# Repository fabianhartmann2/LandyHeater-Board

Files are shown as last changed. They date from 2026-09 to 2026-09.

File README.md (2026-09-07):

# LandyHeater Board

Hardwareentwicklung für das Landy-Heater-Steuergerät auf Basis des `ESP32-S3-WROOM-1U-N16R8`.

## Aktueller Stand

Revision A hat Phase 0 und Phase 1 abgeschlossen. Der Phase-2-Schaltplan wurde nach dem zurückgewiesenen rasterartigen Erstentwurf grundlegend als zusammenhängender Engineering-Schaltplan neu aufgebaut. Alle sieben A4-Seiten wurden aus dem KiCad-Export einzeln visuell geprüft; lokale Funktionsnetze werden mit sichtbaren Leitungen dargestellt. ERC, Struktur-Audit und der elektrische Vorher-/Nachher-Netzlistenvergleich sind fehlerfrei. Die normative Grundlage ist Dokumentversion 1.6. Phase 2 bleibt wegen der im Review dokumentierten Mess-, Transienten-, FPC- und Footprint-Gates sowie der noch ausstehenden ausdrücklichen Abnahme **nicht freigegeben**; Phase 3 wurde nicht begonnen.

- [Hardware-Anforderungsspezifikation Revision A](docs/Hardware-Anforderungsspezifikation_Revision_A.md)
- [Ergebnisbericht Phase 0](docs/Phase_0_KiCad-Arbeitsumgebung.md)
- [Phase 1 – Architektur und Bauteilfestlegung](docs/Phase_1_Architektur-und-Bauteilfestlegung.md)
- [Phase 2 – KiCad-Schaltplan und Review](docs/Phase_2_Schaltplanreview.md)
- [Phase 2 – Anforderungs- und Schnittstellenliste](docs/Phase_2_Anforderungs-und-Schnittstellenliste.md)
- [Phase 2 – Quellen und Rückverfolgbarkeit](docs/Phase_2_Quellen-und-Rueckverfolgbarkeit.md)
- [GPIO-Matrix Revision A](docs/GPIO-Matrix_Revision_A.md)
- [Leistungs- und Ruhestrombudget Revision A](calculations/Leistungs-und-Ruhestrombudget_Revision_A.md)
- [Phase 2 – Worst-Case-Berechnungen](calculations/Phase_2_Worst-Case-Berechnungen.md)
- [Schaltplan-PDF Phase 2](output/pdf/LandyHeater-Board-schematic-Phase2.pdf)
- [Vorläufige BOM Phase 2](output/bom/LandyHeater-Board-BOM-Phase2.csv)
- [ERC-Bericht Phase 2](output/reports/LandyHeater-Board-ERC-Phase2.rpt)
- [Netzlisten-/BOM-Audit Phase 2](output/reports/LandyHeater-Board-Audit-Phase2.txt)
- [Netzlistenvergleich vor/nach grafischer Überarbeitung](output/reports/LandyHeater-Board-Netlist-Comparison-Phase2.txt)

Die Spezifikation definiert Funktionsumfang, Schnittstellen, Versorgung, Mechanik, sichere Hardwarezustände, Layoutregeln, Fertigungsunterlagen und Abnahmetests. Die darin aufgeführten Verifikationspunkte müssen vor der Fertigungsfreigabe abgeschlossen werden.

## Phasenplan Revision A

Jede Phase wird einzeln beauftragt, geprüft und freigegeben. Mit der nächsten Phase wird erst nach ausdrücklicher Freigabe der Ergebnisse begonnen. Erkenntnisse, die Anforderungen verändern, werden zuerst in der Hardware-Anforderungsspezifikation dokumentiert.

### Phase 0 – KiCad-Arbeitsumgebung und Projektgerüst

- KiCad-10-Version und Kommandozeilenwerkzeuge prüfen und dokumentieren.
- Verzeichnisstruktur für KiCad-Quellen, lokale Symbole, Footprints, 3D-Modelle, Berechnungen und Fertigungsdaten anlegen.
- Leeres KiCad-Projekt mit vier Lagen, Revision, Titelblock und grundlegenden Netzklassen erstellen.
- Reproduzierbare Prüf- und Exportbefehle vorbereiten.

**Freigabepunkt:** Das Projekt lässt sich ohne fehlende Bibliotheken öffnen und die automatischen KiCad-Prüfwerkzeuge sind verfügbar.

**Status:** Technisch abgeschlossen und durch den Auftraggeber am 06.09.2026 mit dem Auftrag zum Beginn von Phase 1 freigegeben.

### Phase 1 – Schaltungsarchitektur und Bauteilfestlegung

- Blockschaltbild, Versorgungskonzept und Spannungsdomänen finalisieren.
- Vollständige ESP32-GPIO-Matrix einschließlich Reset-, Boot- und Deep-Sleep-Zuständen erstellen.
- Strom-, Ruhestrom-, Verlustleistungs- und USB-Lastbudget erstellen.
- Konkrete Herstellerteilenummern für aktive Bauteile, Schutzbeschaltung, Steckverbinder und FPC-Stecker auswählen.
- Footprints, Pinouts, Temperaturbereiche und PCBWay-Beschaffbarkeit vorprüfen.

**Freigabepunkt:** Architektur, GPIO-Matrix, Bauteilauswahl und Berechnungen sind nachvollziehbar dokumentiert; offene Punkte für den Schaltplan sind geschlossen oder ausdrücklich als Verifikationspunkte gekennzeichnet.

**Status:** Technisch abgeschlossen und durch den Auftraggeber am 06.09.2026 mit dem Auftrag zum Beginn von Phase 2 freigegeben.

### Phase 2 – KiCad-Schaltplan

- Hierarchischen Schaltplan für Versorgung, ESP32/USB, Display/Touch/Frontlicht, RTC, AUTOTERM, 1-Wire, Taster/LED und Diagnoseanzeige erstellen.
- Lokale Symbole und Footprint-Zuordnungen vollständig einbinden.
- Sichere Hardwarezustände, Testpunkte und Bestückungsoptionen abbilden.
- ERC durchführen und alle Warnungen entweder beheben oder schriftlich begründen.
- Schaltplan-PDF und vorläufige BOM für den Review erzeugen.

**Freigabepunkt:** Schaltplanreview abgeschlossen, ERC ohne ungeklärte Fehler und alle Hersteller-Pinouts unabhängig geprüft.

**Status:** Grafischer Neuaufbau, interner A4-Sichtreview und elektrischer Review abgeschlossen. ERC, exportierter Netzlisten-/BOM-Audit und Vorher-/Nachher-Topologievergleich sind fehlerfrei. Phase 2 ist dennoch nicht freigegeben, bis die in `docs/Phase_2_Schaltplanreview.md` aufgeführten Freigabesperren geschlossen und der Schaltplan ausdrücklich abgenommen ist.

### Phase 3 – Mechanik und Platzierung

- PCB-Kontur, Befestigungspunkte und zulässigen Bauraum festlegen.
- Display, drei FPC-Stecker, Nano-Fit-Anschlüsse, USB-C, Antennenkoax, Knopfzelle sowie BOOT-, RESET- und DIAG-Taster platzieren.
- Energiefluss-Diagnoseanzeige und gegebenenfalls zwei optionale Status-LEDs integrieren.
- Kritische Keep-outs, FPC-Biegeradien, Steck-/Entriegelungswege und Servicezugang prüfen.
- Vollständig bestücktes 3D-STEP-Modell für Gehäuse- und Kollisionsprüfung erzeugen.

**Freigabepunkt:** Platzierungs- und 3D-Review abgeschlossen; Gehäuseschnittstellen, Bedienung und Wartungszugang sind freigegeben.

### Phase 4 – Vierlagen-PCB-Layout

- Finalen PCBWay-Stackup und Netzklassen übernehmen.
- Versorgungsschutz, Buck-Regler, USB, ESP32, E-Paper-Booster und weitere Signale nach Priorität routen.
- Durchgehende GND-Referenz, Rückstrompfade, Abblockung, EMI-Abstände und thermische Reserven sicherstellen.
- DRC, ERC-Rückprüfung, Layoutchecklisten und visuellen Lagenreview durchführen.

**Freigabepunkt:** DRC ohne ungeklärte Fehler; Schaltplan, PCB, Pin-Matrix und BOM sind synchron und der Layoutreview ist dokumentiert.

### Phase 5 – PCBWay-Fertigungsfreigabe

- RS-274-X-Gerber, Excellon-Bohrdaten und gegebenenfalls ODB++/IPC-D-356 erzeugen.
- PCBWay-BOM und CPL/Centroid-Dateien mit Seite, Position und Rotation erstellen.
- Schaltplan, Bestückungszeichnungen, Fertigungszeichnung, DNP-Liste, STEP-Modell und spezielle Prozesshinweise beilegen.
- Gerber, Bohrungen, Lötstoppmaske, Pastenlagen, Silkscreen, Bauteilrotationen und Pin 1 unabhängig kontrollieren.
- Getrennte, eindeutig versionierte ZIP-Pakete für PCB-Fertigung und PCBA zusammenstellen.

**Freigabepunkt:** Manufacturing-Release-Checkliste vollständig; erst danach dürfen die fünf Prototypen bei PCBWay bestellt werden.

### Phase 6 – Inbetriebnahme der fünf Prototypen

- Sicht-, Kurzschluss- und Widerstandsprüfung vor dem ersten Einschalten.
- Versorgungsschienen mit strombegrenzten Laborquellen stufenweise prüfen.
- ESP32-Reset, Boot und USB-Programmierung verifizieren.
- Diagnoseanzeige, Deep-Sleep, RTC, Touch, Display, Frontlicht, 1-Wire und AUTOTERM in definierter Reihenfolge testen.
- Ruhestrom, Lastsprünge, Rückspeisung, Temperaturverhalten und alle Abnahmekriterien protokollieren.
- Abweichungen sammeln und Entscheidung über Nacharbeit oder Revision B treffen.

**Freigabepunkt:** Vollständiger Prüfbericht für alle fünf Prototypen und dokumentierte Entscheidung über den weiteren Einsatz.

### Geplante Endergebnisse

- editierbares KiCad-Projekt mit projektlokalen Bibliotheken,
- Schaltplan und Bestückungszeichnungen als PDF,
- vollständige BOM und GPIO-Matrix,
- PCB-Layout und 3D-STEP-Modell,
- Gerber-, Drill-, CPL-/Centroid- und PCBWay-BOM-Dateien,
- Fertigungs- und PCBA-ZIP-Pakete,
- Prüfplan und Prototypen-Prüfbericht.

## Abgrenzung Revision A

Revision A umfasst die AUTOTERM-UART-Schnittstelle, drei gemeinsam angeschlossene DS18B20-Sensoren, RTC, USB-C, externen Taster mit dimmbarer LED, eine lokale Energiefluss-Diagnoseanzeige sowie das Good-Display-E-Paper mit Touch und Frontlicht. VOTRONIC VBCS und Smart-Shunt sind für eine spätere Revision vorgemerkt.

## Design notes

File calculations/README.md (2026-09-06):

# Berechnungen

Dieses Verzeichnis nimmt die nachvollziehbaren Auslegungsnachweise auf, insbesondere Strombudget, Ruhestrombudget, Verlustleistung, Versorgungsschutz, Reglerbeschaltung, Leiterbahnbreiten, thermische Abschätzung und RTC-Backup-Laufzeit.

Berechnungen beginnen in Phase 1. Annahmen, Formelquellen, Bauteiltoleranzen und Worst-Case-Ergebnisse müssen dokumentiert werden.

Vorhanden:

- [Leistungs-, USB- und Ruhestrombudget Revision A](Leistungs-und-Ruhestrombudget_Revision_A.md)
- [Phase 2 – Worst-Case-Berechnungen Revision A](Phase_2_Worst-Case-Berechnungen.md)

Die Phase-2-Rechnung trennt nachgewiesene Grenzwerte ausdrücklich von noch nicht verifizierten Transienten-, Stabilitäts-, Thermik- und Messpunkten.

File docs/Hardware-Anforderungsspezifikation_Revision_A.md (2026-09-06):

# Landy Heater Controller – Hardware-Anforderungsspezifikation Revision A

Dokumentversion: 1.6

Stand: 2026-09-06

Status: freigegeben als normative Grundlage für den Phase-2-Schaltplan; Layout- und Fertigungsfreigabe gesperrt, solange die dokumentierten Phase-2-Gates offen sind

Änderungsstand 1.6: Ergebnisse des unabhängigen Phase-2-Schaltplanreviews eingearbeitet. Dazu gehören die korrekte LM74720-Q1-Anlauf-/Gatebeschaltung mit 18-V-VGS-Klemme, die 2,2-µH-Buckinduktivität gemäß aktueller TI-Auslegung, korrigierte Common-Anode-ESD-Array-Pinouts, galvanische Pegelentkopplung des TUSB321-Stromsignals, `BCR421UW6Q-7` als direkt PWM-fähiger Ring-LED-Treiber sowie konkrete Eingangs- und Frontlichtkondensatoren. `USB_HIGH_CURRENT` ist nach der Entkopplung active HIGH. Verbleibende Footprint-, Transienten-, FPC- und Messgates sind ausdrücklich keine stillschweigenden Annahmen.

Änderungsstand 1.5: Phase-1-Architektur, vollständige GPIO-Matrix, Leistungs-/Ruhestrombudget sowie exakte Herstellerteilenummern für die wesentlichen aktiven Bauteile, Schutzbauteile, Nano-Fit-Anschlüsse und vorläufigen FPC-Stecker festgelegt. Der 12-V-Schutz wurde auf `LM74720-Q1` mit Back-to-back-MOSFETs korrigiert, die USB-Stromerkennung und -Rückstromsperre konkretisiert und GPIO47 begründet für `AUTOTERM_OE` zugeordnet. Die mechanische FPC-Kontaktseite und das Touch-Wake-Latch bleiben messpflichtige Verifikationspunkte.

Änderungsstand 1.4: Verpflichtende, nur bei gedrücktem lokalem DIAG-Taster beziehungsweise überbrückten DIAG-Testpads aktive Energiefluss-Diagnoseanzeige für 12 V, USB, 3V3, ESP32-RUN und AUTOTERM-Anwesenheit ergänzt. Die zusätzlichen allgemeinen Status-LEDs wurden von vier auf zwei reduziert und bleiben bei GPIO- oder Platzmangel gemeinsam verzichtbar.

Änderungsstand 1.3: Systemprüfung nach Integration der Espressif-, Good-Display- und FocalTech-Herstellerangaben. GPIO45- und WROOM-1U-Keep-out-Aussagen korrigiert, USB-C-Stromfreigabe konkretisiert, Touch-/I2C-Spannungsdomäne und Deep-Sleep-Resetzustand eindeutig festgelegt, sichere E-Paper-Signalzustände ergänzt und Status-LEDs bei GPIO-Mangel als verzichtbare Komfortfunktion eingestuft.

Änderungsstand 1.2: Anforderungen der Herstellerunterlagen `GDEY029T94-FT01` Revision 1.0 und `FT6336U` Datasheet Version 1.0 für FPC-Pinout, E-Paper-Referenzschaltung, SPI-Timing, Touch-Betriebsarten, Reset-/Power-Sequenz und Frontlicht konkretisiert. Insbesondere ist Touch-Wakeup nur im FT6336U-Monitor-Modus, nicht im 55-µA-Hibernation-Modus, gefordert.

Änderungsstand 1.1: Anforderungen aus dem Espressif-Datenblatt v1.8 und den aktuellen ESP32-S3 Hardware Design Guidelines für Versorgung, Reset/Boot, USB, GPIO, Layout, Antenne und Fertigung konkretisiert.

## 1. Zweck und Verbindlichkeit

Dieses Dokument beschreibt die vollständigen Hardwareanforderungen für Revision A des Landy-Heater-Steuergeräts. Ein PCB-Designer muss daraus Schaltplan, Leiterplattenlayout, Fertigungsdaten und Bestückungsdaten erstellen können. Anwendungssoftware und proprietäre Geräteprotokolle sind nicht Teil des Auftrags.

Normative Phase-1-Anlagen sind die [Schaltungsarchitektur und Bauteilfestlegung](Phase_1_Architektur-und-Bauteilfestlegung.md), die [GPIO-Matrix Revision A](GPIO-Matrix_Revision_A.md) und das [Leistungs- und Ruhestrombudget](../calculations/Leistungs-und-Ruhestrombudget_Revision_A.md). Bei einem Widerspruch hat dieses Hauptdokument Vorrang.

Die Begriffe haben folgende Bedeutung:

- **MUSS / DARF NICHT:** verbindliche Anforderung.
- **SOLL:** verbindliches Designziel; eine Abweichung ist schriftlich zu begründen.
- **KANN:** optionale Ausführung ohne Einfluss auf die Abnahme.
- **Verifikationspunkt:** vom PCB-Designer vor der Fertigungsfreigabe zu prüfen und zu dokumentieren; keine offene Funktionsentscheidung des Auftraggebers.

Bei Widersprüchen gilt diese Rangfolge:

1. Freigegebene Änderungsmitteilung zu diesem Dokument
2. Dieses Dokument
3. Aktuelles Datenblatt, Referenzschaltung, Landpattern und Layoutvorgaben des jeweiligen Bauteilherstellers
4. Espressif Hardware Design Guidelines für den ESP32-S3 und das offizielle WROOM-1U-Landpattern
5. Bestätigter Stackup und Fertigungsregeln von PCBWay
6. Predictable Designs „PCB Layout Rules Checklist“ als zusätzliche Review-Checkliste

Wenn eine Herstellerangabe einer Anforderung dieses Dokuments technisch widerspricht, darf nicht eigenmächtig davon abgewichen werden. Der Konflikt ist vor dem Schaltplan- oder Layout-Freeze zu melden.

## 2. Produktzweck und Systemgrenze

Revision A ist ein kompaktes Bedien- und Kommunikationssteuergerät für eine AUTOTERM/Planar-Dieselstandheizung. Das Gerät:

- kommuniziert über eine 5-V-UART-Schnittstelle mit der originalen Heizungssteuerung,
- liest drei extern zusammengeschaltete DS18B20-Temperatursensoren über einen gemeinsamen 1-Wire-Bus,
- besitzt ein E-Paper-Display mit kapazitivem Touch und Frontlicht,
- besitzt einen externen Taster mit dimmbarer weißer Ringbeleuchtung,
- besitzt eine lokale, nur auf Anforderung aktive Energiefluss-Diagnoseanzeige auf dem PCB,
- besitzt eine batteriegepufferte Echtzeituhr,
- stellt WLAN über ein ESP32-S3-Modul bereit,
- wird aus einem abgesicherten 12-V-Zweitbatteriekreis oder zu Servicezwecken über USB-C versorgt.

Das Board steuert keine Glühkerze, Kraftstoffpumpe, Gebläselast oder andere Heizungsleistung direkt. Alle verbrennungs- und sicherheitsrelevanten Funktionen verbleiben in der originalen AUTOTERM-Steuerung.

## 3. Verbindliche Abgrenzung von Revision A

Revision A enthält ausdrücklich **nicht**:

- kein FireBeetle- oder anderes Entwicklungsboard,
- keine VOTRONIC-VBCS-Schnittstelle,
- keine VOTRONIC-Smart-Shunt-Schnittstelle,
- keine RS-485-Transceiver oder externen RS-485-Stecker,
- keinen CAN-Bus,
- keinen ACC-/KL15-Eingang,
- keine zusätzliche Sicherung auf dem PCB,
- keine 12-V-Last-, Relais-, High-Side- oder Open-Drain-Ausgänge,
- keine eigene PCB-Antenne und keine vom PCB-Designer zu routende HF-Leitung,
- kein separates Display-Bedienteil und keine Verlängerung der Display-FPCs,
- keine USB-PD-Funktion und keinen USB-UART-Wandler.

VBCS und Smart-Shunt sind nur als mögliche Funktionen einer späteren Leiterplattenrevision dokumentiert. Revision A muss dafür weder Schaltungsteile noch Steckverbinder oder reservierte GPIOs enthalten.

## 4. Einsatzbedingungen und Mechanik

### 4.1 Einbauort und Umwelt

- Einbauort ist die Cubby Box in der Mittelkonsole eines Land Rover.
- Der Einbauort ist vor direktem Spritzwasser und regulärer Kondensation geschützt.
- Eine IP-Zertifizierung und Schutzlackierung sind für Revision A nicht gefordert.
- Das 3D-gedruckte Gehäuse muss gegen versehentlich verschüttete Flüssigkeit schützen und den Kabelzug aufnehmen.
- Aktive Halbleiter und sonstige kritische Bauteile sollen, soweit verfügbar, mindestens für −40 °C bis +85 °C spezifiziert sein.
- Die Temperaturgrenzen des Displays nach Abschnitt 10 begrenzen die Gesamtbaugruppe unabhängig von den übrigen Bauteilen.
- Steckverbinder, Knopfzellenhalter und schwere Bauteile müssen für Fahrzeugvibration mechanisch gesichert sein.

### 4.2 Bauraum und Anordnung

- Maximaler Bauraum der kompletten Display-/PCB-Einheit: **100 mm × 50 mm × 35 mm**.
- Gegenstecker, herausgeführte Kabel und deren Biegeradien sind vom 100-mm-×-50-mm-Flächenlimit ausgenommen.
- Zielgröße des PCB: höchstens **98 mm × 48 mm**. Eine Überschreitung ist vor dem Layout schriftlich freizugeben.
- Das Display liegt auf der Bedien-/Vorderseite.
- Der überwiegende Teil der Elektronik darf auf der Rückseite bestückt werden. Beidseitige Bestückung ist zulässig und wird erwartet.
- USB-C muss an einer seitlichen Gehäusekante von außen erreichbar sein.
- Die Nano-Fit-Anschlüsse müssen auf der dem Display gegenüberliegenden Anschluss-/Rückseite angeordnet und im geöffneten Gehäuse entriegelbar sein.
- Antennenstecker, Knopfzelle sowie BOOT-, RESET- und DIAG-Taster müssen für Montage und Service zugänglich bleiben.
- Das Gehäuse wird nach dem finalen PCB als 3D-Druckteil konstruiert. PCB und Gehäuse müssen mindestens drei mechanisch belastbare Befestigungspunkte besitzen; Lage und Art werden beim Platzierungsreview gemeinsam festgelegt.
- Die drei Display-FPCs dürfen weder als mechanische Halterung noch als Zugentlastung dienen.

## 5. Versorgungskonzept

### 5.1 12-V-Eingang

- Quelle ist ausschließlich ein 12-V-Zweitbatterie-Verbraucherkreis.
- Normaler Betriebsbereich am Boardeingang: **10 V bis 14 V DC**.
- Ein vorgeschalteter Batteriewächter trennt die Lasten bei zu niedrigem Ladezustand. Eine eigene Unterspannungsabschaltung zum Batterieschutz ist keine Aufgabe dieses Boards.
- Die dedizierte Zuleitung ist außerhalb des Boards mit **1 A** abgesichert und verwendet **0,5 mm²** Leiterquerschnitt.
- Auf dem Board darf keine weitere Sicherung vorgesehen werden.
- Dauerbetrieb an 24 V und 24-V-Fremdstart sind keine Anforderungen.
- Das Board muss trotzdem gegen Verpolung, ESD sowie typische lokale Schalt- und Leitungstransienten eines 12-V-Fahrzeugnetzes geschützt sein.
- Verpolung mit −14 V am Eingang für mindestens 60 s darf keinen Schaden verursachen.
- Der Schutz wird mit `LM74720QDRRRQ1` und dem dualen 60-V-Back-to-back-N-MOSFET `IPG20N06S4L-26` realisiert. Diese Topologie muss Verpolschutz, Rückstromsperre und einstellbare Überspannungsabschaltung gemeinsam bereitstellen. `RTN` des LM74720-Q1 bleibt gemäß Herstellerforderung elektrisch offen; eine Verbindung mit GND ist unzulässig.
- Die Eingangs-TVS ist `TPSMB18CA-VR`, bidirektional, 18 V, 600 W, AEC-Q101. Eine andere TVS darf nur nach vollständiger Neuberechnung freigegeben werden.
- Eine TVS-Diode und ein gedämpfter Eingangs-/EMI-Filter sind vorzusehen. TVS-Klemmspannung, Toleranzen und parasitäre Überschwinger müssen unterhalb der zulässigen Transientenspannung aller nachfolgenden Bauteile bleiben und rechnerisch dokumentiert werden.
- Es ist keine formale ISO-7637- oder ISO-16750-Zertifizierung für Revision A gefordert. Das gewählte Schutzprofil und seine Grenzen müssen dennoch im Designbericht ausdrücklich genannt werden.

### 5.2 USB-C-Versorgung

- USB-C muss das komplette Logikboard ohne anliegende 12 V versorgen können, einschließlich ESP32, Display, Touch, RTC, 1-Wire-Sensorversorgung und Frontlicht.
- Für uneingeschränkten USB-Betrieb ist eine 5-V-USB-C-Quelle erforderlich, die über CC mindestens **1,5 A** ankündigt. Die Auslegung des Boards darf davon höchstens 1 A verwenden.
- Das Board arbeitet als USB-2.0-Gerät/Sink ohne USB-PD. USB-C-Stecker ist `USB4105-GF-A-120`.
- CC1 und CC2 erhalten jeweils eine normgerechte Rd-Terminierung. Diese darf durch separate Widerstände oder durch die nachgewiesen normgerechte interne Terminierung des gewählten Type-C-Sink-Controllers realisiert werden; eine Doppelterminierung ist unzulässig.
- `TUSB321AIRWBR` arbeitet als UFP/Sink, stellt die normgerechten Rd-Terminierungen bereit und wertet die angebotene Stromstufe aus. Separate Rd-Widerstände dürfen nicht parallel ergänzt werden. `OUT1` und `OUT2` erhalten ihre mindestens 200-kΩ-Pull-ups ausschließlich aus `USB_VBUS`. `OUT1` wird über einen `2N7002KQ-13` in die 3,3-V-Domäne entkoppelt und liegt am ESP32 als `USB_HIGH_CURRENT`: HIGH bedeutet mindestens 1,5 A angekündigt **oder USB nicht vorhanden**, LOW bedeutet USB vorhanden mit Default Current. `OUT2` erhält nur einen 5-V-Domänen-Testpunkt. Damit darf bei lediglich angekündigtem USB-Default-Current natives USB-Flashing zuverlässig möglich sein; Frontlicht, Sensorversorgung und andere nicht notwendige Lasten sind softwaregestützt zu sperren. Im gleichzeitigen 12-V-/USB-Betrieb ist ein LOW konservativ und darf die Zusatzlasten ebenfalls sperren.
- Das Ergebnis der CC-Stromerkennung muss dem ESP32 zur Verfügung stehen oder die Lastbegrenzung muss unabhängig vom ESP32 hardwareseitig erfolgen. Ruhestrom, Startverhalten ohne laufende Firmware und GPIO-Bedarf der gewählten Lösung sind zu dokumentieren.
- `TPS259470LRPWR` übernimmt strombegrenztes Einschalten, Fehlerstrombegrenzung und echte Rückstromsperre des USB-Pfads; `RILM` wird nominal auf 1 A ausgelegt. Da TI die ±10-%-Genauigkeit erst oberhalb 1 A spezifiziert, wird die höchstens 1 A betragende normale Boardaufnahme durch das Lastbudget und den Abnahmetest, nicht durch eine vermeintlich präzise eFuse-Abschaltschwelle, nachgewiesen. USB-VBUS erhält `ESD5Z5.0T1G`, D+/D− erhalten den kapazitätsarmen `TPD2EUSB30DRTR`; die VBUS-Eingangskapazität muss USB-konform sein.
- In D− und D+ ist jeweils unmittelbar am ESP32-Modul ein bestückbarer Serienwiderstand vorzusehen. Anfangswert: 22 Ω oder 33 Ω gemäß Espressif; der endgültige Wert wird nach Signalintegritätsprüfung festgelegt.
- Hinter den Serienwiderständen ist je Leitung ein optionaler, standardmäßig nicht bestückter Kondensator-Footprint nach GND vorzusehen. ESD-Schutz und optionale Kondensatoren müssen so kapazitätsarm gewählt werden, dass das USB-Full-Speed-Signal nicht unzulässig belastet wird.
- USB-Testpads sind nur zulässig, wenn sie ohne relevante Stichleitung in den Hauptpfad integriert werden.
- 12 V dürfen unter keinen Betriebs- oder Fehlerbedingungen auf USB-VBUS gelangen.
- USB-VBUS darf nicht in den 12-V-Fahrzeugkreis oder in `AUTOTERM_5V` zurückspeisen.

### 5.3 Power-OR und 3,3-V-Hauptversorgung

Die verbindliche Funktionskette lautet:

`J1 B+ -> Verpol-/Transientenschutz -> Filter -> ideal entkoppelter 12-V-Pfad -> VIN_SYS`

`USB-C 5 V -> Strom-/Rückstromschutz -> ideal entkoppelter USB-Pfad -> VIN_SYS`

`VIN_SYS -> Low-IQ-Buck 3,3 V / 2 A -> 3V3_CORE`

`3V3_CORE -> Low-IQ-LDO nominal 3,0 V -> 3V0_TOUCH_AON`

- Bei gleichzeitigem Anschluss von 12 V und USB muss der 12-V-Pfad Vorrang haben.
- Beide Quellen müssen gegeneinander rückstromgesperrt sein.
- Der 3,3-V-Regler wird mit dem automotive-qualifizierten `LMR43620MSC3RPERQ1`, feste 3,3 V, 2 A und 2,2 MHz, realisiert.
- Auto-/PFM-Leichtlastbetrieb muss möglich sein. Ein dauerhaft erzwungener FPWM-Modus ist wegen des Ruhestromziels nicht zulässig.
- Referenzschaltung, Bauteilberechnung, Hot-Loop und Layout des Herstellers sind einzuhalten.
- `3V3_CORE` muss bei zulässigen Quellen und Lastsprüngen zwischen 3,0 V und 3,6 V bleiben. Wi-Fi-Sendespitzen dürfen keinen Brownout oder unbeabsichtigten Reset verursachen.
- Die 3,3-V-Versorgung muss am ESP32-Modul mindestens 0,5 A liefern können. Der festgelegte 2-A-Regler erfüllt diese Mindestanforderung mit Reserve für Wi-Fi-Sendespitzen und Peripherie.
- Direkt am 3,3-V-Pin des WROOM-1U sind mindestens **22 µF plus 100 nF** gemäß Espressif-Peripherieschaltung vorzusehen. Leiterwege zu Modul und GND müssen kurz und niederinduktiv sein.
- Bei der 22-µF-Kapazität sind DC-Bias, Temperatur, Alterung und Bauteiltoleranz zu berücksichtigen. Die effektive Kapazität bei 3,3 V muss im Designbericht dokumentiert werden.
- Am Eintritt von `3V3_CORE` in den ESP32-Bereich ist zusätzlich mindestens 10 µF wirksame Bulk-Kapazität vorzusehen, sofern diese Funktion nicht bereits nachweislich durch die vorgenannten 22 µF erfüllt wird.
- Die Spannung am Modul darf den absoluten Bereich −0,3 V bis 3,6 V niemals überschreiten; der normale Betrieb bleibt auf 3,0 V bis 3,6 V begrenzt.

### 5.4 Versorgungsdomänen

Folgende Netze sind getrennt und eindeutig zu benennen:

- `3V3_CORE`: ESP32, RV-3028-Hauptversorgung und dauerhaft benötigte 3,3-V-Logik. Die I2C-Pull-ups liegen nicht an diesem Netz.
- `3V0_TOUCH_AON`: separate, rauscharme und ruhestromarme nominelle 3,0-V-Versorgung über `TPS7A0230PDBVR` für FT6336U und den gemeinsamen I2C-Bus. Am Touch-FPC muss sie unter allen Regler-, Last- und Temperaturtoleranzen zwischen 2,8 V und 3,3 V bleiben. Die I2C-Pull-ups werden ausschließlich an dieses Netz angeschlossen. ESP32- und RV-3028-Eingangspegel müssen bei den Worst-Case-Spannungen nachweislich kompatibel sein. Normalbetrieb, Komfort-Standby und Minimal-Standby nutzen diese Versorgung; im Minimal-Standby wird der FT6336U in Hibernation versetzt. Vollständiges Abschalten ist nur mit Power-off-Isolation aller Touch-Signale und Einhaltung der Reset-/Power-Sequenz aus Abschnitt 10.3 zulässig.
- `3V3_DISPLAY_SW`: E-Paper-Logik und Booster-Beschaltung über `TPS22919QDCKRQ1`; im Deep-Sleep aus.
- `3V3_SENSOR_SW`: externe DS18B20-Versorgung über den strombegrenzenden `TPS22945DCKR`; im Deep-Sleep aus.
- `VIN_SYS`: strombegrenzte Versorgung der externen weißen Taster-LED, damit sie sowohl bei 12-V- als auch bei USB-Versorgung betrieben werden kann.
- `AUTOTERM_5V`: ausschließlich von der Heizung bereitgestellte Versorgung/Referenz der 5-V-Seite des UART-Pegelwandlers; keine Verbindung zu USB-VBUS oder `VIN_SYS`.
- `RTC_VBACKUP`: Backupversorgung ausschließlich aus der Knopfzelle.

Schaltbare Domänen dürfen bei ausgeschaltetem Zustand weder über GPIO-Schutzdioden noch über Bus-Pull-ups rückgespeist werden.

### 5.5 Betriebszustände und Ruhestrom

| Zustand | ESP32/WLAN | Display/Frontlicht | Touch | Sensor/UART/LEDs |
|---|---|---|---|---|
| Normalbetrieb | aktiv, WLAN typischerweise dauerhaft aktiv | nach Softwarebedarf | aktiv | nach Softwarebedarf |
| Komfort-Standby | ESP32 Deep-Sleep, WLAN aus | aus | FT6336U Monitor-Modus für Touch-Wakeup | aus |
| Minimal-Standby | ESP32 Deep-Sleep, WLAN aus | aus | FT6336U Hibernation oder vollständig isoliert abgeschaltet; kein Touch-Wakeup | aus |

- Wake-Quellen im Komfort-Standby sind der externe Taster und Touch-INT.
- Im Minimal-Standby ist mindestens der externe Taster als Wake-Quelle verfügbar.
- Der typische Strom des FT6336U beträgt laut Datenblatt bei 2,8 V und 25 °C etwa 220 µA im Monitor-Modus und 55 µA im Sleep-/Hibernation-Modus. Diese Werte sind typische Werte ohne garantierte Obergrenze und dürfen nicht ohne Reserve als Worst-Case-Budget verwendet werden.
- Ziel für den gesamten Strom aus dem 12-V-Eingang im Komfort-Standby: **< 0,5 mA bei 12 V**.
- Der Minimal-Standby muss einen messbar niedrigeren Strom erreichen; es wird kein fester Grenzwert vorgegeben.
- Keine LED darf im Reset, beim Booten oder im Deep-Sleep durch einen undefinierten GPIO-Zustand leuchten.
- Für jedes aktive Bauteil ist ein Worst-Case-Ruhestrombudget einschließlich Pull-ups, Schutzbauteilleckströmen und Reglerstrom zu erstellen.

## 6. Mikrocontroller, Programmierung und Funk

- Verbindliches Modul für Revision A: **`ESP32-S3-WROOM-1U-N16R8`**.
- Speicher: 16 MiB Quad-SPI-Flash und 8 MiB Octal-SPI-PSRAM.
- PSRAM-ECC muss in der Firmware aktiviert und am Prototyp geprüft werden. Damit reduziert sich der nutzbare PSRAM um 1/16; der laut Espressif mögliche maximale Umgebungstemperaturbereich des R8-Moduls steigt von +65 °C auf +85 °C.
- `ESP32-S3-WROOM-1U-N16R16VA` ist für Revision A **kein freigegebener Drop-in-Ersatz**. Bei dieser Variante arbeiten GPIO47/48 mit 1,8 V.
- GPIO35, GPIO36 und GPIO37 sind durch das Octal-PSRAM belegt und dürfen nicht verwendet werden.
- GPIO19 und GPIO20 sind für natives USB D−/D+ reserviert.
- GPIO0 dient ausschließlich der BOOT-Funktion. GPIO3, GPIO45 und GPIO46 dürfen nicht für externe Schnittstellen, Wake-Signale oder Signale mit problematischem Einschaltpegel verwendet werden.
- GPIO0 erhält einen externen 10-kΩ-Pull-up nach 3,3 V und den BOOT-Taster nach GND. An GPIO0 darf kein großer Kondensator vorgesehen werden.
- Beim N16R8 ist VDD_SPI für das integrierte PSRAM werkseitig per eFuse auf 3,3 V festgelegt; der GPIO45-Pegel beeinflusst VDD_SPI bei dieser Modulvariante nicht. GPIO45 bleibt dennoch wegen seiner Strapping-Funktion unbenutzt und erhält keinen externen Pull-up. Auch GPIO46 darf keinen externen Pull-up erhalten und muss für den gemeinsamen USB-/UART-Download-Boot LOW bleiben können.
- Die Strapping-Pegel müssen mindestens 3 ms nach dem Anstieg von `CHIP_PU/EN` unverändert gültig bleiben.
- eFuses für VDD_SPI, Bootmodus, ROM-Ausgabe, USB-JTAG oder JTAG dürfen während Fertigung und Prototypentest nicht programmiert werden, sofern dies nicht ausdrücklich dokumentiert und freigegeben wurde.
- GPIO47 ist nach Abschluss der Pinbilanz für `AUTOTERM_OE` festgelegt, weil dort die sichere Abschaltung der externen TX-Leitung Vorrang besitzt. GPIO48 bleibt freie Reserve.
- Alle Pinzuordnungen sind in der normativen [GPIO-Matrix Revision A](GPIO-Matrix_Revision_A.md) mit Modulpad, Resetpegel, Pull-up/-down, Wake-Fähigkeit, Versorgungsdomäne und bekanntem Einschaltimpuls dokumentiert.
- Es wird natives ESP32-S3-USB für Flashen, REPL und Diagnose verwendet.
- Ein lokaler, beschrifteter `RESET`-Taster muss `CHIP_PU/EN` gegen GND ziehen.
- Ein lokaler, beschrifteter `BOOT`-Taster muss GPIO0 gegen GND ziehen.
- `CHIP_PU/EN` darf nicht floaten. Als Ausgangspunkt sind 10 kΩ Pull-up nach 3,3 V und 1 µF nach GND gemäß Espressif vorzusehen.
- Vor dem Anstieg von `CHIP_PU/EN` müssen die 3,3-V-Modulversorgung und die internen Versorgungsschienen mindestens 50 µs stabil sein. Ein Hardware-Reset muss EN mindestens 50 µs unter dem zulässigen LOW-Pegel halten.
- Wegen Fahrzeugversorgung, vorgeschaltetem Relais und Umschaltung zwischen USB und 12 V wird `TPS3808G33QDBVRQ1` als Low-IQ-Spannungswächter mit Open-Drain-Reset eingesetzt. Sein Ausgang und der RESET-Taster ziehen `CHIP_PU/EN` nach GND. Die Verzögerung wird in Phase 2 mit mindestens 50 µs sicherer Versorgungsvorlaufzeit und nominal etwa 20 ms Zielwert berechnet.
- U0TXD/U0RXD sowie GND und 3,3 V sollen als beschriftete Testpads erreichbar sein, dürfen aber keinen zusätzlichen Außenstecker erfordern. U0TXD erhält nahe am Modul den von Espressif empfohlenen 499-Ω-Serienwiderstand.
- Das Modul wird über seinen integrierten U.FL-/MHF-I-kompatiblen Antennenanschluss mit einer externen 2,4-GHz-/50-Ω-WLAN-Antenne und etwa 10 cm Koaxialkabel verbunden.
- Der Antennengewinn darf 2,33 dBi nicht überschreiten, sofern nicht eine gesonderte regulatorische/EMV-Bewertung eine andere Antenne freigibt.
- Auf dem Mainboard wird keine HF-Leitung zwischen Modul und Antenne geroutet.
- Die Antenne muss bei aktivem Funk angeschlossen sein. Koaxstecker und Kabel dürfen bei Gehäusemontage nicht auf Zug belastet werden.
- Antennenreichweite und Datendurchsatz müssen mit der tatsächlichen Antenne, dem 10-cm-Koaxkabel, dem finalen Gehäuse und am vorgesehenen Einbauort geprüft werden.

## 7. Steckverbinder und Kabelbaum

### 7.1 Allgemeine Anforderungen

- Für alle drahtgebundenen Außenanschlüsse ist Molex Nano-Fit oder eine schriftlich freigegebene gleichwertige verriegelnde Steckverbindung zu verwenden.
- Auf dem PCB dürfen keine AUTOTERM- oder sonstigen Fremdgeräte-Originalstecker verwendet werden. Die Anpassung an Originalstecker erfolgt ausschließlich im Kabelbaum beziehungsweise über Adapterkabel.
- PCB-Header müssen eine positive Verriegelung und eine mechanisch robuste PCB-Befestigung besitzen. THT-Anschlüsse oder SMT-Ausführungen mit ausreichenden Metallhalteklammern sind zulässig.
- Für Kleinsignale sind vergoldete Kontakte zu bevorzugen.
- Sekundärverriegelung/TPA ist zu verwenden, sofern für die gewählte Ausführung verfügbar.
- Elektrisch unterschiedliche Schnittstellen dürfen nicht mit frei vertauschbaren Gegensteckern ausgeführt werden. Unterschiedliche Polzahlen, Gehäuseformen oder echte mechanische Codierungen sind zu verwenden; Farbe oder Beschriftung allein genügen nicht.
- Die 4-poligen Anschlüsse für AUTOTERM und Taster/LED müssen mechanisch nicht miteinander steckbar sein. Falls Nano-Fit dafür keine sichere Codierung bietet, muss einer der beiden Anschlüsse eine andere Polzahl oder Bauform erhalten; unbenutzte Pins bleiben dann `NC`.
- Pin 1, Signalname und Gegensteckerorientierung sind in Schaltplan, Silkscreen und Kabelbaumzeichnung eindeutig zu kennzeichnen.
- Kabelzug wird im Gehäuse abgefangen, nicht über den PCB-Header.
- Jede Leitung, die das Gehäuse verlässt, erhält am Steckverbinder einen zur Schnittstelle passenden ESD-/Transientenschutz.

### 7.2 Verbindliche elektrische Pinbelegung

Die Nummerierung ist elektrisch verbindlich. Die mechanische Draufsicht muss in der Kabelbaumzeichnung zusätzlich dargestellt werden.

| Anschluss | Pin | Signal | Beschreibung |
|---|---:|---|---|
| J1 Versorgung, 2-polig | 1 | `BATT_12V_IN` | extern mit 1 A abgesicherter Plusleiter |
|  | 2 | `GND` | Zweitbatterie-Minus/Masse |
| J2 AUTOTERM, 4-polig | 1 | `AUTOTERM_5V` | 5-V-Versorgung/Referenz von der Heizung |
|  | 2 | `GND` | gemeinsame Signalmasse |
|  | 3 | `CTRL_TX_TO_HEATER` | Ausgang des Controllers zur Heizung |
|  | 4 | `CTRL_RX_FROM_HEATER` | Eingang des Controllers von der Heizung |
| J3 1-Wire, 3-polig | 1 | `3V3_SENSOR_SW` | geschaltete, strombegrenzte Sensorversorgung |
|  | 2 | `1WIRE_DQ` | gemeinsame Datenleitung der drei Sensoren |
|  | 3 | `GND` | Sensormasse |
| J4 Taster/LED, elektrisch 4-polig | 1 | `BUTTON_N` | Active-Low-Tastereingang |
|  | 2 | `GND` | Tastermasse; verdrillt mit Pin 1 |
|  | 3 | `LED_CC_PLUS` | strombegrenzter Plusleiter für weiße LED |
|  | 4 | `LED_PWM_MINUS` | PWM-fähiger Low-Side-Rückleiter; verdrillt mit Pin 3 |

Für J4 darf zur sicheren mechanischen Unterscheidung ein 5-poliges Gehäuse verwendet werden; der zusätzliche Pin bleibt unbestückt beziehungsweise `NC` und wird nicht für eine spätere Funktion reserviert.

### 7.3 Verbindliche Nano-Fit-Teilenummern

| Anschluss | rechtwinkliger THT-Board-Header, schwarz, Gold | Gegenstecker, schwarz | TPA | Kontakt |
|---|---|---|---|---|
| J1, 2-polig | `1053131302` | `1053071202` | `1053251002` | `1053002300`, 22–20 AWG, 0,76 µm Gold |
| J2, 4-polig | `1053131304` | `1053071204` | `1053251004` | `1053001300`, 26–24 AWG, 0,76 µm Gold |
| J3, 3-polig | `1053131303` | `1053071203` | `1053251003` | `1053001300`, 26–24 AWG, 0,76 µm Gold |
| J4, 5-polig, Pin 5 NC | `1053131305` | `1053071205` | `1053251005` | `1053001300`, 26–24 AWG, 0,76 µm Gold |

Falls der reale J3-Sensorkabelquerschnitt größer als 24 AWG ist, ist dort ebenfalls `1053002300` zu verwenden. Goldkontakte dürfen nur mit Goldkontakten gepaart werden. Die PCBWay-Handbestückung der THT-Header und die Crimpwerkzeuge werden vor Fertigungsfreigabe bestätigt.

## 8. AUTOTERM-UART

- Schnittstelle: Full-Duplex-UART mit 5-V-Logik und gemeinsamer Masse.
- Kabellänge zwischen Board und Heizung: etwa 0,3 m bis 0,5 m.
- Die Pegelwandlung wird mit `TXU0202QDCURQ1` realisiert. Die beiden Kanäle arbeiten fest in Gegenrichtung.
- VCCA wird aus 3,3 V versorgt; VCCB ausschließlich aus `AUTOTERM_5V`.
- Die Heizung versorgt weder das Mainboard noch externe Lasten. USB-VBUS darf `AUTOTERM_5V` nicht ersetzen.
- OE erhält einen Hardware-Pull-down. `CTRL_TX_TO_HEATER` muss bei Reset, Boot, Deep-Sleep, ausgeschaltetem VCCB und vor expliziter Softwarefreigabe hochohmig bleiben.
- Die VCC-Isolation-/Ioff-Funktion muss Rückspeisung bei fehlender Heizungsversorgung verhindern.
- Es ist keine Softwareerkennung von `AUTOTERM_5V` erforderlich. Fehlt diese Spannung, bleibt nur die 5-V-Seite des Pegelwandlers funktionslos; das restliche Board muss über 12 V oder USB normal arbeiten.
- `AUTOTERM_5V` erhält lokale Strombegrenzung, Filterung, ESD-Schutz und Abblockung. Als strombegrenzender Lastschalter wird ein weiterer `TPS22945DCKR` verwendet, sofern seine Spannungsabfallprüfung in Phase 2 bestanden wird; die 5-V-Signalleitungen erhalten `PESD5V2S2UT-Q`.
- TX und RX erhalten angemessene Serienwiderstände und niederkapazitiven Schutz. Die Werte dürfen das UART-Timing nicht beeinträchtigen.
- Testpunkte sind auf beiden Logikseiten für TX und RX sowie für `AUTOTERM_5V`, 3,3 V und GND vorzusehen.

## 9. 1-Wire / DS18B20

- Es gibt genau einen 3-poligen 1-Wire-Anschluss am Board.
- Drei DS18B20 sind außerhalb des Boards bereits parallel auf Versorgung, Daten und GND zusammengeführt.
- Die drei Sensorleitungen sind jeweils etwa 2 m bis 5 m lang.
- Betrieb ist ausschließlich dreidrahtig mit 3,3-V-Versorgung; parasitäre Versorgung ist nicht vorgesehen.
- `1WIRE_DQ` wird direkt mit **GPIO4** des ESP32-S3 verbunden, entsprechend dem bestehenden und elektrisch geprüften Software-/Testaufbau.
- Standard-Pull-up: 4,7 kΩ von `1WIRE_DQ` nach `3V3_SENSOR_SW`.
- Zwischen Steckverbinder und GPIO ist ein bestückter 0-Ω-Serienwiderstand vorzusehen. Footprint und Testpunkt müssen eine spätere Anpassung zur Dämpfung ohne PCB-Änderung erlauben.
- Am Steckverbinder ist `PESD3V3S2UT-Q` oder ein nachweislich gleichwertiger niederkapazitiver AEC-Q101-Schutz vorzusehen. Zusätzliche Kapazität auf DQ muss klein bleiben.
- `3V3_SENSOR_SW` muss im Deep-Sleep abschaltbar und gegen Kurzschluss beziehungsweise übermäßigen Kabelstrom begrenzt sein. Ein externer Kurzschluss darf `3V3_CORE` nicht zusammenbrechen lassen.
- Die bewährte gemeinsame Bus-Topologie darf in Revision A nicht durch Multiplexer oder einzeln geschaltete Sensorzweige ersetzt werden.
- Im Kabelbaum sollen `1WIRE_DQ` und GND gemeinsam geführt werden.

## 10. Display, Touch und Frontlicht

### 10.1 Verbindliches Display

- Modell: **Good Display `GDEY029T94-FT01`**, komplette werkseitig verbundene Display-/Touch-/Frontlicht-Baugruppe.
- Normative Herstellerunterlagen für diesen Abschnitt sind die [Good-Display-Spezifikation `GDEY029T94-FT01`, Revision 1.0](https://v4.cecdn.yun300.cn/100001_1909185148/GDEY029T94-FT01.pdf) und das darin referenzierte [FocalTech-Datenblatt `FT6336U`, Version 1.0](https://v4.cecdn.yun300.cn/100001_1909185148/FT6336U-DataSheet-V1.0.pdf). Verwendet wurde der von Good Display am 18.11.2025 bereitgestellte Stand der Display-Spezifikation. Bei einer neueren Dokumentrevision ist vor Übernahme eine Änderungsprüfung erforderlich.
- Anzeige: 2,9 Zoll, monochrom, 296 × 128 Pixel, Treiber `SSD1680Z8`, 4-Draht-SPI.
- Außenmaß des Moduls: 79,00 mm × 36,70 mm × 2,15 mm.
- Aktive Fläche: 66,896 mm × 29,056 mm.
- Das Display wird über seine originalen FPCs direkt mit der Hauptplatine verbunden. Verlängerungskabel sind nicht zulässig.
- Es sind drei separate FPC-Steckverbinder vorzusehen: 24-polig/0,5 mm für E-Paper, 6-polig/0,5 mm für Touch und 6-polig/0,5 mm für Frontlicht. Die Herstellerzeichnung nennt für alle drei FPC-Enden 0,30 mm ± 0,03 mm Dicke.
- Als Phase-1-Baseline sind ein Hirose `FH12-24S-0.5SH(55)` und zwei `FH12-6S-0.5SH(55)` vorgesehen: 0,5-mm-Raster, Bottom-Contact und 0,30-mm-FPC. Die exakte Kontaktseite bleibt bis zur Prüfung eines Originaldisplays vorläufig; falls das Muster Top-Contact erfordert, werden Stecker-MPN und Footprint vor Layout-Freeze geändert. Pinfolge, Raster und Kontaktseite werden verbindlich aus der aktuellen Herstellerzeichnung und dem Muster übernommen. Steckverbinderhöhe, FPC-Austrittsrichtung und mechanische Passung werden im 3D-Modell festgelegt.
- Good Display weist darauf hin, dass Touch- und Frontlicht-FPC in umgekehrter Orientierung angeschlossen werden. Diese Angabe darf nicht aus einer Produktabbildung interpretiert werden; maßgeblich sind aktuelle Zeichnung, Datenblatt und physisches Muster.
- Die Steckverbinder sind unmittelbar an den FPC-Austritten zu platzieren. Mindestbiegeradius, Entriegelungsweg und beschädigungsfreie Demontage sind im 3D-Modell nachzuweisen.
- Die Pin-1-Ansicht der Herstellerzeichnung darf im Footprint nicht gespiegelt werden. Schaltplan, PCB-Footprint, 3D-Modell und Bestückungszeichnung müssen dieselbe Kontaktseitenansicht verwenden.

### 10.2 E-Paper-Ansteuerung

- Benötigte MCU-Signale: `EPD_SCLK`, `EPD_SDIO/MOSI`, `EPD_CS_N`, `EPD_DC`, `EPD_RESET_N`, `EPD_BUSY`. Es gibt keine separate MISO-Leitung; FPC-Pin 14 ist im Lesebetrieb bidirektional.
- Der 24-polige E-Paper-FPC wird elektrisch wie folgt belegt:

| Pin | Herstellername | Verbindliche Beschaltung |
|---:|---|---|
| 1 | `NC` | offen lassen; nicht mit Pin 4 verbinden |
| 2 | `GDR` | Gate des externen Booster-MOSFET gemäß Referenzschaltung |
| 3 | `RESE` | Strommess-/Regelpfad mit 2,2 Ω und 1 MΩ gemäß Referenzschaltung |
| 4 | `NC` | offen lassen; nicht mit Pin 1 verbinden |
| 5 | `VSH2` | 1 µF/25 V nach GND gemäß Referenzschaltung |
| 6 | `TSCL` | unbenutzte I2C-Masterschnittstelle für einen externen digitalen Temperatursensor; offen lassen |
| 7 | `TSDA` | unbenutzte I2C-Masterschnittstelle für einen externen digitalen Temperatursensor; offen lassen |
| 8 | `BS1` | fest LOW/GND für 4-Draht-SPI |
| 9 | `BUSY` | `EPD_BUSY` zum ESP32; HIGH bedeutet beschäftigt |
| 10 | `RES#` | `EPD_RESET_N` zum ESP32; active LOW |
| 11 | `D/C#` | `EPD_DC`; LOW = Befehl, HIGH = Daten |
| 12 | `CS#` | `EPD_CS_N`; active LOW |
| 13 | `SCL` | `EPD_SCLK` |
| 14 | `SDA` | `EPD_SDIO/MOSI` |
| 15 | `VDDIO` | mit FPC-Pin 16/`VCI` an `3V3_DISPLAY_SW` |
| 16 | `VCI` | `3V3_DISPLAY_SW` |
| 17 | `VSS` | GND |
| 18 | `VDD` | 1 µF/25 V nach GND gemäß Referenzschaltung; nicht extern speisen |
| 19 | `VPP` | Testpin; offen lassen |
| 20 | `VSH1` | Booster-Kondensatornetz gemäß Referenzschaltung |
| 21 | `VGH` | Booster-Kondensatornetz `PREVGH` gemäß Referenzschaltung |
| 22 | `VSL` | Booster-Kondensatornetz gemäß Referenzschaltung |
| 23 | `VGL` | Booster-Kondensatornetz `PREVGL` gemäß Referenzschaltung |
| 24 | `VCOM` | Booster-Kondensatornetz gemäß Referenzschaltung |

- `VCI` und `VDDIO` haben laut Display-Spezifikation einen Betriebsbereich von 2,2 V bis 3,7 V; beide werden gemeinsam aus `3V3_DISPLAY_SW` gespeist. Die absoluten 4,0-V- beziehungsweise E/A-Grenzen dürfen auch bei Einschalt- und Abschaltvorgängen nicht verletzt werden.
- Die SSD1680-Booster-/Ladungspumpenbeschaltung muss exakt aus Kapitel 12 der oben verlinkten Spezifikation des konkret beschafften `GDEY029T94-FT01` übernommen werden. Pinfolge, Bauteilwerte, Polaritäten und Spannungsfestigkeiten dürfen nicht von einem ähnlich benannten Panel übernommen werden.
- Die Referenzschaltung fordert insbesondere eine 47-µH-Induktivität mit 500-mA-Eignung, drei `MBR0530`-Dioden oder vollständig gleichwertige Typen, einen `Si1308EDL`-MOSFET oder vollständig gleichwertigen Typ, 1 MΩ und 2,2 Ω mit 1 % sowie X5R-/X7R-Kondensatoren in 0603/0805 mit mindestens 25 V. Gleichwertigkeit ist gegen alle in der Hersteller-Tabelle genannten Grenzwerte nachzuweisen.
- Für Revision A sind `SI1308EDL-T1-GE3` und drei `MBR0530T1G` festgelegt. Ein Ersatz erfordert weiterhin den vollständigen Gleichwertigkeitsnachweis gegen die Good-Display-Tabelle.
- Der Booster-Hot-Loop, `GDR`, `RESE`, Induktivität, MOSFET, Dioden und zugehörige Kondensatoren sind kompakt und abseits von Touch, RTC, USB und Antennenkoax zu platzieren. Die Hochspannungsnetze dürfen nicht unter Touch-FPC oder Touch-Sensorfläche geführt werden.
- Im Schreibbetrieb darf `EPD_SCLK` 20 MHz nicht überschreiten. Falls die bidirektionale Lesefunktion verwendet wird, darf der Lesetakt 2,5 MHz nicht überschreiten. Die Daten werden beim Schreiben an der steigenden SCLK-Flanke übernommen.
- Solange `EPD_BUSY` HIGH ist, dürfen keine neuen Befehle gesendet und keine laufenden Displayoperationen unterbrochen werden.
- Die Displaydomäne muss im Deep-Sleep vollständig abschaltbar sein, ohne Rückspeisung über SPI/Steuersignale.
- Die fünf ESP32-Ausgänge werden mit `SN74AXC8T245PWR` zwischen `3V3_CORE` und `3V3_DISPLAY_SW` power-off-isoliert. `EPD_BUSY` wird mit `SN74AXC1T45DCKR` in Gegenrichtung isoliert. `/OE` des Achtkanalbausteins liegt ohne `DISPLAY_EN` hardwareseitig HIGH.
- Revision A nutzt E-Paper-Pin 14 ausschließlich schreibend als `EPD_SDIO/MOSI`; die optionale bidirektionale Lesefunktion ist nicht implementiert und benötigt keinen MISO-GPIO.
- Bei abgeschalteter `3V3_DISPLAY_SW` müssen alle MCU-Signale zum E-Paper hochohmig beziehungsweise nicht rückspeisend sein oder durch Bauteile mit nachgewiesener Power-off-Isolation getrennt werden.
- Sobald `3V3_DISPLAY_SW` eingeschaltet ist, aber bevor die Firmware den Displaycontroller initialisiert, gelten folgende sichere Pegel: `EPD_CS_N` HIGH/inaktiv, `EPD_RESET_N` LOW/Reset aktiv sowie `EPD_SCLK`, `EPD_SDIO/MOSI` und `EPD_DC` LOW. Pull-Widerstände und gegebenenfalls Isolation sind auf der jeweils versorgten Seite anzuordnen, sodass diese Zustände auch bei ESP32-Reset entstehen.
- SPI-Leitungen sind kurz über einer durchgehenden Referenzfläche zu führen. Serien-Dämpfungsfootprints sind nahe am ESP32 vorzusehen.
- Testpunkte: Displayversorgung, SCLK, SDIO/MOSI, CS, D/C, RESET und BUSY.

### 10.3 Kapazitiver Touch

- Touch-Controller: `FT6336U`. Der spezifizierte Betriebsbereich für VDDA/VDD3 beträgt 2,8 V bis 3,3 V; 3,6 V ist nur die absolute Maximalgrenze und kein freigegebener Dauerbetriebswert. `3V0_TOUCH_AON` muss am FPC unter allen Toleranzen innerhalb 2,8 V bis 3,3 V bleiben.
- Der 6-polige Touch-FPC wird gemäß Herstellerzeichnung belegt: Pin 1 `GND`, Pin 2 `TOUCH_INT_N`, Pin 3 `TOUCH_RESET_N`, Pin 4 `3V0_TOUCH_AON`, Pin 5 `I2C_SCL`, Pin 6 `I2C_SDA`.
- I2C darf gemäß FT6336U-Datenblatt zwischen 10 kHz und 400 kHz betrieben werden.
- Touch teilt SDA und SCL mit der RTC. Es darf nur ein abgestimmter Satz Bus-Pull-ups auf der dauerhaft versorgten Seite existieren.
- Pull-up-Spannung, ESP32-Eingangspegel, RV-3028-Eingangspegel und die am integrierten Touch-FPC nicht separat herausgeführte IOVCC-Versorgung müssen zueinander kompatibel sein. Keine Touch-Leitung darf die aktuelle `3V0_TOUCH_AON`-Versorgung übersteigen oder den unversorgten Controller über Schutzdioden speisen.
- `TOUCH_INT_N` wird direkt auf einen Deep-Sleep-wake-fähigen RTC-GPIO des ESP32-S3 aus dem Bereich GPIO0 bis GPIO21 geführt; Strapping- und USB-Pins sind ausgeschlossen.
- Das FocalTech-Datenblatt bezeichnet das Signal als `/INT`; `TOUCH_INT_N` wird deshalb als active LOW ausgelegt. Das Datenblatt garantiert in der vorliegenden Fassung jedoch weder Ausgangstopologie noch minimale LOW-Pulsdauer. Der Schaltplan muss einen Serienwiderstand und bestückbare schwache Pull-up-/Pull-down-Optionen vorsehen; ein Open-Drain-Ausgang darf nicht ungeprüft angenommen werden.
- `TOUCH_RESET_N` wird über `SN74LVC1G07QDBVRQ1` als pegelkompatiblen Open-Drain-Ausgang mit definiertem Einschaltzustand geführt. GPIO7 besitzt einen externen Pulldown. Vor und während des Einschaltens bleibt Reset hardwareseitig LOW; GPIO7 HIGH gibt den Reset ausschließlich über den Pull-up nach `3V0_TOUCH_AON` frei.
- Im Komfort-Standby muss `TOUCH_RESET_N` während des gesamten ESP32-Deep-Sleep zuverlässig HIGH bleiben, damit der FT6336U im Monitor-Modus weiterarbeitet. Wird dafür ESP32-Pad-Hold verwendet, sind die notwendigen Funktionen `gpio_hold_en()` und `gpio_deep_sleep_hold_en()` beziehungsweise deren aktuelle ESP-IDF-Entsprechungen, der Zustand beim Eintritt und Aufwachen sowie das Verhalten bei Reset am Prototyp nachzuweisen. Alternativ ist eine stromarme Hardware-Halteschaltung zulässig.
- Die Touch-seitigen INT-, SDA- und SCL-Pins dürfen vor anliegender `3V0_TOUCH_AON` nicht HIGH getrieben werden; bei unabhängigem Einschalten oder vollständigem Abschalten der Touch-Domäne ist dies durch Power-off-Isolation sicherzustellen.
- Im Komfort-Standby muss der FT6336U im **Monitor-Modus** bleiben. In diesem Modus scannt er laut Datenblatt standardmäßig mit 25 Bildern/s, erkennt eine Berührung, wechselt in den Active-Modus und kann über `/INT` den ESP32 wecken. Der typische Strom beträgt 220 µA bei 2,8 V und 25 °C.
- Der im Datenblatt mit typisch 55 µA angegebene Sleep-/Hibernation-Modus reagiert nur auf ein hostseitiges RESET-/Wakeup-Signal. Eine Berührung weckt ihn nicht. Dieser Modus ist deshalb nur für den Minimal-Standby ohne Touch-Wakeup zulässig; nach Taster-Wakeup des ESP32 wird der Touch-Controller hostseitig aufgeweckt beziehungsweise zurückgesetzt.
- `TOUCH_INT_N` wird über Serienwiderstand und bestückbare Pull-Optionen direkt an GPIO2 geführt. Zusätzlich sind ein 0-Ω-Direktpfad und ein unbestückter kleiner Logic-/Latch-Footprint vorzusehen. Falls Touch-INT im vorgesehenen Standby-Modus nicht lang genug pegelaktiv bleibt, wird der 0-Ω-Pfad DNP gesetzt und vor Fertigungsfreigabe ein stromarmer Wake-Latch oder eine gleichwertige zuverlässige Lösung bestückt.
- Bei jedem Power-on des FT6336U muss die Versorgung von 0,1 VDD auf 0,9 VDD in höchstens 3 ms ansteigen. `TOUCH_RESET_N` bleibt nach Power-on mindestens 1 ms LOW. Nach Freigabe von Reset sind mindestens 300 ms bis zum ersten I2C-Zugriff beziehungsweise zuverlässigen Touch-Report einzuplanen.
- Ein Resetimpuls muss mindestens 5 ms LOW dauern; danach sind wiederum mindestens 300 ms bis zur Kommunikation einzuplanen.
- Für einen vollständigen Power-Cycle muss `3V0_TOUCH_AON` unter 0,3 V fallen und dort mindestens 5 ms verbleiben. Während abgeschalteter Touch-Versorgung müssen SDA, SCL, INT und RESET durch Power-off-Isolation oder gleichwertige Schaltung gegen Rückspeisung gesperrt sein.
- Da der Touch-Controller während seiner Start-/Resetsequenz den gemeinsamen I2C-Bus vorübergehend LOW halten kann, darf die Hardware keine RTC-Transaktion in dieser Phase voraussetzen. Die Firmware darf frühestens 300 ms nach Resetfreigabe auf den Touch zugreifen; die tatsächliche Zeit bis zur Busfreigabe ist am Muster zu messen, weil das Datenblatt dafür keinen Maximalwert nennt.
- Normal- und Monitorstrom, Hibernationstrom, INT-Polarität/-Pulsdauer, Wake-Zuverlässigkeit und das Verhalten am gemeinsamen I2C-Bus müssen am beschafften Display gemessen werden.
- Touch-Wakeup ist außerhalb des spezifizierten Betriebstemperaturbereichs der Displaybaugruppe nicht garantiert. Der externe Taster bleibt die zuverlässige Kaltstart-Wake-Quelle.

### 10.4 Frontlicht

- Das integrierte Frontlicht besitzt laut Hersteller vier intern parallel geschaltete weiße LED-Dies. Die Herstellerzeichnung nennt eine Durchlassspannung von 2,75 V minimal, 2,9 V typisch und 3,0 V maximal sowie einen Gesamtstrom von 60 mA. Diese Spannungswerte sind LED-Durchlassspannungen und kein zulässiger Versorgungsspannungsbereich.
- Der 6-polige Frontlicht-FPC wird belegt: Pins 1 und 2 gemeinsam `FRONTLIGHT_LED_PLUS`, Pins 3 und 4 offen/`NC`, Pins 5 und 6 gemeinsam `FRONTLIGHT_LED_MINUS`. Beide Plus- und beide Minuskontakte sind mit kurzen, symmetrischen Leiterwegen anzuschließen; die NC-Pins dürfen nicht verbunden werden.
- Das Frontlicht wird mit `AL8861QMP-13` aus `VIN_SYS` stromgeregelt und per GPIO21 PWM-gesteuert. Zielnennstrom ist 50 mA; bei der nominellen 0,1-V-Strommessschwelle ist 2,0 Ω/1 % der Startwert. Der Gesamtstrom aller vier LED-Dies darf unter keiner Kombination aus Versorgung, Temperatur, Bauteiltoleranz und PWM-Zustand 60 mA überschreiten. Der Sollstrom muss über einen BOM-Wert anpassbar sein.
- Versorgung und Treibertopologie müssen bei 3,0 V maximaler LED-Durchlassspannung und minimaler speisender Spannung noch ausreichend Regelreserve besitzen. Eine verlustreiche lineare Speisung direkt aus dem bis 14 V reichenden `VIN_SYS` ist nicht zulässig.
- Hardware-Default bei Reset, Boot und Deep-Sleep ist AUS.
- Testpunkt beziehungsweise Messmöglichkeit für den Gesamtstrom ist vorzusehen.

### 10.5 Temperaturgrenzen

- Vom Hersteller spezifizierter Displaybetrieb: **0 °C bis +50 °C**.
- Vom Hersteller spezifizierte Displaylagerung: **−25 °C bis +70 °C**.
- Displayaktualisierungen außerhalb 0 °C bis +50 °C sind softwareseitig zu sperren. Bei −15 °C wird keine Aktualisierung erwartet; Bedienung bleibt über Taster und WLAN möglich.
- Das E-Paper darf seinen letzten Bildinhalt ohne Versorgung behalten.
- Nach höchstens fünf aufeinanderfolgenden Fast- oder Partial-Refresh-Vorgängen ist laut Hersteller ein Full Refresh vorzusehen, um Artefaktansammlung zu reduzieren. Dies ist eine dokumentierte Firmwareabhängigkeit.

### 10.6 Handhabung und mechanischer Schutz

- Die drei FPC-Verbindungen dürfen nicht bei versorgtem E-Paper, Touch oder Frontlicht gesteckt oder getrennt werden.
- Das Gehäuse darf keinen punktuellen Druck auf das E-Paper ausüben. Displayauflage, Toleranzen und Befestigung müssen thermische Ausdehnung ohne Verspannung zulassen.
- Die ungeschützten FPC-/Bondingbereiche dürfen weder als Griff- noch als Klemmfläche verwendet werden und sind gegen Kontakt mit Gehäusekanten zu schützen.

## 11. Externer Taster und weiße Ring-LED

- Vorgesehenes Tastermodell: APEM AV, Bestellcode **`AV970220000700`** gemäß den bislang gewählten Optionen: 19-mm-Buchse, weiße LED ohne eingebauten Vorwiderstand, Silberkontakte, Lötanschlüsse, opalweißer Ring, vernickeltes Messing, ohne IP67-Zusatz `K`.
- Der Bestellcode ist vor Bestellung durch APEM oder den autorisierten Distributor gegen den dann aktuellen Bestellschlüssel zu bestätigen.
- Verwendet wird der Schließerkontakt (NO). Ein vorhandener NC-Kontakt bleibt im Kabelbaum isoliert und unbeschaltet.
- Kabellänge zwischen Taster und Board: etwa **3 m**, vieradrig.
- Paar 1: `BUTTON_N` mit GND. Paar 2: `LED_CC_PLUS` mit `LED_PWM_MINUS`. Verdrillte Paare sind zu verwenden.
- `BUTTON_N` ist Active-Low und wird direkt auf einen Deep-Sleep-wake-fähigen RTC-GPIO geführt.
- Der Eingang erhält am PCB-Stecker ESD-Schutz, Serienwiderstand, externen Pull-up und ein angemessenes RC-Filter. Die Filterung darf zuverlässiges Aufwachen nicht verhindern.
- Die Taster-LED besitzt keinen eingebauten Vorwiderstand und darf nicht direkt von einem GPIO oder unstrombegrenzt aus 3,3 V/12 V gespeist werden.
- Zielnennstrom der weißen LED: etwa **10 mA**, auf jeden Fall unterhalb der vom Tasterhersteller zulässigen 20 mA. `BCR421UW6Q-7` ist der automotive-qualifizierte Konstantstromregler mit eigenem Enable-/PWM-Eingang; seine Verlustleistung wird für 14 V thermisch geprüft.
- Die Helligkeit wird direkt über den `EN`-Eingang des `BCR421UW6Q-7` durch GPIO38-PWM geregelt. Ein 100-Ω-Serienwiderstand und 100-kΩ-Pulldown am Enable sorgen für AUS ohne Firmware. Die PWM-Frequenz muss unter 25 kHz bleiben.
- `LED_CC_PLUS` wird aus `VIN_SYS` über eine für 5-V- und 12-V-Eingang geeignete Strombegrenzung gespeist.
- Ein Hardware-Pull-down am `BCR421`-Enable stellt AUS bei Reset, Boot und Deep-Sleep sicher.
- Die PWM-Führung und Filterung muss Einkopplung in den parallelen Tastereingang vermeiden.

## 12. RTC und Backup-Batterie

- RTC: **Micro Crystal `RV-3028-C7-32.768kHz-1ppm-TA-QC`** mit Hauptversorgung aus `3V3_CORE` am gemeinsamen I2C-Bus. Die Bus-Pull-ups liegen gemäß Abschnitt 5.4 an `3V0_TOUCH_AON`.
- Backupquelle: austauschbare Panasonic **`BR1225`**-Lithium-Primärzelle im THT-Halter **Keystone `500`**.
- Der Halter muss verpolungssicher beziehungsweise eindeutig markiert und im geöffneten Gehäuse austauschbar sein.
- Die RTC muss bei fehlender 12-V- und USB-Versorgung mindestens vier Wochen weiterlaufen. Dies ist durch Worst-Case-Stromrechnung und Messung des Backupstroms nachzuweisen.
- Die interne Trickle-Charge-Funktion bleibt deaktiviert.
- `BAS116,215` bildet die niederleckende hardwareseitige Sperre und verhindert das Laden der Primärzelle auch bei fehlerhafter Softwarekonfiguration.
- Der RTC-Interrupt wird zu einem Testpunkt, aber nicht zu einem ESP32-GPIO geführt. RTC-Alarm ist keine Wake-Funktion von Revision A und kein Abnahmekriterium.
- Die bestehende Software verwendet teilweise einen DS3231-Adapter. Die Umstellung auf RV-3028 ist eine Softwareaufgabe; eine elektrische DS3231-Kompatibilität ist nicht gefordert.

## 13. PCB-Diagnoseanzeige und optionale Status-LEDs

### 13.1 Verpflichtende Energiefluss-Diagnoseanzeige

- Auf einer im geöffneten Gehäuse gut sichtbaren freien PCB-Fläche sind fünf optisch aufeinander abgestimmte rote Diagnose-LEDs mit dauerhaft lesbarer Silkscreen-Beschriftung und Verbindungslinien in folgender Energieflussanordnung zu platzieren:

```text
12V  ● ─┐
        ├─ ● 3V3 ─ ● RUN ─ ● HEAT
USB  ● ─┘
```

- Diagnose- und optionale Status-LEDs sind `LTST-C190KRKT` in 0603. Die lokalen BOOT-, RESET- und DIAG-Taster sind `KMR221GLFS`.

- Die Anzeige befindet sich auf dem Board und muss nicht am Displayrand oder durch das geschlossene Gehäuse sichtbar sein. Bauteile und Beschriftung dürfen FPC-Biegeradien, Steckverbinderzugang, Antennenkoax, Hochspannungsbereich des E-Paper-Boosters oder Befestigungspunkte nicht beeinträchtigen.
- `12V` zeigt das Vorhandensein des gegen Verpolung und Transienten geschützten 12-V-Pfads vor dessen Zusammenführung mit USB an.
- `USB` zeigt das Vorhandensein des geschützten USB-VBUS-Pfads vor dessen Zusammenführung mit 12 V an.
- `3V3` zeigt die tatsächlich vorhandene Spannung auf `3V3_CORE` an.
- `RUN` wird über genau einen ESP32-GPIO erst nach erfolgreichem Abschluss der Firmwareinitialisierung aktiviert. Bei Reset, Bootloaderfehler und Deep-Sleep ist `RUN` LOW beziehungsweise die LED aus.
- `HEAT` zeigt ausschließlich das Vorhandensein von `AUTOTERM_5V` und damit die elektrische Anwesenheit der Heizungsseite an. Es ist kein Nachweis erfolgreicher UART-Kommunikation.
- Die fünf LEDs dürfen nur leuchten, solange der lokale momentane DIAG-Taster gedrückt oder die parallel dazu vorgesehenen Testpads `DIAG` und `GND` überbrückt sind. Der DIAG-Taster ist ein Schließer, muss im geöffneten Gehäuse zugänglich sein und darf weder den ESP32 wecken noch einen GPIO, eine Versorgungsschiene oder einen Betriebszustand verändern.
- Die Spannungszweige für 12 V, USB, 3V3 und HEAT arbeiten rein hardwareseitig und benötigen keinen GPIO. Unterschiedliche Spannungsquellen müssen durch Dioden, Transistorstufen oder eine gleichwertige Schaltung so getrennt sein, dass über die Diagnoseanzeige weder im gedrückten noch im ungedrückten Zustand eine Rückspeisung zwischen 12 V, USB-VBUS, `3V3_CORE` und `AUTOTERM_5V` möglich ist.
- Ein einfaches unisoliertes Zusammenschalten der LED-Kathoden verschiedener Spannungsdomänen ist nicht zulässig. Schaltung und Worst-Case-Spannungen sind zu dokumentieren.
- Zielstrom je leuchtender Diagnose-LED: 0,5 mA bis 1 mA. Vorwiderstände beziehungsweise Strombegrenzungen sind für 10 V bis 14 V, USB-Toleranzen, 3V3-Toleranzen, `AUTOTERM_5V`, LED-Durchlassspannung und Temperatur zu berechnen. Helligkeit und optische Gleichmäßigkeit werden am Prototyp geprüft; BOM-Werte müssen ohne Layoutänderung anpassbar sein.
- Bei nicht gedrücktem DIAG-Taster darf die komplette Diagnoseanzeige einschließlich `RUN`-Pfad den Ruhestrom aus jedem beteiligten Versorgungszweig um höchstens 5 µA erhöhen. Es gibt keine dauerhaft leuchtende Power-LED.
- Der verpflichtende `RUN`-GPIO und die Diagnoseanzeige haben in GPIO- und Platzbilanz Vorrang vor den optionalen Status-LEDs aus Abschnitt 13.2.

### 13.2 Zwei optionale Status-LEDs

- Zwei einzeln steuerbare **rote** Status-LEDs sind als gemeinsamer Funktionsblock gewünscht, aber optional und kein Abnahmekriterium. Revision A wird entweder mit beiden LEDs oder ohne zusätzliche Status-LEDs ausgeführt; eine Teilbestückung ist nicht vorgesehen.
- Funktionale Schnittstellen, beide Wake-Eingänge, sichere Rail-/Reset-Steuerungen, natives USB, der verpflichtende `RUN`-GPIO und die Diagnosemöglichkeiten aus Abschnitt 13.1 haben bei GPIO- und Platzbedarf Vorrang. Zeigt die vollständige Pin-Matrix oder Platzierung nicht genügend geeignete Ressourcen, werden beide optionalen Status-LEDs vollständig weggelassen; hierfür darf kein I2C-Portexpander ergänzt und keine funktionale oder diagnosebezogene Anforderung eingeschränkt werden.
- Werden die zwei Status-LEDs umgesetzt, erhält jede eine eigene Strombegrenzung und einen eigenen steuerbaren Zustand. Direktansteuerung oder ein stromarmer Treiber sind zulässig; die Funktionen dürfen nicht von einem I2C-Portexpander abhängig gemacht werden.
- Hardware-Default bei Reset, Boot und Deep-Sleep ist AUS.
- Umgesetzte Status-LEDs müssen im montierten Zustand sichtbar sein oder über definierte Lichtleiterpositionen verfügen; dies wird beim Platzierungsreview festgelegt.

## 14. GPIO- und Bussystemregeln

- I2C wird gemeinsam von RV-3028 und FT6336U genutzt.
- E-Paper verwendet eine eigene SPI-Schnittstelle beziehungsweise einen eindeutig zugeordneten SPI-Bus ohne lange externe Leitungen.
- AUTOTERM verwendet eine Hardware-UART ungleich UART0; Signale dürfen über die ESP32-GPIO-Matrix auf geeignete Pins gelegt werden.
- 1-Wire ist fest GPIO4 zugeordnet.
- Taster und Touch-INT müssen direkte ESP32-Wake-Eingänge sein und dürfen nicht über Portexpander geführt werden.
- Die vollständige und verbindliche Belegung steht in der [GPIO-Matrix Revision A](GPIO-Matrix_Revision_A.md). Die zwei optionalen Status-LEDs sind GPIO41 und GPIO42 zugeordnet; `RUN` liegt an GPIO39, U0TXD/U0RXD an GPIO43/GPIO44, `AUTOTERM_OE` an GPIO47 und GPIO48 bleibt Reserve.
- Rail-Enables, Pegelwandler-OE, LED-Treiber und sonstige Ausgänge erhalten externe Pull-ups/-downs für einen sicheren Zustand vor Firmwareinitialisierung.
- Die Pinplanung muss die von Espressif dokumentierten Einschaltimpulse berücksichtigen. GPIO1 bis GPIO17 können beim Einschalten etwa 60 µs LOW sein; GPIO18 kann LOW- und HIGH-Impulse zeigen. GPIO18 darf deshalb nicht für ein ungefiltertes Active-High-Enable einer externen Last verwendet werden.
- Unbenutzte GPIOs dürfen nicht dauerhaft floaten. Sie erhalten einen geeigneten externen Pull-Widerstand oder werden nach dem Booten per Firmware mit einem internen Pull definiert. Strapping-Pins dürfen dadurch nicht verändert werden.
- Jeder externe GPIO-Pfad muss durch Pegelwandlung, Serienimpedanz und Schutzbeschaltung sicherstellen, dass am Modul kein Pin unter −0,3 V oder über `VDD33 + 0,3 V` beaufschlagt wird. Eingangs- und Ausgangsstromgrenzen des Moduls sind einzuhalten.
- Ein I2C-Portexpander ist für Revision A nicht vorgesehen. Falls der PCB-Designer wider Erwarten einen benötigt, ist dies vor Schaltplan-Freeze mit vollständiger Pinbilanz, Ruhestromauswirkung und Resetverhalten zur Freigabe vorzulegen.
- Die Pin-Matrix muss mindestens Signalname, GPIO, Ein-/Ausgang, Resetpegel, externen Pull-Widerstand, Power-up-Glitch, Deep-Sleep-Zustand, Wake-Fähigkeit und Versorgungsdomäne enthalten.

## 15. Leiterplattenaufbau und Layoutregeln

### 15.1 Stackup und Basisspezifikation

- Verbindlich ist ein **vierlagiges PCB**.
- Erste Fertigungsmenge: **fünf vollständig bestückte Prototypen über PCBWay**.
- Nominale Dicke: 1,6 mm, sofern FPC- oder Gehäusemechanik keine dokumentierte Abweichung verlangt.
- FR-4 mit Tg mindestens 150 °C.
- Kupfer: mindestens 1 oz auf Außenlagen; Innenlagen nach bestätigtem PCBWay-Stackup.
- Oberflächenfinish: ENIG oder eine gleichwertige, für feine FPC-Pads und Lagerung geeignete Oberfläche.
- Standard-Durchkontaktierungen; keine Blind-/Buried-Vias.
- Via-in-Pad nur, wenn vom Hersteller zwingend gefordert und von PCBWay gefüllt/verschlossen ausgeführt.
- Der konkrete impedanzkontrollierte Stackup ist vor dem Routing von PCBWay zu bestätigen.

Empfohlene Lagenbelegung:

- L1 ist für dieses Projekt die Elektronik-/Anschlussseite auf der Rückseite der Einheit; L4 ist die Display-/Bedienseite.
- L1: ESP32-S3-WROOM-1U, USB, weitere Bauteile und kritische Signale.
- L2: durchgehende, ungeteilte GND-Referenzfläche; keine Signale.
- L3: Versorgungsflächen und wenige langsame Signale; keine Zerschneidung kritischer Rückstrompfade.
- L4: Bauteile, langsame Signale und möglichst zusammenhängende GND-Flächen.

Espressif empfiehlt für den generischen vierlagigen Aufbau keine Bauteile auf L4. Die wegen Display und Bauraum erforderliche beidseitige Bestückung ist hier eine dokumentierte mechanische Abweichung. Auf L4 sind deshalb nur störungsarme Bauteile zulässig; unter WROOM-1U, USB, Buck-Hot-Loop und kritischen Rückstrompfaden bleibt L4 frei.

### 15.2 Verbindliche Layoutregeln

- USB D+/D− als 90-Ω-Differenzpaar über durchgehender Referenzfläche, kurz, ohne Stubs und nach aktuellem Espressif-/USB-Layoutleitfaden.
- Keine Signalleitung darf einen Spalt ihrer Referenzfläche kreuzen.
- Abblockkondensatoren unmittelbar an den zugehörigen Versorgungspins mit sehr kurzem GND-Rückweg.
- Hot-Loop des Buck-Reglers minimieren und Hersteller-Referenzlayout übernehmen.
- Schaltknoten klein halten und von Touch, RTC, Antennenkoax, 1-Wire und USB fernhalten.
- GND-Stitching-Vias an Kanten, bei Lagenwechseln und um störende Leistungsbereiche vorsehen.
- Strompfade, Kupferbreiten und Via-Anzahl sind für Worst-Case-Strom und zulässigen Temperaturanstieg zu berechnen.
- ESD-/TVS-Bauteile direkt am jeweiligen Stecker platzieren; der Ableitpfad nach GND muss kurz und niederinduktiv sein.
- FPC-, WROOM-, QFN- und sonstige kritische Footprints müssen gegen die aktuelle Herstellerzeichnung unabhängig geprüft werden.
- Das offizielle Espressif-WROOM-1U-Landpattern einschließlich Copper-Pads, GND-Pads, EPAD und Via-Geometrie ist unverändert zu verwenden. Das Landpattern des längeren WROOM-1-Moduls darf nicht verwendet werden.
- Die beiden seitlichen GND-Pads des Moduls sind mit kurzen, breiten Verbindungen und mehreren Vias an die L2-GND-Fläche anzubinden. Das EPAD-Copper und seine Thermal-/Ground-Vias sind ebenfalls mit GND zu verbinden.
- Ob das zentrale EPAD verlötet wird, ist im Fertigungsdatensatz ausdrücklich festzulegen. Bei verlötetem EPAD muss die Pastenöffnung so begrenzt werden, dass das Modul nicht angehoben wird und sämtliche seitlichen Pads zuverlässig verlötet werden.
- Das ESP32-S3-WROOM-1U und USB müssen auf L1 unmittelbar über der durchgehenden L2-GND-Fläche liegen. Eine Platzierung des Moduls auf L4 ist nur zulässig, wenn der Stackup gespiegelt wird und die unmittelbar benachbarte Innenlage eine ungeteilte GND-Fläche bildet.
- Im WROOM-Bereich dürfen auf der gegenüberliegenden PCB-Seite keine Schaltregler, Induktivitäten oder schnellen Signale angeordnet werden. Die Rückstromfläche unter den digitalen Modulanschlüssen muss zusammenhängend bleiben.
- Das WROOM-1U besitzt laut Espressif keine Antennen-Keep-out-Zone auf dem Basis-PCB. Es darf daher kein vom WROOM-1-Modul mit PCB-Antenne übernommener Kupfer-Keep-out verwendet werden. Das offizielle WROOM-1U-Landpattern bleibt unverändert; über und um den U.FL-/MHF-I-Stecker ist mechanischer Freiraum für Gegenstecker, Koaxkabel und zulässigen Biegeradius vorzusehen. Modul, Koaxkabel und umgebendes Metall/Gehäuse sind mechanisch und HF-gerecht anzuordnen.
- Am E-Paper-SPI-Takt ist nahe am ESP32 ein bestückbarer Serienwiderstand oder Ferrit sowie ein optionaler, zunächst unbestückter Kondensator nach GND vorzusehen. Entsprechende Dämpfungsfootprints sollen, sofern der Platz reicht, auch für die übrigen SPI-Signale vorgesehen werden.
- Booster-MOSFET, 47-µH-Induktivität, drei Dioden und Hochspannungs-Kondensatoren des E-Papers sind unmittelbar am 24-poligen FPC-Stecker gemäß Good-Display-Referenzschaltung zu gruppieren. Booster-Schleifen und -Kupferflächen sind zu minimieren und von Touch-FPC, I2C, RTC, USB und Antennenkoax fernzuhalten.
- Die FPC-Steckerbereiche müssen mechanische Keep-outs für Verriegelungsbetätigung, FPC-Einschub und Biegeradius enthalten. Unter den drei FPC-Zungen dürfen keine scharfkantigen Vias, Bauteile oder freiliegenden Kupferkanten liegen.
- Testpads dürfen keine ungewollten Stubs an USB oder anderen schnellen Signalen erzeugen.
- Bauteile sollen, sofern funktional und platzmäßig möglich, mindestens 0603 besitzen. Kleinere Bauformen und Spezialgehäuse sind zulässig, wenn sie für die Funktion oder den Bauraum nötig sind.
- Silkscreen muss Steckerbezeichnungen, Pin 1, Polaritäten, Batteriepolung, BOOT/RESET, PCB-Revision und alle Testpunkte eindeutig kennzeichnen.
- Die vollständige Predictable-Designs-Checkliste ist beim Layoutreview Punkt für Punkt abzuarbeiten und als ausgefülltes Reviewprotokoll abzugeben.

### 15.3 Fertigung und Handhabung des ESP32-Moduls

- Das `ESP32-S3-WROOM-1U-N16R8` ist ein MSL-3-Bauteil.
- Nach Öffnung des Moisture-Barrier-Bags muss das Modul innerhalb von 168 Stunden bei 25 ± 5 °C und höchstens 60 % relativer Feuchte verlötet werden. Bei Überschreitung ist es nach Espressif-Vorgabe zu trocknen beziehungsweise zu backen.
- Das ESP32-Modul darf nur **einen Reflow-Zyklus** durchlaufen.
- Bei doppelseitiger Reflow-Bestückung darf das Modul deshalb erst für den zweiten/finalen Reflow bestückt werden. Eine andere Prozessfolge ist nur mit einem dokumentierten Verfahren zulässig, das ebenfalls genau einen Reflow des Moduls sicherstellt.
- Das aktuelle Espressif-Reflowprofil und bleifreies SAC305 sind einzuhalten; PCBWay muss die Prozessfolge vor Produktionsfreigabe bestätigen.
- Das bestückte Modul darf keiner Ultraschallreinigung und keiner Ultraschallschweißung ausgesetzt werden.

## 16. Sichere Hardware-Defaultzustände

Ohne laufende Firmware sowie während Reset, Boot und Deep-Sleep gelten zwingend:

| Funktion | Hardwarezustand |
|---|---|
| AUTOTERM-TX | hochohmig |
| UART-Pegelwandler OE | LOW / deaktiviert |
| E-Paper-Versorgung | aus |
| Frontlicht | aus |
| externe weiße Taster-LED | aus |
| Diagnose-LEDs 12V/USB/3V3/HEAT | aus, solange DIAG nicht gedrückt beziehungsweise überbrückt ist |
| Diagnose-LED RUN und zugehöriger GPIO | aus beziehungsweise LOW bei Power-up, Reset, Bootloader und Deep-Sleep |
| zwei optionale rote Status-LEDs, sofern umgesetzt | aus |
| DS18B20-Sensorversorgung | aus |
| Tastereingang | definiert HIGH, Active-Low-wake-fähig |
| Touch-INT | im Komfort-Standby durch versorgten FT6336U-Monitor-Modus definiert und active-LOW-wake-fähig; im Minimal-Standby keine Touch-Wake-Anforderung |
| Touch-RESET | bei Power-up/ESP32-Reset LOW; nach Freigabe im Normalbetrieb und während Komfort-Standby HIGH an `3V0_TOUCH_AON` |
| E-Paper-Signale | bei ausgeschalteter Displaydomäne hochohmig/nicht rückspeisend; bei eingeschalteter Domäne vor Initialisierung CS HIGH, RESET LOW, SCLK/SDIO/D/C LOW |
| USB-/12-V-Pfade | gegenseitig rückstromgesperrt |

Die sicheren Power-up-, Reset- und Power-off-Zustände müssen durch Hardware-Pull-ups/-downs und Power-Off-Isolation entstehen, nicht allein durch Software. Ein nach expliziter Softwarefreigabe absichtlich gehaltener Betriebszustand während Deep-Sleep, insbesondere `TOUCH_RESET_N` HIGH im Komfort-Standby, darf die dokumentierte ESP32-Pad-Hold-Funktion verwenden und muss nach Abschnitt 18 verifiziert werden.

## 17. Testpunkte und Design-for-Test

Mindestens folgende Netze benötigen zugängliche, beschriftete Testpunkte:

- `BATT_12V_IN`, geschützter 12-V-Pfad, `VIN_SYS`, `3V3_CORE`, `3V0_TOUCH_AON`, alle geschalteten 3,3-V-Domänen und GND,
- USB D+/D− nur als messgerechte Pads ohne problematischen Stub,
- `CHIP_PU`, GPIO0/BOOT, U0TXD, U0RXD,
- AUTOTERM TX/RX auf 3,3-V- und 5-V-Seite, OE und `AUTOTERM_5V`,
- `1WIRE_DQ`,
- I2C SDA/SCL, Touch-INT, Touch-RESET und RTC-INT,
- E-Paper SCLK, SDIO/MOSI, CS, D/C, RESET und BUSY,
- Frontlichtstrom sowie PWM-Signale der beiden Beleuchtungen,
- `DIAG`, Diagnosezweige 12V/USB/3V3/HEAT und Diagnoseausgang `RUN`.

Testpunkte müssen im bestückten, geöffneten Gerät zugänglich sein. Ein zusammenhängendes GND-Testpad für Oszilloskop-Masse ist in der Nähe der Leistungs- und Kommunikationsbereiche vorzusehen.

## 18. Prüf- und Abnahmekriterien für fünf Prototypen

Vor Bestellung müssen ERC und DRC ohne ungeklärte Fehler abgeschlossen sein. Für die Prototypen sind mindestens folgende Prüfungen zu dokumentieren:

1. Sichtprüfung, Polarität, Bestückung und Kurzschlusstest aller Versorgungsschienen.
2. Start und stabiler Betrieb bei 10 V, 12 V und 14 V Eingang.
3. USB-only-Betrieb ohne 12 V: Flashen und native USB-Kommunikation funktionieren bei USB-Default-Current. Uneingeschränkter Betrieb wird nur bei erkannter CC-Ankündigung von mindestens 1,5 A freigegeben; die gemessene Boardaufnahme bleibt in beiden Fällen innerhalb der jeweils erlaubten Grenze.
4. Gleichzeitiger Anschluss von 12 V und USB ohne Rückspeisung in USB, Fahrzeugkreis oder AUTOTERM-Port.
5. Verpoltest am 12-V-Eingang gemäß Abschnitt 5.1 ohne Schaden.
6. Lastsprungtest mit aktivem WLAN ohne Brownout; 3,3 V bleibt innerhalb 3,0 V bis 3,6 V.
7. Gemessener Komfort-Standby-Strom kleiner 0,5 mA bei 12 V.
8. Wiederholtes Aufwachen aus Deep-Sleep durch externen Taster sowie durch Touch im FT6336U-Monitor-Modus. `TOUCH_RESET_N` bleibt während des gesamten Komfort-Standby HIGH. Im Hibernation-Modus darf Touch nicht als Wake-Quelle gewertet werden.
9. Hardware-Defaultzustände aus Abschnitt 16 bei Power-up, Reset und Deep-Sleep.
10. UART-Kommunikation mit angeschlossener AUTOTERM-Heizung; bei fehlendem `AUTOTERM_5V` keine Rückspeisung und hochohmiger Heizungs-TX.
11. Zuverlässiger gleichzeitiger Betrieb aller drei DS18B20 mit dem realen 2-bis-5-m-Kabelbaum.
12. Display-Voll-, Fast- und Teilaktualisierung, `BUSY`-HIGH-Verhalten, Reset, SPI-Schreibbetrieb bis zur freigegebenen Taktgrenze sowie Full Refresh nach fünf Fast-/Partial-Zyklen bei Raumtemperatur.
13. Dimmbereich und Maximalstrom der weißen externen Taster-LED.
14. RTC-Betrieb über I2C, Umschaltung auf BR1225, Backupstrommessung und rechnerischer Nachweis von mindestens vier Wochen Pufferzeit.
15. Oszilloskopprüfung von `3V3_CORE` und `CHIP_PU/EN` bei 12-V-Einschalten/-Ausschalten, USB-Einschalten/-Ausschalten, Quellenwechsel, Brownout und schnell wiederkehrender Versorgung.
16. Manueller Recovery-Test: BOOT gedrückt halten, RESET auslösen und erfolgreichen USB-Download-Boot nachweisen; GPIO46 bleibt dabei LOW.
17. Prüfung aller extern wirksamen Enable-, TX- und LED-Ausgänge während Power-up, Reset und den dokumentierten GPIO-Einschaltimpulsen.
18. WLAN-Reichweiten- und Durchsatztest im finalen Gehäuse am vorgesehenen Einbauort.
19. Durchgangs- und Pin-1-Prüfung aller drei nach Herstellerzeichnung erstellten Display-FPC-Verbindungen gegen das Originalmuster; insbesondere darf keine gespiegelte Kontaktseitenzuordnung vorliegen.
20. Touch-Prüfung bei Power-on, Reset und Deep-Sleep: Spannung und Anstiegszeit von `3V0_TOUCH_AON`, Worst-Case-I2C-HIGH-Pegel an ESP32/RV-3028/FT6336U, Reset-LOW-Zeiten, `TOUCH_RESET_N`-Haltezustand, 300-ms-Initialisierungszeit, I2C-Busfreigabe, INT-Polarität/-Pulsdauer sowie Stromaufnahme in Active-, Monitor- und Hibernation-Modus.
21. Falls Touch vollständig abschaltbar ausgeführt wird: Nachweis von unter 0,3 V für mindestens 5 ms, fehlender Rückspeisung über SDA/SCL/INT/RESET und erfolgreicher Wiederinbetriebnahme.
22. Frontlichtmessung über den gesamten PWM-Bereich; der Worst-Case-Gesamtstrom bleibt unter 60 mA und der Treiber besitzt bei maximaler LED-Durchlassspannung ausreichende Regelreserve.
23. Diagnoseanzeige bei 12 V allein, USB allein, beiden Quellen gleichzeitig, vorhandener/fehlender 3V3-Schiene, aktivem ESP32, ESP32-Deep-Sleep sowie vorhandener/fehlender `AUTOTERM_5V` prüfen. Nur die jeweils gültigen LEDs leuchten während gedrücktem DIAG-Taster; der Taster weckt den ESP32 nicht und beeinflusst keinen Betriebszustand.
24. Rückspeisungsprüfung zwischen allen vier Diagnose-Spannungszweigen bei gedrücktem und ungedrücktem DIAG-Taster. Der zusätzliche Ruhestrom der vollständigen Diagnoseanzeige bleibt bei nicht gedrücktem Taster je Versorgungszweig unter 5 µA. Falls die zwei optionalen Status-LEDs bestückt sind, werden ihre unabhängige Ansteuerung und sicheren AUS-Zustände ebenfalls geprüft.

EMV-Vorzertifizierung ist für Revision A nicht zwingend, aber Nahfeldprüfung und Kontrolle des Buck-Schaltknotens, der USB-Verbindung, der 1-Wire-Leitung und der 3-m-PWM-/Tasterleitung werden dringend empfohlen.

## 19. Vom PCB-Designer zu liefernde Unterlagen

- editierbare native Schaltplan- und PCB-Quelldaten einschließlich vollständiger Bibliothek beziehungsweise eingebetteter Symbole/Footprints,
- Schaltplan als PDF,
- vollständige Pin-Matrix des ESP32-S3,
- Stückliste mit Hersteller, vollständiger MPN, Wert, Gehäuse, Toleranz, Spannungs-/Temperaturrating und PCBWay/LCSC-Artikelnummer soweit verfügbar,
- Gerber-/ODB++-Daten, NC-Drill, Pick-and-Place/CPL und Bestückungszeichnungen für beide Seiten,
- Fertigungszeichnung mit Stackup, Impedanzvorgaben, Leiterplattenkontur, Bohrungen und Toleranzen,
- 3D-STEP-Modell des vollständig bestückten Boards einschließlich Display, Steckverbinder, Batterie und ESP32-Antennenstecker,
- Kabelbaumzeichnungen für J1 bis J4 mit Ansicht der Steckseite, Pinfarben, Leiterquerschnitten und Gegenstecker-MPNs,
- Strom-, Verlustleistungs- und Ruhestrombudget,
- Berechnung des 12-V-Eingangsschutzes und der TVS-Klemmung,
- ausgefüllte ERC-, DRC-, Espressif- und Predictable-Designs-Reviewchecklisten,
- Testplan, Testpunktplan und dokumentierte Messergebnisse der fünf Prototypen,
- Änderungs-/Abweichungsliste gegenüber diesem Dokument.

Bauteilalternativen dürfen nicht nur anhand gleicher Nennwerte ersetzt werden. Footprint, Pinout, Einschaltzustand, Leckstrom, Temperaturbereich und Verfügbarkeit sind mitzuprüfen.

## 20. Verifikationspunkte vor Fertigungsfreigabe

Diese Punkte blockieren nicht den Beginn von Schaltplan und Platzierung, müssen aber vor der Fertigungsfreigabe abgeschlossen sein:

1. Originalmuster des `GDEY029T94-FT01` beschaffen; alle drei FPCs, Kontaktseiten und Biegeradien gegen Zeichnung und Footprints prüfen.
2. `3V0_TOUCH_AON`, FT6336U-Monitor-, Hibernation- und optionalen Power-off-Zustand, `TOUCH_RESET_N`-Hold, INT-Polarität/-Pegelhaltezeit, gemeinsamen I2C-Bus und Deep-Sleep-Wakeup messen; gegebenenfalls Wake-Latch beziehungsweise Power-off-Isolation bestücken.
3. 24-/6-/6-polige FPC-Footprints und komplette E-Paper-Booster-Beschaltung gegen Kapitel 4, 5 und 12 der verlinkten `GDEY029T94-FT01`-Spezifikation unabhängig prüfen.
4. Die festgelegten Nano-Fit-Header, Gegenstecker und Kontakte gegen Herstellerzeichnung prüfen; THT-Handbestückung, Gold-zu-Gold-Paarung und sichere Nichtvertauschbarkeit durch die unterschiedlichen Polzahlen von J2/J4 bestätigen.
5. APEM-Bestellcode `AV970220000700` durch Hersteller/Distributor bestätigen.
6. `TPSMB18CA-VR`, `LM74720QDRRRQ1`, `IPG20N06S4L-26`, Filter und `LMR43620MSC3RPERQ1` einschließlich aller Worst-Case-Spannungen und thermischen Reserven berechnen.
7. Mechanische Platzierung im 98-mm-×-48-mm-Zielumriss als 3D-Modell prüfen; USB, Antennenkoax, Knopfzelle, BOOT/RESET/DIAG und alle Verriegelungen müssen erreichbar sein. Energieflusslinien und Beschriftungen der Diagnoseanzeige müssen lesbar bleiben.
8. Die festgelegte ESP32-Pin-Matrix und alle sicheren Reset-/Deep-Sleep-Zustände einschließlich des verpflichtenden `RUN`-Diagnoseausgangs im Schaltplan reviewen. Reicht die PCB-Fläche nicht aus, sind die zwei optionalen Status-LEDs gemäß Abschnitt 13.2 vollständig zu entfernen; die fünf Diagnose-LEDs aus Abschnitt 13.1 bleiben verpflichtend.
9. EN-/Resetlösung gegen langsame, unterbrochene und wechselnde Versorgung analysieren; Supervisor beziehungsweise PGOOD-Lösung festlegen.
10. PCBWay-Stackup, Impedanzregeln, Bauteilverfügbarkeit und beidseitige Bestückbarkeit für fünf Stück bestätigen.
11. PCBWay-Prozessfolge so bestätigen, dass das WROOM-1U trotz beidseitiger Bestückung genau einen Reflow-Zyklus durchläuft und die MSL-3-Handhabung eingehalten wird.

Es bestehen keine weiteren offenen Funktionsentscheidungen des Auftraggebers. Architektur, GPIO-Belegung und wesentliche Herstellerteilenummern sind in Phase 1 festgelegt. Die in diesem Abschnitt genannten Berechnungen, Messungen, Beschaffungs- und mechanischen Prüfungen bleiben bis zu ihrer dokumentierten Verifikation offen. Änderungen am vorgegebenen Funktionsumfang, an Versorgung, Display, Schnittstellen oder Mechanik bedürfen einer neuen Dokumentrevision.

## 21. Spätere Revisionen – nicht Teil des Auftrags

Für eine spätere Revision sind vorgemerkt:

- VOTRONIC `VBCS 45/30/350 Triple CI`,
- VOTRONIC `Smart-Shunt 100 A`.

Vor deren Integration müssen Original-Pinbelegung, elektrische Pegel, Busversorgung, Halb-/Vollduplex, Terminierung, galvanische Trennung und Protokoll belastbar verifiziert werden. Die bisherige Annahme „Standard-RS-485“ genügt nicht als Schaltungsgrundlage. Beide Geräte dürfen nicht ohne Nachweis auf denselben Bus gelegt werden.

## 22. Referenzen

- [LandyHeater Repository](https://github.com/fabianhartmann2/LandyHeater/tree/main)
- [Espressif ESP32-S3-WROOM-1/1U Datasheet](https://documentation.espressif.com/esp32-s3-wroom-1_wroom-1u_datasheet_en.pdf)
- [Espressif ESP32-S3 Schematic Checklist](https://docs.espressif.com/projects/esp-hardware-design-guidelines/en/latest/esp32s3/schematic-checklist.html)
- [Espressif ESP32-S3 PCB Layout Design](https://docs.espressif.com/projects/esp-hardware-design-guidelines/en/latest/esp32s3/pcb-layout-design.html)
- [Espressif ESP32-S3 Sleep Modes und EXT1-Wakeup](https://docs.espressif.com/projects/esp-idf/en/stable/esp32s3/api-reference/system/sleep_modes.html)
- [USB-IF USB Type-C Specification Release 2.0](https://www.usb.org/sites/default/files/USB%20Type-C%20Spec%20R2.0%20-%20August%202019.pdf)
- [Predictable Designs PCB Layout Rules Checklist](https://predictabledesigns.com/pcb-layout-rules-checklist.pdf)
- [TI LMR43620-Q1](https://www.ti.com/product/LMR43620-Q1)
- [TI LM74720-Q1](https://www.ti.com/product/LM74720-Q1)
- [TI TPS25947](https://www.ti.com/product/TPS25947)
- [TI TUSB321](https://www.ti.com/product/TUSB321)
- [TI TPS3808-Q1](https://www.ti.com/product/TPS3808-Q1)
- [TI TPS7A02](https://www.ti.com/product/TPS7A02)
- [TI TPS22919-Q1](https://www.ti.com/product/TPS22919-Q1)
- [TI TXU0202-Q1](https://www.ti.com/product/TXU0202-Q1)
- [Diodes Incorporated BCR420/BCR421UW6Q](https://www.diodes.com/datasheet/download/BCR420UW6Q.pdf)
- [Micro Crystal RV-3028-C7](https://www.microcrystal.com/en/products/real-time-clock-rtc-modules/rv-3028-c7)
- [Panasonic BR1225](https://industrial.panasonic.com/ww/products/pt/lithium-batteries/models/BR1225)
- [Molex Nano-Fit](https://www.molex.com/en-us/products/connectors/wire-to-board-connectors/nano-fit-connectors)
- [Hirose FH12](https://www.hirose.com/product/series/FH12)
- [APEM AV Illuminated Pushbuttons](https://www.apem.com/api/asset/en/fbCPLUNNnaEJPS7JlAtdy/pusbutton-switches-serie-AV.pdf)
- [Good Display GDEY029T94-FT01](https://www.good-display.com/product/616.html)
- [Good Display GDEY029T94-FT01 Specification, Revision 1.0](https://v4.cecdn.yun300.cn/100001_1909185148/GDEY029T94-FT01.pdf)
- [FocalTech FT6336U Self-Capacitive Touch Panel Controller Datasheet, Version 1.0](https://v4.cecdn.yun300.cn/100001_1909185148/FT6336U-DataSheet-V1.0.pdf)
- [Analog Devices – Guidelines for Reliable Long-Line 1-Wire Networks](https://www.analog.com/en/resources/technical-articles/guidelines-for-reliable-long-line-1wire-networks.html)

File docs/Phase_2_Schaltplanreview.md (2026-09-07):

# Phase 2 – KiCad-Schaltplan und unabhängiger Review

Stand: 2026-09-06

Normative Grundlage: [Hardware-Anforderungsspezifikation Revision A](Hardware-Anforderungsspezifikation_Revision_A.md), Dokumentversion 1.6

Status: **elektrisch, strukturell und intern visuell geprüft, aber wegen offener Freigabegates und ausstehender Abnahme nicht für Phase 3 oder Fertigung freigegeben**

## 1. Ergebnis

Der erste automatisch erzeugte, rasterartige und überwiegend labelbasierte Entwurf wurde verworfen. Der aktuelle Stand ist ein neuer, editierbarer KiCad-10-Schaltplan mit funktionsorientierter Seitenaufteilung. Lokale Verbindungen innerhalb eines Funktionsblocks sind als sichtbare Leitungen gezeichnet; Labels dienen nur Seitenübergängen, globalen Spannungsdomänen, Einzelanschlüssen und bewusst entfernten Verbindungen. Quellen, Schutzglieder, Regler/Schalter, Filter und Verbraucher sind vorzugsweise von links nach rechts angeordnet. Versorgungssymbole liegen oben, sichtbare GND-Symbole unten. Steckverbinder schließen die jeweiligen Signalpfade am Blockrand ab.

Der Schaltplan umfasst:

- 7 Seiten,
- 232 eindeutige Referenzen, davon 56 ausdrücklich DNP,
- 141 gruppierte BOM-Zeilen,
- 0 ERC-Fehler und 0 ERC-Warnungen,
- 0 im Export-Audit erkannte unterbrochene oder ungewollt verschmolzene Sollnetze,
- 651 angeschlossene Pins in 175 Netzen vor und nach der grafischen Überarbeitung; identischer Topologie-Hash,
- Footprint-Zuordnung für jede Referenz.

Die automatischen Ergebnisse sind in `build/reports/erc.rpt` und `build/reports/phase2-audit.txt` reproduzierbar. Sie ersetzen weder Worst-Case-Auslegung noch die Prüfung der herstellerspezifischen Landpatterns.

Der Review erfolgte in drei getrennten Durchgängen: zuerst blockweise gegen Pinout, Referenzschaltung und Grenzwerte; anschließend systemweit über Spannungsdomänen, ausgeschaltete Zustände, Backfeeding, DNP-Kombinationen und die vollständig exportierte Pin-Netz-Matrix; zuletzt als visueller Review jeder einzelnen aus KiCad gerenderten A4-Seite. Der elektrische Durchgang entdeckte unter anderem unzulässige Verschmelzungen, die der ERC allein nicht gemeldet hatte; die Generatorlogik wurde daraufhin korrigiert und der Netzlisten-Audit als dauerhafte Regressionprüfung ergänzt.

## 2. Visueller A4-Review vom 2026-09-07

Alle sieben Seiten des final exportierten PDFs wurden mit 150 dpi gerendert und einzeln geprüft:

| Seite | Visuell verfolgter Hauptpfad | Ergebnis |
|---|---|---|
| 1 | 12 V/USB → VIN_SYS/3V3 → ESP32, Display, Touch, AUTOTERM/1-Wire und Controls | bestanden |
| 2 | J1 → TVS → LM74720-Q1 → Back-to-back-FET → Filter → VIN_SYS; USB-C → CC/eFuse/Rückstromsperre → VIN_SYS; VIN_SYS → Buck → 3V3_CORE | bestanden |
| 3 | Supervisor/RESET/BOOT, natives USB, ESP32 und E-Paper-Signalkonditionierung | bestanden |
| 4 | Display-Lastschalter, Power-off-Isolation, Referenz-Booster und J6 | bestanden |
| 5 | Always-on-Touchversorgung, Reset/FPC, direkter/optionaler Wake-Pfad und RTC-Backup | bestanden |
| 6 | ESP32 ↔ Pegelwandler ↔ Serienglieder ↔ ESD ↔ J2 sowie Sensorlastschalter ↔ Pull-up/Schutz ↔ J3 | bestanden |
| 7 | Externer Taster/Ring-LED, Frontlicht und DIAG-geschaltete Energieflussanzeige | bestanden |

Die PDF hat sieben Seiten im Format A4. Funktionsrahmen und Überschriften sind auf jeder Funktionsseite vorhanden. Der Generator bricht künftig mit einem Fehler ab, falls ein lokales Mehrpunktnetz nicht mit sichtbaren Leitungen geroutet werden kann; ein stiller Rückfall auf ein Label an jedem Bauteilende ist nicht mehr möglich.

## 3. Seitenstruktur

| Seite | Datei | Funktion |
|---|---|---|
| 1 | `LandyHeater-Board.kicad_sch` | Hierarchie und Funktionsübersicht |
| 2 | `01_Power_Input_USB.kicad_sch` | 12-V-Schutz, USB-C-Sink/eFuse, Power-OR, 3,3-V-Buck |
| 3 | `02_ESP32_USB_Reset.kicad_sch` | ESP32-S3, natives USB, Supervisor, BOOT/RESET, Signalserienglieder |
| 4 | `03_Display_EPaper.kicad_sch` | Display-Lastschalter, Pegelisolation, E-Paper-Booster, J6 |
| 5 | `04_Touch_RTC.kicad_sch` | 3,0-V-AON, Touch, optionale Wake-Latch-Variante, RTC/BR1225 |
| 6 | `05_AUTOTERM_1Wire.kicad_sch` | AUTOTERM-5-V-UART und geschützter 1-Wire-Bus |
| 7 | `06_Controls_Diagnostics.kicad_sch` | 3-m-Taster, dimmbare Ring-LED, Frontlicht, Energieflussanzeige |

## 4. Wesentliche Reviewkorrekturen

| Bereich | Korrektur |
|---|---|
| 12-V-Schutz | LM74720-Q1 nach TI-Grundschaltung ergänzt: 0-Ω-PD/Gate-Verbindung, 100 Ω plus 10 nF nach GND für Gate-Slew und 18-V-VGS-Klemme. RTN/EP bleibt elektrisch offen und verwendet deshalb den WSON-Footprint ohne Thermal Vias. |
| USB-Stromerkennung | TUSB321-Open-Drain-Pull-ups liegen nur an USB_VBUS. Q8 entkoppelt die unversorgte USB-Domäne von 3V3; GPIO40 ist jetzt `USB_HIGH_CURRENT`, active HIGH. |
| USB-eFuse | TPS259470L mit 1-A-Nennlimit, ca. 5,82-V-OVLO und 10-nF-dV/dt-Kondensator; USB-VBUS und VIN_SYS bleiben durch die echte Rückstromsperre getrennt. |
| 3,3-V-Buck | L2 auf `XAL4020-222MEC`, 2,2 µH/5,6 A Isat, geändert; 2 × 22 µF am Ausgang und ein konkreter 4,7-µF-/50-V-X7R-Eingangskondensator vorgesehen. |
| ESP32 | N16R8-Padbelegung, Octal-PSRAM-Reservierung, USB GPIO19/20, EN/BOOT und 2 × 22 µF lokale Pufferung geprüft. |
| E-Paper | C37 liegt korrekt zwischen PREVGL und GND; unbenutzte A6…A8 des 8-Bit-Pegelwandlers sind an GND; lokale VCCA/VCCB-Abblockung ergänzt. |
| ESD-Arrays | PESD5V2S2UT-Q und PESD3V3S2UT-Q korrigiert: Pins 1/2 an den geschützten Leitungen, gemeinsamer Anodenpin 3 an GND. |
| AUTOTERM | J2 = 5 V, GND, TX zur Heizung, RX von der Heizung. Die B-Seite des TXU0202 wird ausschließlich aus dem geschützten heizungsseitigen 5-V-Zweig gespeist. |
| 1-Wire | J3 = geschaltete 3,3 V, DQ, GND; 4,7-kΩ-Pull-up und bestückter 0-Ω-Abgleichlink vor GPIO4. |
| Ring-LED | `BCR421UW6Q-7` ersetzt den ungeeigneten BCR420/MOSFET-Aufbau. PWM erfolgt direkt am EN-Pin, hardwareseitig default AUS. |
| Frontlicht | AL8861 erhält 10 µF/100 V X7R lokal, 47-µH-Induktivität und automotive `B140Q-13-F`; Sollstrom 50 mA nominal. |
| Diagnose | USB-LED misst rohes USB_VBUS, nicht das zusammengeführte VIN_SYS. Der DIAG-Gateteiler begrenzt Q5-VGS auch an der maximalen OV-Abschaltschwelle. |

## 5. Hardwarezustände ohne Firmware

| Funktion | Zustand |
|---|---|
| ESP32 EN | TPS3808 überwacht 3V3; CT offen ergibt nominal 20 ms Verzögerung; RESET zieht MR low |
| BOOT | 10 kΩ high; nur lokaler BOOT-Taster zieht GPIO0 low |
| Display | `DISPLAY_EN` 100 kΩ low; Displayversorgung aus; Pegelwandler-Ausgänge hochohmig |
| Touch | 3,0-V-AON bleibt versorgt; Reset wird über Open Drain gesteuert; direkter INT-Pfad ist Standard |
| Sensoren | `SENSOR_EN` low; 1-Wire-Sensorversorgung aus |
| AUTOTERM | `AUTOTERM_OE` low; TX zur Heizung hochohmig |
| Frontlicht | PWM/VSET 100 kΩ low; aus |
| Taster-Ring | BCR421-EN 100 kΩ low; aus |
| Energiefluss-LEDs | gemeinsamer Diagnosepfad aus, solange DIAG nicht gedrückt/überbrückt ist |
| optionale Status-LEDs | Bauteile DNP |

## 6. DNP-Varianten

- Standard-Touch-Wake: R28 und R29 bestückt; R30, R71 und die gesamte Latch-Gruppe U13/C39/R31/R69/R70 DNP.
- Latch-Variante erst nach Messung: U13/C39/R31/R69/R70 bestücken und R28/R29/R30/R71 nicht bestücken.
- C40/C41 und C42…C46 sind ausschließlich unbestückte USB-/SPI-Tuningplätze.
- LED6/R52 und LED7/R53 sind optionale Statusanzeigen.
- TP1…TP38 sind DNP-Testpunkte ohne aufgelötete Buchsen.

## 7. Freigabesperren

Phase 2 ist aktuell **nicht freigabefähig**. Vor Phase 3 müssen mindestens folgende Punkte geschlossen werden:

1. Offizielle Landpatterns/ECAD-Modelle für Q1 (Infineon PG-TDSON-8-4 Dual), U3 (TI RPW), U4 (TI RPE), RV-3028 sowie L3/L4 geometrisch übernehmen und unabhängig prüfen.
2. FPC-Kontaktseite, Pin 1, FPC-Dicke und Einsteckrichtung von J6/J7/J8 am Originaldisplay bestätigen.
3. Fahrzeug-/Kabelbaum-Transientenprofil definieren und TVS-Klemmung, LM74720-FET-SOA, Filterdämpfung und Einschaltstrom rechnerisch/simulatorisch freigeben.
4. Effektive MLCC-Kapazitäten bei DC-Bias und Temperatur prüfen; Buck-Stabilität, Lastsprung und Ripple anschließend simulieren oder messen.
5. Touch-INT-Pulsdauer und Wake-Zuverlässigkeit am Originaldisplay messen; Standardpfad oder Latch-Bestückung festlegen.
6. AL8861-Stromwelligkeit, Temperatur und Frontlight-FPC-Polarität am Muster prüfen.
7. APEM-Code `AV970220000700`, Kontaktbelegung, LED-Polarität und LED-Flussspannung am bestellten Muster bestätigen.
8. Verfügbarkeit der exakten MPNs bei PCBWay klären; keine automatische Substitution kritischer Teile zulassen.

Details und quantitative Grenzen stehen in [Worst-Case-Berechnungen Phase 2](../calculations/Phase_2_Worst-Case-Berechnungen.md), die Quellenzuordnung in [Quellen und Rückverfolgbarkeit](Phase_2_Quellen-und-Rueckverfolgbarkeit.md).

## 8. Reproduzierbarkeit

```text
python3 scripts/generate_phase2_schematic.py
make sch-check
make export-phase2
```

`make export-phase2` erzeugt PDF, BOM und Netzliste und prüft anschließend jede exportierte Pin-Netz-Zuordnung gegen die kanonische Schaltungsdefinition. Zusätzlich vergleicht der Audit die elektrische Topologie mit dem unmittelbar vor der grafischen Überarbeitung gesicherten Stand. Das Ergebnis ist in [`LandyHeater-Board-Netlist-Comparison-Phase2.txt`](../output/reports/LandyHeater-Board-Netlist-Comparison-Phase2.txt) dokumentiert. Der Generator überschreibt die sieben Schaltplandateien; spätere manuelle KiCad-Änderungen müssen deshalb entweder zurück in den Generator übertragen oder der Generator bewusst stillgelegt werden.

Im ERC sind nur generische, für diesen Projektstand begründete Prüfklassen deaktiviert: einzeln vorkommende globale Labels (Test-/Seitenanschlüsse), Vierfach-Knoten (parallel geführte Versorgungs-/Gehäusepins), SPICE-Modelle (keine SPICE-Netzliste als Freigabenachweis) und Footprint-Filter (projektlokale kontrollierte Footprints). Konkrete ERC-Meldungen sind nicht einzeln unterdrückt; der Bericht enthält 0 Fehler und 0 Warnungen.

## 9. Phase-2-Freigabekriterien

- [x] lesbarer hierarchischer Funktionsschaltplan
- [x] interner visueller Review aller sieben aus KiCad gerenderten A4-Seiten
- [x] eindeutige Referenzen, Pinbelegungen und Footprints
- [x] sichere Defaultzustände und DNP-Varianten dokumentiert
- [x] ERC ohne Fehler/Warnungen
- [x] exportierte Netzliste ohne Sollnetz-Unterbrechung oder Netzverschmelzung
- [x] elektrische Pin-zu-Pin-Topologie vor/nach grafischer Überarbeitung identisch
- [x] BOM mit Footprint sowie MPN für aktive/elektromechanische/induktive Bauteile
- [x] Schaltplan-PDF und BOM reproduzierbar exportiert
- [ ] alle Punkte aus Abschnitt 7 geschlossen
- [ ] unabhängige Phase-2-Freigabe durch Auftraggeber/PCB-Designer

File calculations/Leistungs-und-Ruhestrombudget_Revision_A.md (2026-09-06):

# Leistungs-, USB- und Ruhestrombudget – Revision A

Stand: 2026-09-06

Status: Phase-2-Reviewstand; garantierter Ruhestrom und dynamische Lastfälle in Phase 6 durch Messung zu bestätigen

## 1. Ziele

- `3V3_CORE` muss ESP32-WLAN-Spitzen und alle vorgesehenen Nebenlasten ohne Brownout versorgen.
- Die USB-eFuse und das Board begrenzen den USB-Betrieb auf höchstens 1 A.
- Bei USB-Default-Current muss natives USB-Flashing innerhalb 500 mA möglich sein.
- Der Komfort-Standby soll am 12-V-Eingang weniger als 0,5 mA aufnehmen.
- Die BR1225 muss die RTC ohne externe Versorgung mindestens vier Wochen betreiben.

Alle Werte in diesem Dokument sind Engineering-Budgets, keine gemessenen Produkteigenschaften. Typische Datenblattwerte werden ausdrücklich nicht als garantierte Maximalwerte ausgegeben.

## 2. Lastbudget im Normalbetrieb

| Verbrauchergruppe | Versorgung | Auslegungsstrom | Grundlage |
|---|---:|---:|---|
| ESP32-S3-WROOM-1U, WLAN-Spitzen | 3,3 V | 500 mA | Espressif-Mindestdimensionierung der Modulversorgung; konservatives Boardbudget |
| E-Paper-Logik und Booster aus geschalteter Rail | 3,3 V | 50 mA | Designreserve; am Muster messen |
| FT6336U aktiv | 3,0 V | 10 mA | oberhalb 4,32 mA typ. laut Datenblatt |
| drei DS18B20 + Kabelbus | 3,3 V | 10 mA | drei Wandlungen plus Reserve |
| RTC, Supervisor, Pegelwandler, Isolation, Pulls | 3,0/3,3 V | 10 mA äquivalent | Sammelreserve |
| Diagnose-/Status-LEDs bei DIAG beziehungsweise aktiv | 3,3 V äquivalent | 10 mA | fünf Diagnose-LEDs mit 0,5…1 mA plus zwei optionale Status-LEDs |
| **Summe 3,3-V-äquivalent** | | **590 mA** | gerundet |
| **Auslegungswert mit 30 % Reserve** | | **767 mA** | `590 mA × 1,30` |

Der festgelegte `LMR43620MSC3RPERQ1` mit 2 A Nennstrom bietet damit einen Faktor von rund 2,6 gegenüber dem reservierten 767-mA-Dauer-/Spitzenbudget. Diese Reserve ist für WLAN-Lastsprünge, Kondensatortoleranzen und noch zu messende E-Paper-Impulse bestimmt; sie ist keine Freigabe für externe Lasten.

Frontlicht und externe Ring-LED werden nicht aus `3V3_CORE`, sondern direkt aus `VIN_SYS` gespeist:

- Frontlicht: 50 mA bei etwa 3,0 V LED-Leistung, also 0,15 W.
- Externe Ring-LED: 10 mA Konstantstrom; etwa 3 V an der LED.

## 3. USB-Lastfälle

### 3.1 Vollbetrieb bei mindestens 1,5-A-Ankündigung

Konservative Annahmen: 767 mA an 3,3 V, 85 % Buckwirkungsgrad bei 5 V, 80 % Frontlichttreiberwirkungsgrad.

```text
I_USB,3V3 = 0,767 A × 3,3 V / (5,0 V × 0,85) = 0,596 A
I_USB,Frontlicht = 0,050 A × 3,0 V / (5,0 V × 0,80) = 0,038 A
I_USB,Ring-LED = 0,010 A
USB-Controller/eFuse/Reserve = 0,006 A
--------------------------------------------------------------
I_USB,Vollbetrieb ≈ 0,650 A
```

Damit verbleiben rund 350 mA Abstand zur normalen Boardgrenze von 1 A. Die eFuse wird nominal auf 1 A eingestellt und dient der Einschalt- und Fehlerstrombegrenzung. TI spezifiziert ihre ±10-%-Genauigkeit erst oberhalb 1 A; deshalb wird die normale 1-A-Grenze durch die festgelegte Lastfreigabe, das 0,65-A-Budget und die Messung nachgewiesen. Die eFuse darf nicht als präziser 1-A-Abschalter beschrieben werden.

### 3.2 USB-Default-Current / Flashbetrieb

Bis `TUSB321A` mindestens 1,5 A erkannt hat, sind Display-Aktualisierung, Frontlicht, Sensorversorgung und externe Ring-LED aus. Für den ESP32 werden trotzdem 500 mA an 3,3 V als konservative Spitze angesetzt:

```text
I_USB,ESP32 = 0,500 A × 3,3 V / (5,0 V × 0,85) = 0,388 A
RTC, Supervisor, USB-Controller, eFuse und Reserve       < 0,032 A
---------------------------------------------------------------
I_USB,Flashbetrieb, Budget                             < 0,420 A
```

Das Budget liegt unter 500 mA. Einschaltstrom und tatsächliche WLAN-/USB-Spitzen werden am Prototyp gemessen. Die Firmware muss die USB-Stromstufe vor Zuschalten der erweiterten Lasten auswerten; Hardware-Pulldowns halten diese Lasten bis dahin aus.

### 3.3 Quellenumschaltung

Bei gleichzeitigem Anschluss von 12 V und USB liegt `VIN_SYS` auf dem höheren geschützten 12-V-Pfad. Der USB-eFuse-Ausgang sperrt Rückstrom. Für die Prüfung werden Ströme in beide Quellstecker bei allen Anschluss- und Abschaltfolgen gemessen; zulässige Leckströme werden nach den finalen Datenblattgrenzen bewertet.

## 4. 12-V-Last und Verlustleistung

Mit 90 % angenommenem Buckwirkungsgrad bei 12 V ergibt sich für das reservierte 3,3-V-Lastbudget:

```text
I_12V,3V3 = 0,767 A × 3,3 V / (12 V × 0,90) = 0,234 A
I_12V,Frontlicht = 0,050 A × 3,0 V / (12 V × 0,80) = 0,016 A
I_12V,Ring-LED = 0,010 A
Controller und Reserve ≈ 0,010 A
-----------------------------------------------------------
I_12V,Vollbetrieb ≈ 0,270 A
```

Die externe 1-A-Sicherung besitzt somit reichlich Betriebsreserve. Sie schützt die Leitung; sie ersetzt nicht die lokale Strombegrenzung an USB, Sensor- und AUTOTERM-Zweig.

### 4.1 Erste Verlustleistungsabschätzung

| Bauteil/Pfad | Rechenfall | Verlust |
|---|---|---:|
| LMR43620-Q1 aus 12 V | 2,53 W Ausgang, 90 % | ca. 0,28 W |
| LMR43620-Q1 aus USB | 2,53 W Ausgang, 85 % | ca. 0,45 W |
| zwei Schutz-MOSFETs | 0,30 A, je 26 mΩ max. | ca. 4,7 mW |
| TPS259470 eFuse | 0,65 A, 28,3 mΩ typ. | ca. 12 mW |
| Frontlichttreiber | 0,15 W LED-Leistung, 80 % | ca. 38 mW |
| Ring-LED-Konstantstromquelle | 14 V, VF = 2,6 V, 11 mA oberer Rechenwert | ca. 125 mW im BCR421 |
| 3,0-V-LDO | 10 mA aktiv, 0,3 V Drop | ca. 3 mW |

Die Buckverluste sind der thermisch dominante normale Rechenfall. Das Layout muss das Exposed Pad nach Herstellerempfehlung anbinden. In Phase 2 werden Datenblatt-/Herstellertoolwerte über 10 V, 12 V, 14 V und USB sowie Temperatur und Bauteiltoleranz gerechnet; in Phase 6 folgen Wärmebild beziehungsweise Temperaturmessung im Gehäuse.

## 5. Komfort-Standby bei 12 V

Displayrail, Sensorrail, Frontlicht, Ring-LED, Diagnoseanzeige und AUTOTERM-OE sind aus. Der FT6336U bleibt an `3V0_TOUCH_AON` im Monitor-Modus. Weil das Touch-Datenblatt für 220 µA nur einen typischen Wert nennt, wird für das Budget das Doppelte verwendet; dies ist eine Engineering-Reserve, kein garantierter Worst Case.

### 5.1 Direkt am Eingang verbleibende Lasten

| Anteil | Budget bei 12 V |
|---|---:|
| LM74720-Q1, Datenblatt-Maximum | 38 µA |
| AL8861Q abgeschaltet, Datenblatt-Maximum | 100 µA |
| BCR421 und Diagnosezweig aus, Leckstromreserve | 10 µA |
| TVS, eFuse-Rückseite und Eingangsfilter-Leckage | 5 µA |
| **Zwischensumme vor Buck** | **153 µA** |

### 5.2 Lasten hinter dem Buck, auf 3,3 V äquivalent

| Anteil | 3,3-V-äquivalentes Budget |
|---|---:|
| ESP32-S3 Deep-Sleep einschließlich Boardreserve | 50 µA |
| FT6336U Monitor: 2 × 220 µA bei 3,0 V | 400 µA |
| 3,0-V-LDO Eigenstrom | 1 µA |
| TPS3808 Supervisor | 4 µA |
| RTC-Hauptversorgung und I2C | 2 µA |
| TXU0202, Display-Isolation, Touch-Reset-Puffer | 70 µA |
| ausgeschaltete Lastschalter | 3 µA |
| Pulls, Schutzleckströme und Restreserve | 64 µA |
| **Summe** | **594 µA** |

Für die Umrechnung wird wegen des sehr kleinen Lastpunkts bewusst nur 65 % PFM-Wirkungsgrad angenommen und zusätzlich 3 µA Eigenstrom des Bucks angesetzt:

```text
I_12V,hinter Buck = 0,594 mA × 3,3 V / (12 V × 0,65) + 0,003 mA
                  = 0,254 mA
I_12V,Komfort = 0,254 mA + 0,153 mA = 0,407 mA
```

Das Rechenbudget liegt nur rund 0,09 mA unter dem Ziel von 0,5 mA. Es ist nicht als garantierter Worst Case zu verstehen, weil der FT6336U keine maximale Monitorstromangabe enthält, der BCR421-Aus-Leckstrom noch nicht als vollständiger Temperatur-Worst-Case eingesetzt ist und der tatsächliche Buck-Wirkungsgrad im Sub-mA-Bereich vom Aufbau abhängt. Der Abnahmewert wird daher ausschließlich durch Messung aller fünf Prototypen bei 12 V bestimmt. Falls das Ziel verfehlt wird, ist ein Lastschalter für den AL8861-Zweig eine mögliche Revision-B-Maßnahme.

## 6. Minimal-Standby

Für FT6336U-Hibernation werden vorsichtshalber 2 × 55 µA bei 3,0 V angesetzt, entsprechend 100 µA auf 3,3 V umgerechnet. Gegenüber dem Komfort-Standby sinkt die äquivalente Bucklast damit um etwa 300 µA:

```text
I_12V,Minimal ≈ 153 µA + ((294 µA × 3,3 V) / (12 V × 0,65) + 3 µA)
               ≈ 280 µA
```

Das Ergebnis ist ein Zielwert, kein Abnahmemaximum. Touch kann in diesem Zustand nicht wecken; der externe Taster bleibt aktiv.

## 7. RTC-Backupzeit

Die Panasonic BR1225 besitzt nominal etwa 48 mAh. Für einen absichtlich sehr konservativen Nachweis werden nur 10 % der Nennkapazität und 0,5 µA Gesamtlast aus RTC, Sperrdiode, Halter-/PCB-Leckage und Alterung angesetzt:

```text
t = 4,8 mAh / 0,0005 mA = 9 600 h = 400 Tage
```

Selbst diese starke Derating-Annahme übertrifft die geforderten vier Wochen um mehr als den Faktor 14. Der reale Backupstrom wird bei entfernter externer Versorgung gemessen. Die Zelle wird erst nach Löt- und Reinigungsprozess eingesetzt und darf hardwareseitig nicht geladen werden.

## 8. Mess- und Freigabekriterien

1. USB-Default-Current: Start, natives Flashen und WLAN-Spitze kleiner 500 mA, erweiterte Lasten aus.
2. USB mit mindestens 1,5-A-CC: Vollbetrieb kleiner 1 A; nominale eFuse-Stromgrenze und Kurzschlussabschaltung funktionieren innerhalb der Datenblatttoleranz.
3. 12-V-Vollbetrieb bei 10/12/14 V einschließlich WLAN, Frontlicht, Display und Ring-LED; kein Brownout.
4. `3V3_CORE`-Transient am Modul bei WLAN-TX und Displaystart bleibt zwischen 3,0 V und 3,6 V.
5. Komfort-Standby kleiner 0,5 mA am 12-V-Stecker nach stabiler Einschwingzeit.
6. Minimal-Standby ist messbar niedriger als Komfort-Standby.
7. Rückstrom in USB-, Batterie- und AUTOTERM-Port in jeder Quellenfolge messen.
8. Temperatur von Buck, Schutz-MOSFETs, eFuse, Frontlichttreiber und Ring-LED-CCR im finalen Gehäuse prüfen.
9. RTC-Backupstrom messen und Backupzeit mit Zellen-Derating neu berechnen.

Die detaillierten Grenzwertrechnungen und offenen Nachweise stehen in [Phase 2 – Worst-Case-Berechnungen](Phase_2_Worst-Case-Berechnungen.md).

## 9. Datenblätter

- [Espressif ESP32-S3-WROOM-1/1U Datasheet](https://documentation.espressif.com/esp32-s3-wroom-1_wroom-1u_datasheet_en.pdf)
- [TI LMR43620-Q1](https://www.ti.com/product/LMR43620-Q1)
- [TI LM74720-Q1](https://www.ti.com/product/LM74720-Q1)
- [TI TPS25947](https://www.ti.com/product/TPS25947)
- [FocalTech FT6336U Datasheet](https://v4.cecdn.yun300.cn/100001_1909185148/FT6336U-DataSheet-V1.0.pdf)
- [Micro Crystal RV-3028-C7](https://www.microcrystal.com/en/products/real-time-clock-rtc-modules/rv-3028-c7)
- [Panasonic BR1225](https://industrial.panasonic.com/ww/products/pt/lithium-batteries/models/BR1225)

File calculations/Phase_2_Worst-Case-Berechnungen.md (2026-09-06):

# Phase 2 – Worst-Case-Berechnungen Revision A

Stand: 2026-09-06

Statuskennzeichnung: **ERFÜLLT** bedeutet mit Datenblattgrenzen rechnerisch abgedeckt. **NICHT VERIFIZIERT** bedeutet, dass eine notwendige Herstellerkurve, Systemannahme, Simulation oder Messung fehlt. Ein typischer Wert wird nie als garantierter Grenzwert ausgegeben.

## 1. LM74720-Q1 Überspannungsabschaltung

Bestückung: R1 = 100 kΩ ±1 %, R2 = 7,15 kΩ ±1 %. Aus TI: OV-Schwelle 1,13…1,33 V, konservativ zusätzlich ±1 µA OV-Pinleckstrom.

`VIN(OV) = VOV × (1 + R1/R2) ± ILEAK × R1`

| Fall | Ergebnis |
|---|---:|
| nominal, VOV = 1,231 V | 18,45 V |
| niedrigste Abschaltung, R1 −1 %, R2 +1 %, VOV min., Leckstrom ungünstig | 16,52 V |
| höchste Abschaltung, R1 +1 %, R2 −1 %, VOV max., Leckstrom ungünstig | 20,41 V |

Der garantierte 10…14-V-Betriebsbereich liegt unter der minimalen Abschaltschwelle: **ERFÜLLT**. Die höchste mögliche Weitergabespannung, TVS-Klemmung und dynamische Überschwinger bestimmen jedoch MOSFET-, Buck- und Kondensatorstress: **NICHT VERIFIZIERT**, bis das Eingangspulsprofil und die Quellenimpedanz festgelegt sind.

Die 18-V-Zenerdiode D17 liegt von Q2-Gate zu dessen Source/geschütztem Ausgang. R74 = 100 Ω und C4 = 10 nF nach GND entsprechen der Funktion von TI Figure 9-1. Die resultierende Inrush-/SOA-Koordination hängt von der gesamten effektiven Ausgangskapazität und dem MOSFET ab: **NICHT VERIFIZIERT**.

## 2. TVS und Eingangsfilter

D1 `TPSMB18CA-VR`: VRWM 18 V, Breakdown- und Klemmwerte gemäß ST-Datenblatt. Die TVS-Wahl schützt den nominalen 14-V-Betrieb vor normalem Leiten. Ohne definierte Pulsform, Quellimpedanz, Kabelinduktivität und Wiederholrate können Pulsstrom, Energie und reale Klemmspannung nicht seriös bestimmt werden.

Ergebnis: Bauteilklasse plausibel, aber TVS-Energie, Temperatur, LM74720-Abschaltdynamik, Q1-SOA und das Ferrit-/Kondensator-Netz sind **NICHT VERIFIZIERT**. Dies ist eine Phase-3-Sperre, kein stillschweigend bestandener Nachweis.

## 3. USB-eFuse TPS259470L

### 3.1 Stromgrenze

R9 = 3,32 kΩ ±1 %. Das aktuelle TI-Datenblatt spezifiziert für diesen Arbeitspunkt einen Stromgrenzbereich von ungefähr 0,85…1,15 A, typisch 1,007 A. Die Schaltung schützt daher gegen groben Überstrom, beweist aber nicht präzise eine USB-1-A-Dauergrenze.

Ergebnis: Schutzfunktion **ERFÜLLT**; maximale normale Boardaufnahme muss durch Laststeuerung und Messung ≤1 A bleiben.

### 3.2 OVLO

R7 = 100 kΩ ±1 %, R8 = 26,1 kΩ ±1 %, VOVLO = 1,183…1,223 V. Mit konservativ ±0,1 µA Pinleckstrom:

| Fall | Abschaltschwelle |
|---|---:|
| nominal | 5,82 V |
| Minimum | 5,62 V |
| Maximum | 6,01 V |

Der USB-5-V-Nennbereich wird nicht beschnitten und unzulässig hohe VBUS-Pegel werden vor VIN_SYS getrennt: **ERFÜLLT**.

### 3.3 Einschaltflanke

C8 = 10 nF. Nach TI-Näherung ergibt sich etwa 0,2 V/ms; 5 V werden in ca. 25 ms aufgebaut. Der reale Inrush ist `I = CLOAD × dV/dt` und muss mit der effektiven Gesamtkapazität hinter U3 geprüft werden. **NICHT VERIFIZIERT** bis zur DC-Bias-Auswertung und Messung.

## 4. 3,3-V-Buck LMR43620-Q1

Aus TI-Tabelle für feste 3,3 V/2,2 MHz: L2 = 2,2 µH, CIN = 4,7 µF + 100 nF, COUT = 2 × 22 µF. L2 `XAL4020-222MEC`: ±20 %, Isat 5,6 A. TI gibt als maximale High-Side-Spitzenstromgrenze 3,9 A an; 5,6 A > 3,9 A: Sättigungsreserve **ERFÜLLT**.

Konservative Induktivität 1,76 µH. Mit `ΔIL = VOUT × (1 − VOUT/VIN) / (L × f)` und 2,2 MHz:

| VIN | berechnete ΔIL p-p |
|---:|---:|
| 10 V | 0,57 A |
| 14 V | 0,65 A |
| 20,4 V bis zur maximalen OV-Abschaltung | 0,71 A |

Bei 2 A Last läge der rechnerische Spitzenstrom bei höchstens ca. 2,36 A und unter 3,9 A. Im vorgesehenen, deutlich kleineren normalen Lastbudget ist die Reserve größer.

Mit 2 × 22 µF, nur Kapazitätstoleranz −10 % und ohne ESR ergibt sich bei 14 V ideal etwa 0,94 mV Welligkeit. Diese Zahl ist **kein** fertiger Nachweis: DC-Bias, Temperatur, Leiterbahnparasiten, ESR, Lastsprung und Regelkreis müssen mit Herstellerkurven und realem Layout simuliert/gemessen werden. Stabilität/Ripple: **NICHT VERIFIZIERT**.
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

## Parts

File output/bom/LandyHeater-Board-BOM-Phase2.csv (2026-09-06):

Reference | Value | Footprint | Datasheet | Manufacturer | MPN | Assembly | Notes
BT1 | BR1225 HOLDER | Battery:BatteryHolder_Keystone_500 |  | Keystone | 500 | THT; cell fitted after assembly | Panasonic BR1225 primary cell
C1,C2 | 1uF 50V X7R | Capacitor_SMD:C_0805_2012Metric_Pad1.18x1.45mm_HandSolder |  |  |  | SMT
C3 | 100nF 50V X7R | Capacitor_SMD:C_0603_1608Metric_Pad1.08x0.95mm_HandSolder |  |  |  | SMT
C4 | 10nF 50V | Capacitor_SMD:C_0603_1608Metric_Pad1.08x0.95mm_HandSolder |  |  |  | SMT | PD slew to GND per LM74720-Q1 Figure 9-1; validate inrush/SOA
C5 | 4.7uF 50V X7R | Capacitor_SMD:C_0805_2012Metric_Pad1.18x1.45mm_HandSolder |  |  |  | SMT
C6 | 22uF 25V X7R | Capacitor_SMD:C_1210_3225Metric_Pad1.33x2.70mm_HandSolder |  |  |  | SMT
C7,C17,C19,C30,C32,C34,C47-C51,C53 | 100nF | Capacitor_SMD:C_0603_1608Metric_Pad1.08x0.95mm_HandSolder |  |  |  | SMT | U10 VCCA local bypass,U10 VCCB local bypass,U16 VCCA local bypass,U9 VCCA local bypass,U9 VCCB local bypass,U9 second VCCB-pin local bypass
C8,C35 | 10nF | Capacitor_SMD:C_0603_1608Metric_Pad1.08x0.95mm_HandSolder |  |  |  | SMT | 3m cable debounce/EMI; validate wake
C9 | 100nF 10V | Capacitor_SMD:C_0603_1608Metric_Pad1.08x0.95mm_HandSolder |  |  |  | SMT
C10 | 1uF 10V | Capacitor_SMD:C_0603_1608Metric_Pad1.08x0.95mm_HandSolder |  |  |  | SMT
C11 | 4.7uF 50V X7R 10% | Capacitor_SMD:C_1210_3225Metric_Pad1.33x2.70mm_HandSolder | https://www.murata.com/en-us/products/productdetail?partno=GCJ32ER71H475KA12%23 | Murata | GCJ32ER71H475KA12 | SMT | LMR43620 local input capacitor; DC-bias effective capacitance must be verified
C12 | 100nF 50V | Capacitor_SMD:C_0603_1608Metric_Pad1.08x0.95mm_HandSolder |  |  |  | SMT
C13-C16 | 22uF 10V X7R 10% | Capacitor_SMD:C_1206_3216Metric_Pad1.33x1.80mm_HandSolder |  | Murata | GCJ31CR71A226KE01 | SMT | ESP32 local bulk; effective capacitance must be verified,Effective capacitance at 3.3V/temperature must be verified
C18,C20,C28,C29,C31,C33 | 1uF | Capacitor_SMD:C_0603_1608Metric_Pad1.08x0.95mm_HandSolder |  |  |  | SMT | Espressif EN RC
C21,C26 | 4.7uF 25V | Capacitor_SMD:C_0805_2012Metric_Pad1.18x1.45mm_HandSolder |  |  |  | SMT | Good Display C4 input bypass
C22-C25,C27,C36-C38 | 1uF 25V | Capacitor_SMD:C_0805_2012Metric_Pad1.18x1.45mm_HandSolder |  |  |  | SMT | Good Display C11; VGL/PREVGL to GND
C39 | 100nF DNP | Capacitor_SMD:C_0603_1608Metric_Pad1.08x0.95mm_HandSolder |  |  |  | DNP | Power-on clear for optional wake latch
C40-C46 | 10pF C0G DNP | Capacitor_SMD:C_0603_1608Metric_Pad1.08x0.95mm_HandSolder |  |  |  | DNP | SPI edge-rate tuning; default DNP,USB SI tuning only; default DNP
C52 | 10uF 100V X7R 10% | Capacitor_SMD:C_1210_3225Metric_Pad1.33x2.70mm_HandSolder | https://product.tdk.com/en/search/capacitor/ceramic/mlcc/info?part_no=CGA6P1X7R2A106K250AC | TDK | CGA6P1X7R2A106K250AC | SMT | AL8861 local input capacitor; DC-bias effective capacitance must be verified
D1 | TPSMB18CA-VR | Diode_SMD:D_SMB | https://www.st.com/resource/en/datasheet/tpsmb.pdf | STMicroelectronics | TPSMB18CA-VR | SMT
D2 | ESD5Z5.0T1G | Diode_SMD:D_SOD-523 |  | onsemi | ESD5Z5.0T1G | SMT
D3-D5 | MBR0530T1G | Diode_SMD:D_SOD-123 |  | onsemi | MBR0530T1G | SMT | Good Display D1; KiCad diode pad 1 is K,Good Display D2; KiCad diode pad 1 is K,Good Display D3; KiCad diode pad 1 is K
D6,D11-D15 | BAS116,215 | Package_TO_SOT_SMD:SOT-23 |  | Nexperia | BAS116,215 | SMT
D7 | PESD5V2S2UT-Q | Package_TO_SOT_SMD:SOT-23 | https://assets.nexperia.com/documents/data-sheet/PESD5V2S2UT-Q.pdf | Nexperia | PESD5V2S2UT-Q | SMT | Pins 1/2 cathodes to signals; pin 3 common anode to GND
D8 | PESD3V3S2UT-Q | Package_TO_SOT_SMD:SOT-23 | https://assets.nexperia.com/documents/data-sheet/PESD3V3S2UT.pdf | Nexperia | PESD3V3S2UT-Q | SMT | Pins 1/2 cathodes to protected lines; pin 3 common anode to GND
D9 | PESD3V3S1BA | Diode_SMD:D_SOD-323 |  | Nexperia | PESD3V3S1BA | SMT | Bidirectional 3.3V ESD protection for 3m button wire
D10 | B140Q-13-F | Diode_SMD:D_SMA | https://www.diodes.com/assets/Datasheets/ds38236.pdf | Diodes Inc. | B140Q-13-F | SMT | Automotive 1-A/40-V Schottky; KiCad diode pad 1 is K
D16 | PESD24VL1BA,115 | Diode_SMD:D_SOD-323 |  | Nexperia | PESD24VL1BA,115 | SMT | Bidirectional 24V ESD protection; LED cathode may rise to VIN_SYS when off
D17 | BZT52H-C18-QX | Diode_SMD:D_SOD-123F | https://assets.nexperia.com/documents/data-sheet/BZT52H-Q_SER.pdf | Nexperia | BZT52H-C18-QX | SMT | 18-V Q2 VGS clamp per LM74720-Q1 Figure 9-1
FB1 | 220R@100MHz 3A | Inductor_SMD:L_0805_2012Metric_Pad1.05x1.20mm_HandSolder | https://product.tdk.com/system/files/dam/doc/product/emc/emc/beads/catalog/beads_commercial_power_mpz2012_en.pdf | TDK | MPZ2012S221A | SMT
J1 | 1053131302 / 12V INPUT | Connector_Molex:Molex_Nano-Fit_105313-xx02_1x02_P2.50mm_Horizontal |  | Molex | 1053131302 | THT
J2 | 1053131304 / AUTOTERM | Connector_Molex:Molex_Nano-Fit_105313-xx04_1x04_P2.50mm_Horizontal |  | Molex | 1053131304 | THT
J3 | 1053131303 / 1-WIRE | Connector_Molex:Molex_Nano-Fit_105313-xx03_1x03_P2.50mm_Horizontal |  | Molex | 1053131303 | THT
J4 | 1053131305 / BUTTON+LED | Connector_Molex:Molex_Nano-Fit_105313-xx05_1x05_P2.50mm_Horizontal |  | Molex | 1053131305 | THT | APEM AV970220000700 cable assembly; 3m; twist 1/2 and 3/4; pin 5 NC
J5 | USB4105-GF-A-120 | Connector_USB:USB_C_Receptacle_GCT_USB4105-xx-A_16P_TopMnt_Horizontal |  | GCT | USB4105-GF-A-120 | SMT
J6 | FH12-24S-0.5SH(55) E-PAPER | Connector_FFC-FPC:Hirose_FH12-24S-0.5SH_1x24-1MP_P0.50mm_Horizontal |  | Hirose | FH12-24S-0.5SH(55) | SMT | PROVISIONAL bottom-contact; verify original display
J7 | FH12-6S-0.5SH(55) TOUCH | Connector_FFC-FPC:Hirose_FH12-6S-0.5SH_1x06-1MP_P0.50mm_Horizontal |  | Hirose | FH12-6S-0.5SH(55) | SMT | PROVISIONAL pin/contact orientation; verify display
J8 | FH12-6S-0.5SH(55) FRONTLIGHT | Connector_FFC-FPC:Hirose_FH12-6S-0.5SH_1x06-1MP_P0.50mm_Horizontal |  | Hirose | FH12-6S-0.5SH(55) | SMT | PROVISIONAL pin/contact orientation; verify display
L1 | 100uH >175mA XPL2010-104ML | Inductor_SMD:L_0805_2012Metric_Pad1.05x1.20mm_HandSolder | https://www.coilcraft.com/getmedia/56fc2271-3bce-4dc9-808a-1edf9a322f75/xpl2010.pdf | Coilcraft | XPL2010-104ML | SMT | PROVISIONAL generic footprint; verify against Coilcraft land pattern before Phase 3
L2 | 2.2uH 5.6A Isat | Inductor_SMD:L_Coilcraft_XAL4020-XXX | https://www.coilcraft.com/getmedia/6adcb47d-8b55-416c-976e-1e22e0d2848c/xal4000.pdf | Coilcraft | XAL4020-222MEC | SMT | TI Table 8-2 fixed 3.3V/2.2MHz; 20% tolerance
L3,L4 | 47uH 570mA | LandyHeater:PROVISIONAL_Murata_LQH3NPZ_JR | https://www.murata.com/en-us/products/productdetail?partno=LQH3NPZ470MJR%23 | Murata | LQH3NPZ470MJR | SMT | AL8861 33..100uH range; footprint provisional pending official ECAD/land-pattern verification,Good Display chapter 12; footprint is provisional pending official ECAD/land-pattern verification
LED1 | 12V RED | LED_SMD:LED_0603_1608Metric |  | Lite-On | LTST-C190KRKT | SMT
LED2 | USB RED | LED_SMD:LED_0603_1608Metric |  | Lite-On | LTST-C190KRKT | SMT | Raw connector VBUS: indicates actual USB presence, not common VIN_SYS
LED3 | 3V3 RED | LED_SMD:LED_0603_1608Metric |  | Lite-On | LTST-C190KRKT | SMT
LED4 | HEAT RED | LED_SMD:LED_0603_1608Metric |  | Lite-On | LTST-C190KRKT | SMT
LED5 | RUN RED | LED_SMD:LED_0603_1608Metric |  | Lite-On | LTST-C190KRKT | SMT
LED6 | STATUS1 RED OPTIONAL | LED_SMD:LED_0603_1608Metric |  | Lite-On | LTST-C190KRKT | DNP
LED7 | STATUS2 RED OPTIONAL | LED_SMD:LED_0603_1608Metric |  | Lite-On | LTST-C190KRKT | DNP
NT1 | USB POWER OR NET-TIE | NetTie:NetTie-2_SMD_Pad0.5mm |  |  |  | SMT | Logical boundary after true reverse-blocking eFuse
Q1 | IPG20N06S4L-26 | LandyHeater:PROVISIONAL_Infineon_PG-TDSON-8-4_Dual | https://www.infineon.com/assets/row/public/documents/10/49/infineon-ipg20n06s4l-26-datasheet-en.pdf | Infineon | IPG20N06S4L-26 | SMT | Provisional 8-pad footprint; replace with official split-exposed-pad PG-TDSON-8-4 land pattern before layout freeze
Q2,Q5,Q6 | 2N7002KQ-13 | Package_TO_SOT_SMD:SOT-23 |  | Diodes Inc. | 2N7002KQ-13 | SMT
Q3 | SI1308EDL-T1-GE3 | Package_TO_SOT_SMD:SOT-323_SC-70 |  | Vishay | SI1308EDL-T1-GE3 | SMT
Q7 | BC857BQ-13-F | Package_TO_SOT_SMD:SOT-23 |  | Diodes Inc. | BC857BQ-13-F | SMT
Q8 | 2N7002KQ-13 USB CURRENT ISOLATOR | Package_TO_SOT_SMD:SOT-23 | https://www.diodes.com/assets/Datasheets/2N7002KQ.pdf | Diodes Inc. | 2N7002KQ-13 | SMT | Prevents 3V3 backfeed into unpowered TUSB321; output is active HIGH for >=1.5 A
R1,R7 | 100k 1% | Resistor_SMD:R_0603_1608Metric_Pad0.98x0.95mm_HandSolder |  |  |  | SMT
R2 | 7.15k 1% | Resistor_SMD:R_0603_1608Metric_Pad0.98x0.95mm_HandSolder |  |  |  | SMT | OV cut-off nominal 18.45V
R3,R37,R44,R65,R68 | 0R | Resistor_SMD:R_0603_1608Metric_Pad0.98x0.95mm_HandSolder |  |  |  | SMT | Required populated 0-ohm tuning link,TI Figure 9-1 R5,USB shield bond; placement directly at J5
R4 | 900k 1% | Resistor_SMD:R_0603_1608Metric_Pad0.98x0.95mm_HandSolder |  |  |  | SMT
R5,R6 | 220k | Resistor_SMD:R_0603_1608Metric_Pad0.98x0.95mm_HandSolder |  |  |  | SMT | TUSB321 OUT1 pull-up; referenced only to TUSB321 VDD,TUSB321 OUT2 pull-up; test point is 5-V domain
R8 | 26.1k 1% | Resistor_SMD:R_0603_1608Metric_Pad0.98x0.95mm_HandSolder |  |  |  | SMT | OVLO approx 5.95V
R9 | 3.32k 1% | Resistor_SMD:R_0603_1608Metric_Pad0.98x0.95mm_HandSolder |  |  |  | SMT | ILIM nominal 1.0A
R10,R17-R19,R26,R32,R35,R41,R42,R45,R51,R60-R64,R66,R73 | 100k | Resistor_SMD:R_0603_1608Metric_Pad0.98x0.95mm_HandSolder |  |  |  | SMT | Direct hardware default OFF at BCR421 EN,MCU-side pull-up; active HIGH for >=1.5 A or 12-V-only operation
R11-R13,R27,R29,R39 | 10k | Resistor_SMD:R_0603_1608Metric_Pad0.98x0.95mm_HandSolder |  |  |  | SMT
R14,R15 | 22R | Resistor_SMD:R_0603_1608Metric_Pad0.98x0.95mm_HandSolder |  |  |  | SMT
R16 | 499R | Resistor_SMD:R_0603_1608Metric_Pad0.98x0.95mm_HandSolder |  |  |  | SMT
R20 | 1M 1% | Resistor_SMD:R_0603_1608Metric_Pad0.98x0.95mm_HandSolder |  |  |  | SMT | Good Display chapter 12
R21 | 2.2R 1% | Resistor_SMD:R_0603_1608Metric_Pad0.98x0.95mm_HandSolder |  |  |  | SMT | Good Display chapter 12
R24,R25,R36 | 4.7k | Resistor_SMD:R_0603_1608Metric_Pad0.98x0.95mm_HandSolder |  |  |  | SMT
R28,R33,R34,R40,R74 | 100R | Resistor_SMD:R_0603_1608Metric_Pad0.98x0.95mm_HandSolder |  |  |  | SMT | TI Figure 9-1 R4
R30,R70 | 0R DNP | Resistor_SMD:R_0603_1608Metric_Pad0.98x0.95mm_HandSolder |  |  |  | DNP | Optional direct bypass of R28,Populate only with U13 latch; remove R28, R29 and R30
R31 | 100k DNP | Resistor_SMD:R_0603_1608Metric_Pad0.98x0.95mm_HandSolder |  |  |  | DNP
R38 | 1k | Resistor_SMD:R_0603_1608Metric_Pad0.98x0.95mm_HandSolder |  |  |  | SMT
R43 | 2.0R 1% 0.25W | Resistor_SMD:R_1206_3216Metric_Pad1.30x1.75mm_HandSolder |  |  |  | SMT
R46 | 12k | Resistor_SMD:R_0603_1608Metric_Pad0.98x0.95mm_HandSolder |  |  |  | SMT
R47,R49 | 3.3k | Resistor_SMD:R_0603_1608Metric_Pad0.98x0.95mm_HandSolder |  |  |  | SMT
R48,R50 | 1.2k | Resistor_SMD:R_0603_1608Metric_Pad0.98x0.95mm_HandSolder |  |  |  | SMT
R52,R53 | 2.7k DNP | Resistor_SMD:R_0603_1608Metric_Pad0.98x0.95mm_HandSolder |  |  |  | DNP
R54-R59 | 33R | Resistor_SMD:R_0603_1608Metric_Pad0.98x0.95mm_HandSolder |  |  |  | SMT
R67,R75 | 47k | Resistor_SMD:R_0603_1608Metric_Pad0.98x0.95mm_HandSolder |  |  |  | SMT | With R45 limits Q5 VGS to <14V at maximum OV threshold
R69 | 100R DNP | Resistor_SMD:R_0603_1608Metric_Pad0.98x0.95mm_HandSolder |  |  |  | DNP | Populate only with U13 latch; GPIO18 pulses low after touch INT releases
R71 | 10k DNP | Resistor_SMD:R_0603_1608Metric_Pad0.98x0.95mm_HandSolder |  |  |  | DNP | Measurement-only pull-down option; never populate with R29
R72 | 1M | Resistor_SMD:R_0603_1608Metric_Pad0.98x0.95mm_HandSolder |  |  |  | SMT | Defines MOSFET gate when USB is absent
SW1 | RESET KMR221GLFS | Button_Switch_SMD:SW_Push_1P1T_NO_CK_KMR2 |  | C&K | KMR221GLFS | SMT
SW2 | BOOT KMR221GLFS | Button_Switch_SMD:SW_Push_1P1T_NO_CK_KMR2 |  | C&K | KMR221GLFS | SMT
SW3 | DIAG KMR221GLFS | Button_Switch_SMD:SW_Push_1P1T_NO_CK_KMR2 |  | C&K | KMR221GLFS | SMT
TP1 | TP_BATT_12V | TestPoint:TestPoint_Pad_D1.5mm |  |  |  | DNP
TP2 | TP_USB_VBUS | TestPoint:TestPoint_Pad_D1.5mm |  |  |  | DNP
TP3 | TP_VIN_SYS | TestPoint:TestPoint_Pad_D1.5mm |  |  |  | DNP
TP4 | TP_3V3 | TestPoint:TestPoint_Pad_D1.5mm |  |  |  | DNP
TP5 | TP_GND | TestPoint:TestPoint_Pad_D1.5mm |  |  |  | DNP
TP6 | U0TXD | TestPoint:TestPoint_Pad_D1.0mm |  |  |  | DNP
TP7 | U0RXD | TestPoint:TestPoint_Pad_D1.0mm |  |  |  | DNP
TP8 | USB_EFUSE_FAULT | TestPoint:TestPoint_Pad_D1.0mm |  |  |  | DNP
TP9 | USB_CURRENT_3A | TestPoint:TestPoint_Pad_D1.0mm |  |  |  | DNP
TP10 | RTC_INT | TestPoint:TestPoint_Pad_D1.0mm |  |  |  | DNP
TP11 | AUTOTERM_5V_PROTECTED | TestPoint:TestPoint_Pad_D1.0mm |  |  |  | DNP
TP12 | 1WIRE_DQ | TestPoint:TestPoint_Pad_D1.0mm |  |  |  | DNP
TP13 | EPD_3V3 | TestPoint:TestPoint_Pad_D1.0mm |  |  |  | DNP
TP14 | EPD_SCLK | TestPoint:TestPoint_Pad_D1.0mm |  |  |  | DNP
TP15 | EPD_SDIO | TestPoint:TestPoint_Pad_D1.0mm |  |  |  | DNP
TP16 | EPD_CS | TestPoint:TestPoint_Pad_D1.0mm |  |  |  | DNP
TP17 | EPD_DC | TestPoint:TestPoint_Pad_D1.0mm |  |  |  | DNP
TP18 | EPD_RESET | TestPoint:TestPoint_Pad_D1.0mm |  |  |  | DNP
TP19 | EPD_BUSY | TestPoint:TestPoint_Pad_D1.0mm |  |  |  | DNP
TP20 | FRONTLIGHT_CURRENT | TestPoint:TestPoint_Pad_D1.0mm |  |  |  | DNP
TP21 | DIAG | TestPoint:TestPoint_Pad_D1.0mm |  |  |  | DNP
TP22 | DIAG_GND | TestPoint:TestPoint_Pad_D1.0mm |  |  |  | DNP
TP23 | CHIP_PU | TestPoint:TestPoint_Pad_D1.0mm |  |  |  | DNP
TP24 | BOOT_N | TestPoint:TestPoint_Pad_D1.0mm |  |  |  | DNP
TP25 | AUTOTERM_TX_3V3 | TestPoint:TestPoint_Pad_D1.0mm |  |  |  | DNP
TP26 | AUTOTERM_RX_3V3 | TestPoint:TestPoint_Pad_D1.0mm |  |  |  | DNP
TP27 | CTRL_TX_TO_HEATER | TestPoint:TestPoint_Pad_D1.0mm |  |  |  | DNP
TP28 | CTRL_RX_FROM_HEATER | TestPoint:TestPoint_Pad_D1.0mm |  |  |  | DNP
TP29 | 3V3_SENSOR_SW | TestPoint:TestPoint_Pad_D1.0mm |  |  |  | DNP
TP30 | I2C_SDA | TestPoint:TestPoint_Pad_D1.0mm |  |  |  | DNP
TP31 | I2C_SCL | TestPoint:TestPoint_Pad_D1.0mm |  |  |  | DNP
TP32 | TOUCH_INT_N | TestPoint:TestPoint_Pad_D1.0mm |  |  |  | DNP
TP33 | TOUCH_RESET_N | TestPoint:TestPoint_Pad_D1.0mm |  |  |  | DNP
TP34 | DISPLAY_EN | TestPoint:TestPoint_Pad_D1.0mm |  |  |  | DNP
TP35 | FRONTLIGHT_PWM | TestPoint:TestPoint_Pad_D1.0mm |  |  |  | DNP
TP36 | BUTTON_N | TestPoint:TestPoint_Pad_D1.0mm |  |  |  | DNP
TP37 | BUTTON_LED_PWM | TestPoint:TestPoint_Pad_D1.0mm |  |  |  | DNP
TP38 | DIAG_RUN | TestPoint:TestPoint_Pad_D1.0mm |  |  |  | DNP
U1 | LM74720QDRRRQ1 | Package_SON:WSON-12-1EP_3x3mm_P0.5mm_EP1.5x2.5mm | https://www.ti.com/lit/ds/symlink/lm74720-q1.pdf | Texas Instruments | LM74720QDRRRQ1 | SMT | RTN/EP MUST FLOAT
U2 | TUSB321AIRWBR | Package_DFN_QFN:Texas_X2QFN-12_1.6x1.6mm_P0.4mm | https://www.ti.com/lit/ds/symlink/tusb321ai.pdf | Texas Instruments | TUSB321AIRWBR | SMT
U3 | TPS259470LRPWR | Package_DFN_QFN:LQFN-10-1EP_2x2mm_P0.5mm_EP0.7x0.7mm | https://www.ti.com/lit/ds/symlink/tps25947.pdf | Texas Instruments | TPS259470LRPWR | SMT | PROVISIONAL generic RPW footprint; verify/replace from official TI ECAD before Phase 3
U4 | LMR43620MSC3RPERQ1 | LandyHeater:Texas_RPE0009A_VQFN-HR-9_2x2mm | https://www.ti.com/lit/ds/symlink/lmr43620-q1.pdf | Texas Instruments | LMR43620MSC3RPERQ1 | SMT | PROVISIONAL project-local RPE footprint; verify/replace from official TI ECAD before Phase 3
U5 | ESP32-S3-WROOM-1U-N16R8 | RF_Module:ESP32-S3-WROOM-1U | https://www.espressif.com/sites/default/files/documentation/esp32-s3-wroom-1_wroom-1u_datasheet_en.pdf | Espressif | ESP32-S3-WROOM-1U-N16R8 | SMT
U6 | TPS3808G33QDBVRQ1 | Package_TO_SOT_SMD:SOT-23-6 | https://www.ti.com/lit/ds/symlink/tps3808.pdf | Texas Instruments | TPS3808G33QDBVRQ1 | SMT | CT intentionally open for fixed nominal 20-ms reset delay
U7 | TPD2EUSB30DRTR | Package_TO_SOT_SMD:SOT-23-5 | https://www.ti.com/lit/ds/symlink/tpd2eusb30.pdf | Texas Instruments | TPD2EUSB30DRTR | SMT
U8 | TPS22919QDCKRQ1 | Package_TO_SOT_SMD:SOT-363_SC-70-6 | https://www.ti.com/lit/ds/symlink/tps22919.pdf | Texas Instruments | TPS22919QDCKRQ1 | SMT
U9 | SN74AXC8T245PWR | Package_SO:TSSOP-24_4.4x7.8mm_P0.65mm | https://www.ti.com/lit/ds/symlink/sn74axc8t245.pdf | Texas Instruments | SN74AXC8T245PWR | SMT
U10 | SN74AXC1T45DCKR | Package_TO_SOT_SMD:SOT-363_SC-70-6 | https://www.ti.com/lit/ds/symlink/sn74axc1t45.pdf | Texas Instruments | SN74AXC1T45DCKR | SMT
U11 | TPS7A0230PDBVR | Package_TO_SOT_SMD:SOT-23-5 | https://www.ti.com/lit/ds/symlink/tps7a02.pdf | Texas Instruments | TPS7A0230PDBVR | SMT
U12 | SN74LVC1G07QDBVRQ1 | Package_TO_SOT_SMD:SOT-23-5 | https://www.ti.com/lit/ds/symlink/sn74lvc1g07-q1.pdf | Texas Instruments | SN74LVC1G07QDBVRQ1 | SMT
U13 | SN74LVC1G74-Q1 WAKE LATCH OPTION | Package_SO:VSSOP-8_2.3x2mm_P0.5mm | https://www.ti.com/lit/ds/symlink/sn74lvc1g74-q1.pdf | Texas Instruments | SN74LVC1G74QDCURQ1 | DNP | DNP option: active-low touch INT asynchronously drives Q_N low; firmware clears after INT release
U14 | RV-3028-C7 | LandyHeater:RV-3028-C7 | https://www.microcrystal.com/fileadmin/Media/Products/RTC/App.Manual/RV-3028-C7_App-Manual.pdf | Micro Crystal | RV-3028-C7-32.768kHz-1ppm-TA-QC | SMT | PROVISIONAL project-local footprint; verify against current Micro Crystal ECAD before Phase 3
U15,U17 | TPS22945DCKR | Package_TO_SOT_SMD:SOT-353_SC-70-5 | https://www.ti.com/lit/ds/symlink/tps22945.pdf | Texas Instruments | TPS22945DCKR | SMT | 100-mA current-limited protection; heater-side supply only,OC_N intentionally unused
U16 | TXU0202QDCURQ1 | Package_SO:VSSOP-8_2.3x2mm_P0.5mm | https://www.ti.com/lit/ds/symlink/txu0202-q1.pdf | Texas Instruments | TXU0202QDCURQ1 | SMT
U18 | BCR421UW6Q-7 | Package_TO_SOT_SMD:SOT-23-6 | https://www.diodes.com/datasheet/download/BCR420UW6Q.pdf | Diodes Inc. | BCR421UW6Q-7 | SMT | Preset 10mA; native low-side PWM EN <25kHz
U19 | AL8861QMP-13 | Package_SO:MSOP-8-1EP_3x3mm_P0.65mm_EP1.5x1.8mm | https://www.diodes.com/datasheet/download/AL8861Q.pdf | Diodes Inc. | AL8861QMP-13 | SMT

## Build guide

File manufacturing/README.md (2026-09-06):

# Fertigungsdaten

Dieses Verzeichnis ist für freigegebene, eindeutig versionierte PCB- und PCBA-Pakete vorgesehen. Arbeitsausgaben werden reproduzierbar unter `build/` erzeugt und nicht eingecheckt.

Fertigungsdaten werden erst in Phase 5 nach abgeschlossenem Schaltplan-, Layout- und Manufacturing-Review freigegeben.

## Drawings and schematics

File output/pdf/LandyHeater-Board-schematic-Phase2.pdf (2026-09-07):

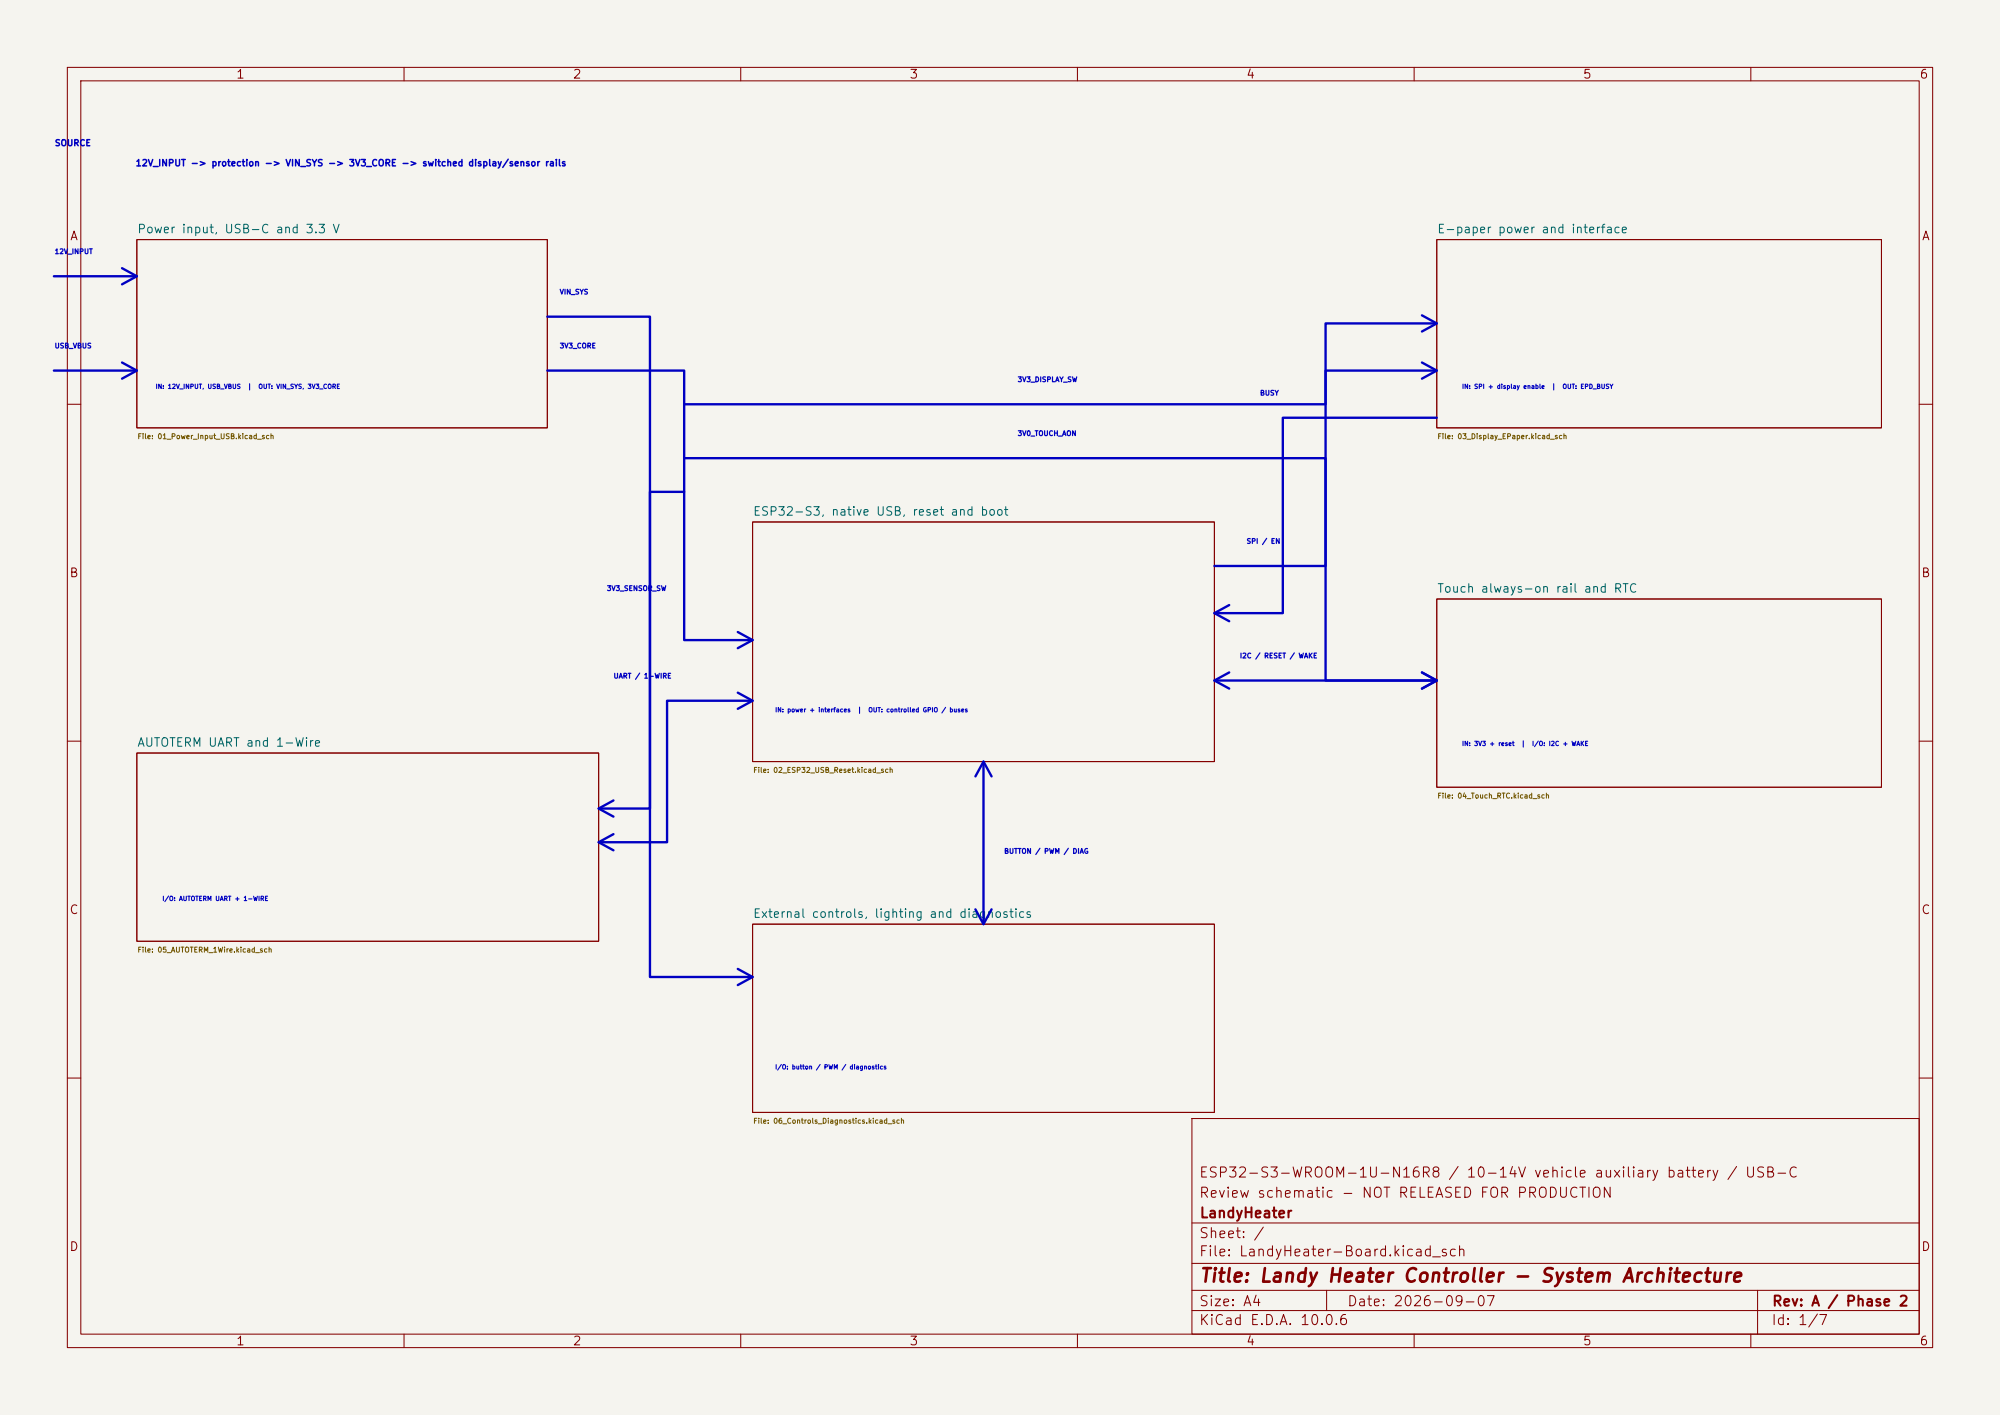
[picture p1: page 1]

3V3_DISPLAY_SW 12V_INPUT -> protection -> VIN_SYS -> 3V3_CORE -> switched display/sensor rails

Power input, USB-C and 3.3 V

E-paper power and interface

IN: SPI + display enable | OUT: EPD_BUSY 12V_INPUT

IN: power + interfaces | OUT: controlled GPIO / buses | BUSY 3V3_SENSOR_SW | File: 03_Display_EPaper.kicad_sch ESP32-S3, native USB, reset and boot

3V0_TOUCH_AON

Touch always-on rail and RTC

File: 02_ESP32_USB_Reset.kicad_sch AUTOTERM UART and 1-Wire

ESP32-S3-WROOM-1U-N16R8 / 10-14V vehicle auxiliary battery / USB-C
Review schematic - NOT RELEASED FOR PRODUCTION
LandyHeater
Sheet: /
File: LandyHeater-Board.kicad_sch
Title: Landy Heater Controller - System Architecture

Size: A4 | Rev: A / Phase 2
KiCad E.D.A. 10.0.6 | Id: 1/7

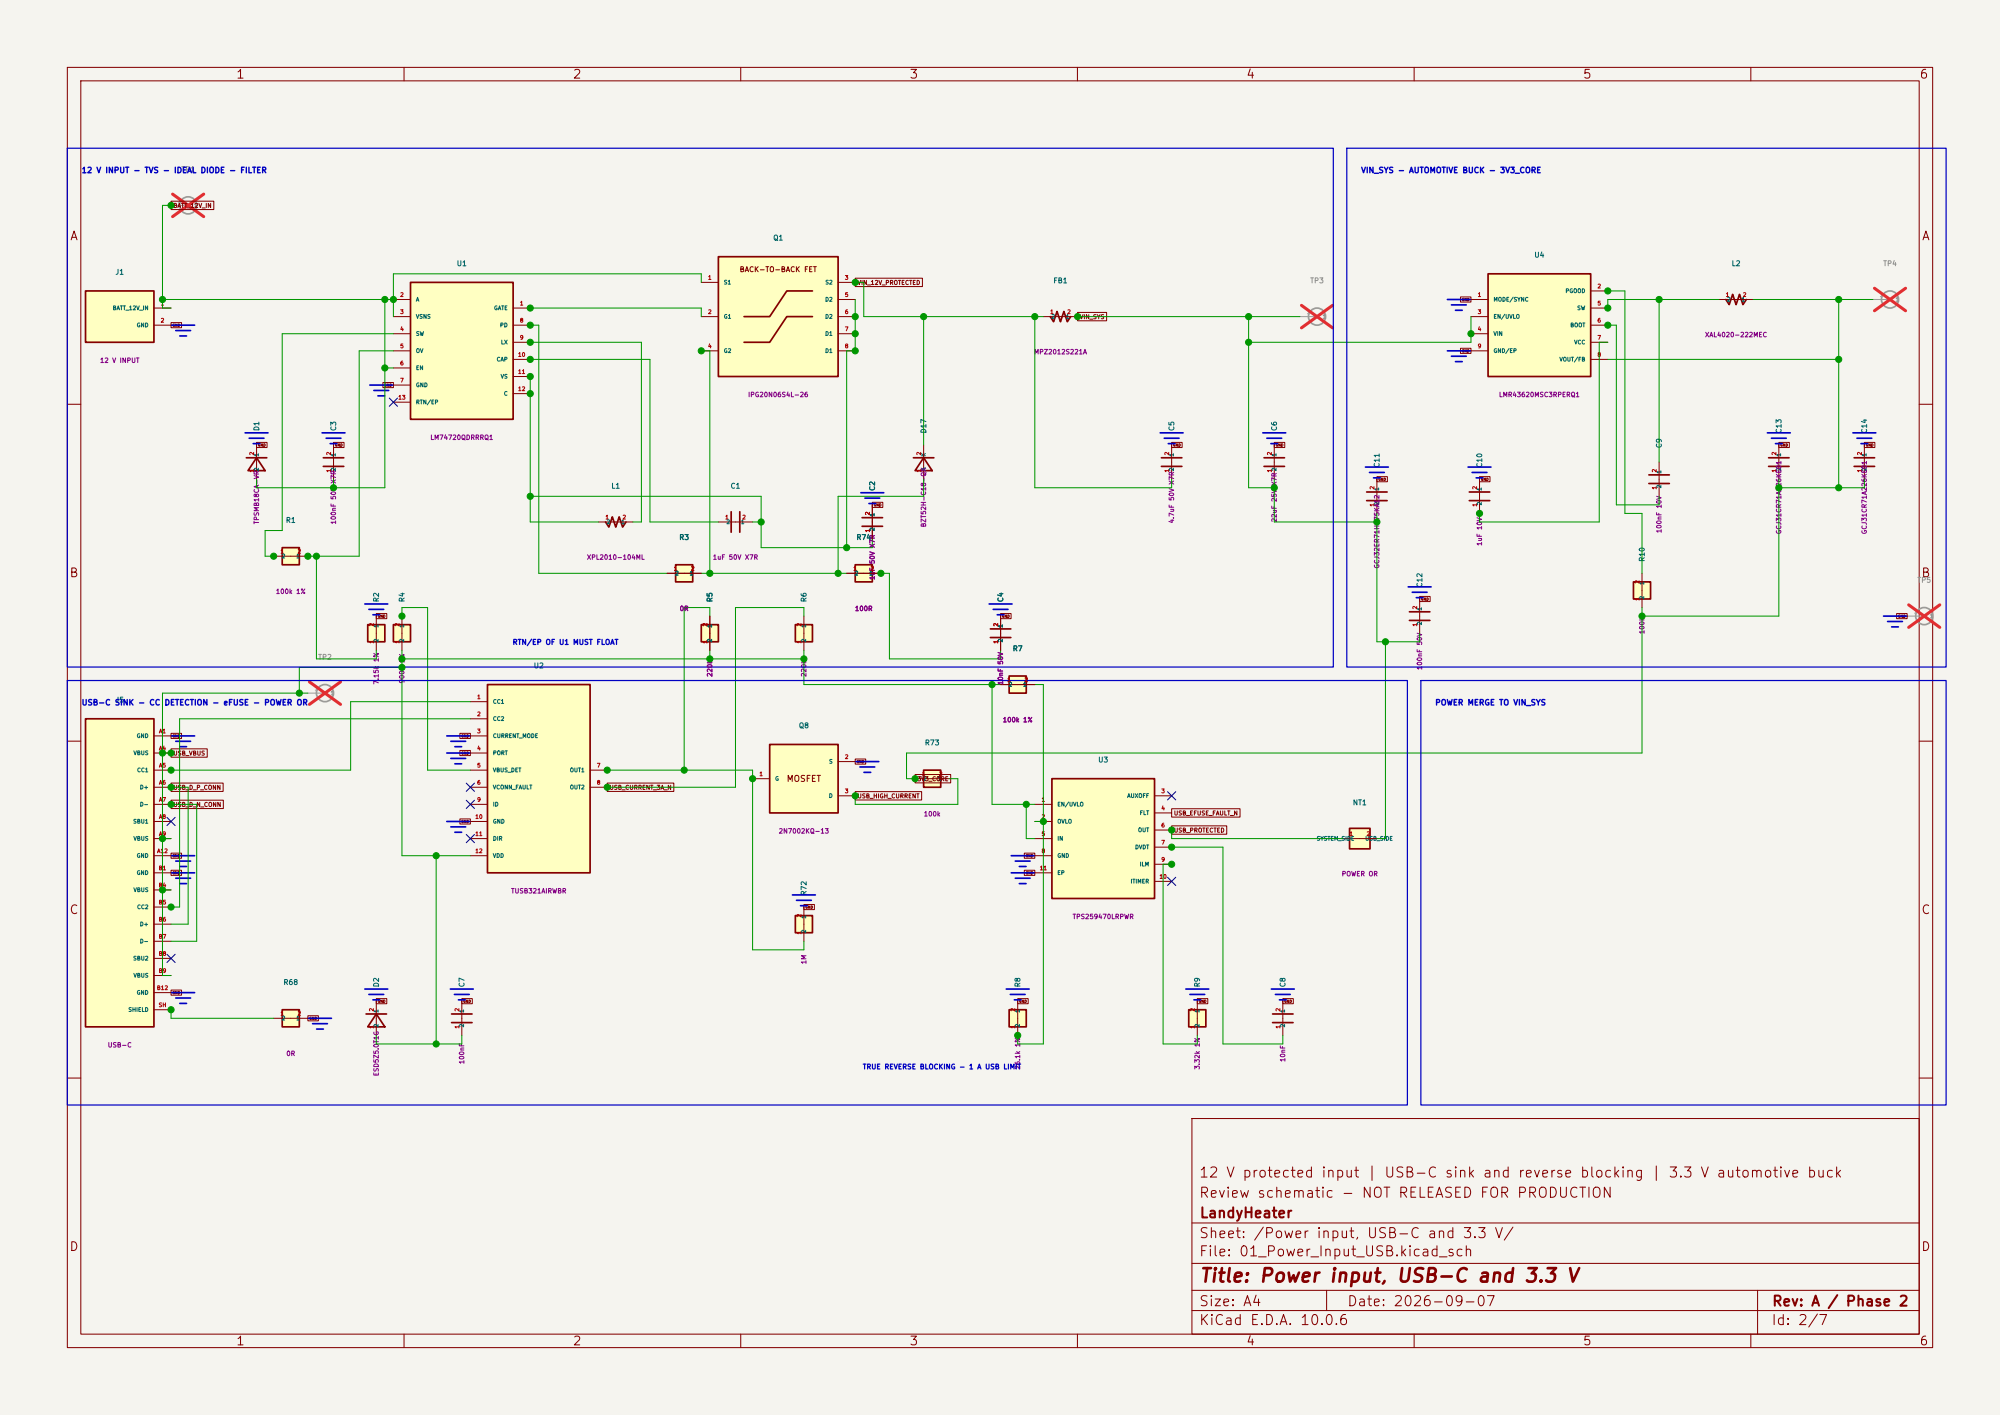
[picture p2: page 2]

12 V INPUT - TVS - IDEAL DIODE - FILTER

BACK-TO-BACK FET

RTN/EP OF U1 MUST FLOAT

12 V protected input | USB-C sink and reverse blocking | 3.3 V automotive buck
Review schematic - NOT RELEASED FOR PRODUCTION
LandyHeater
Sheet: /Power input, USB-C and 3.3 V/
File: 01_Power_Input_USB.kicad_sch
Title: Power input, USB-C and 3.3 V

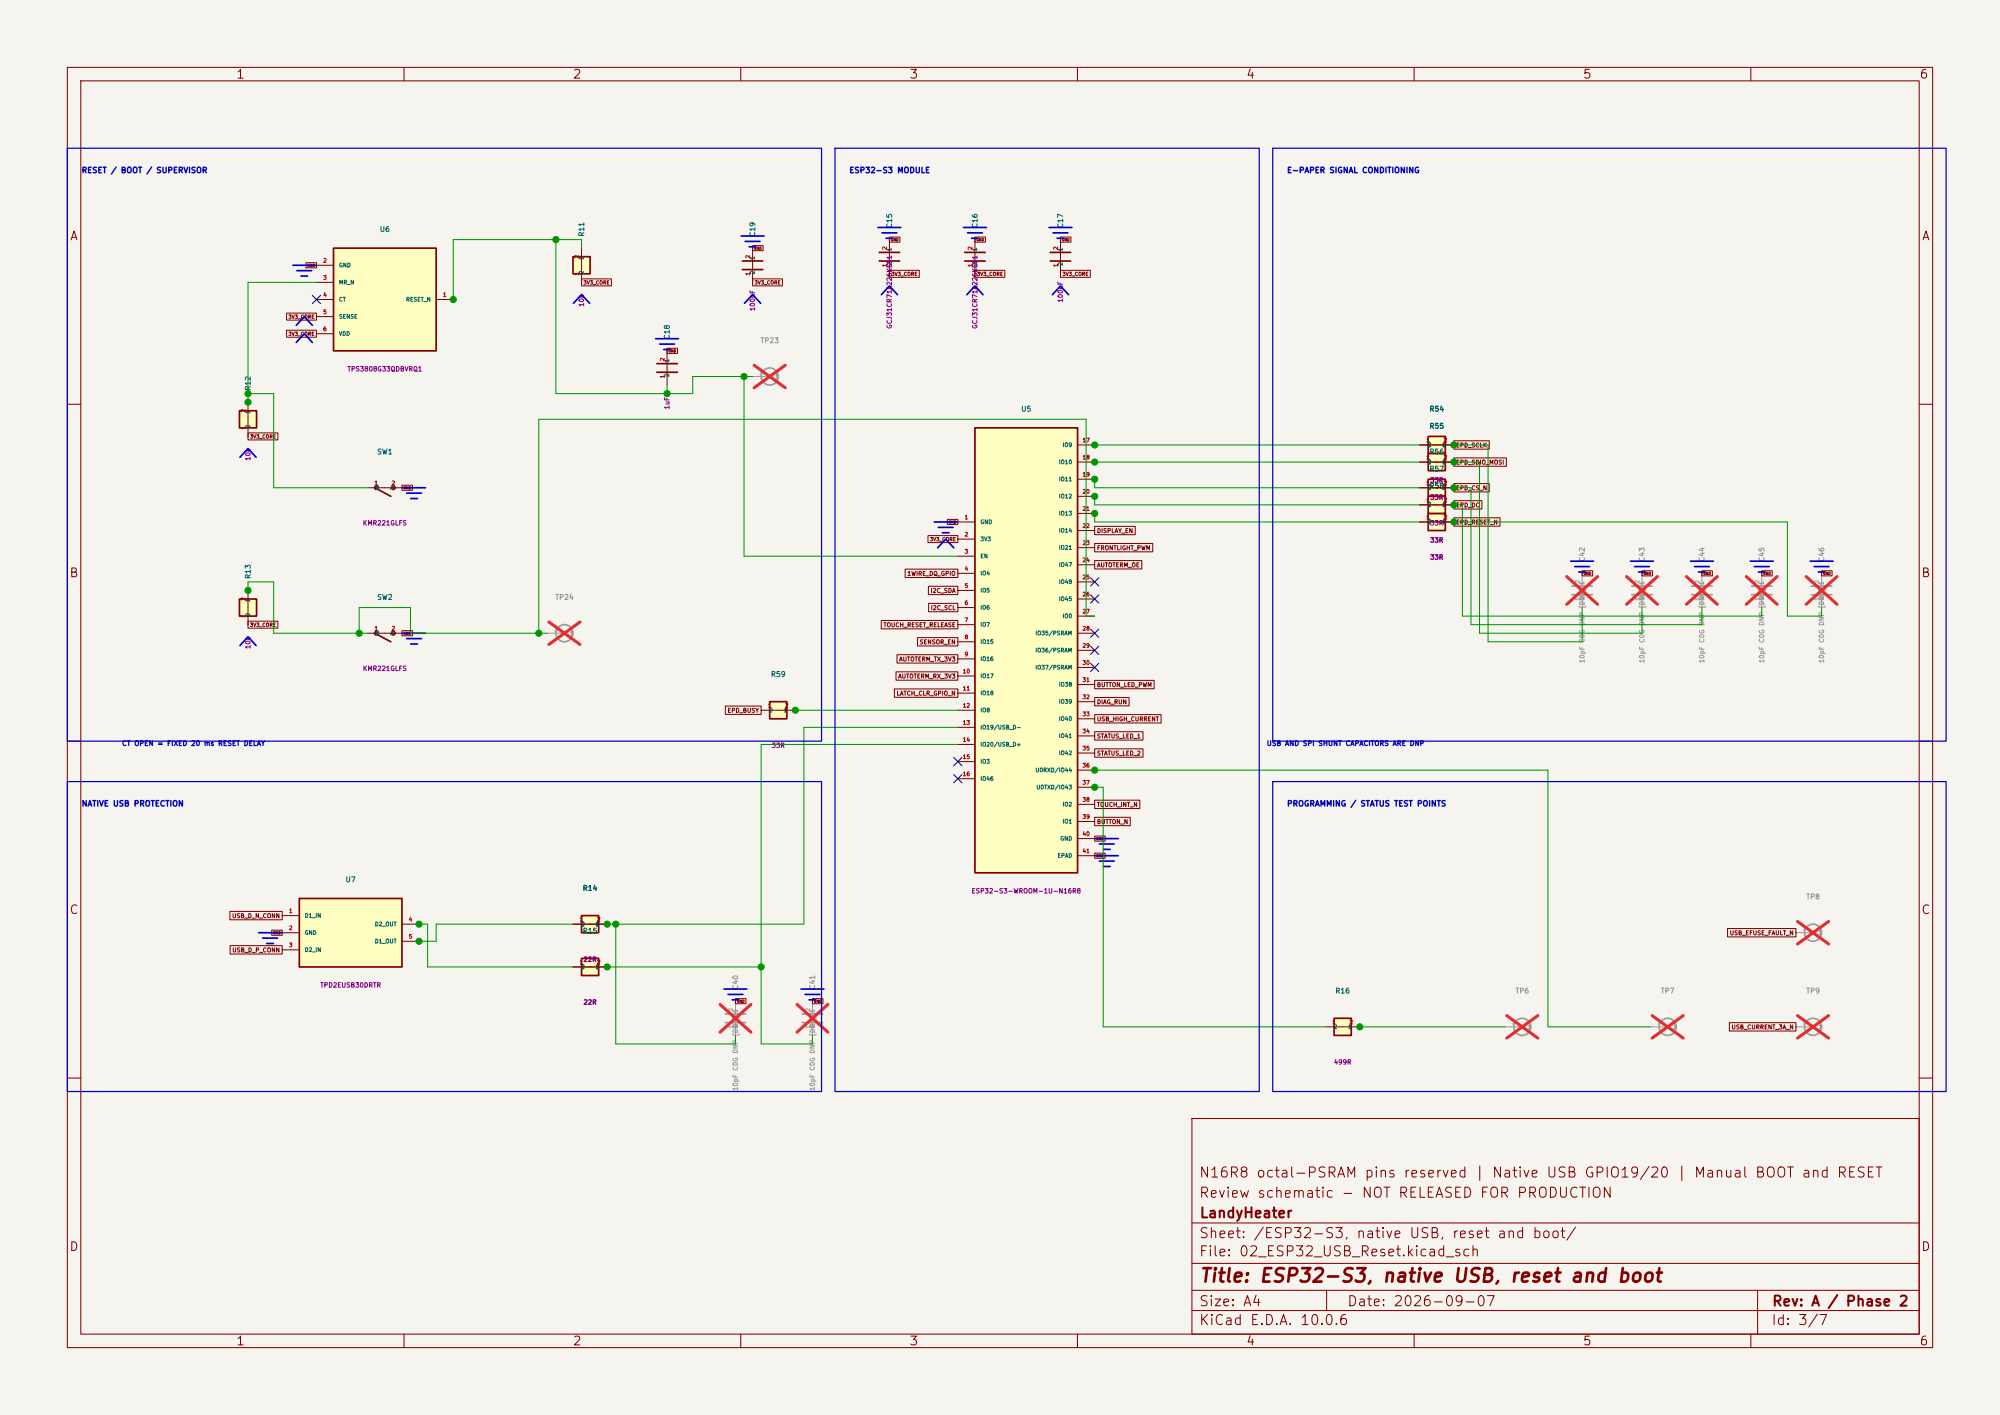
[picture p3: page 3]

IO19/USB_D- 13

IO20/USB_D+ 14

PROGRAMMING / STATUS TEST POINTS

N16R8 octal-PSRAM pins reserved | Native USB GPIO19/20 | Manual BOOT and RESET
Review schematic - NOT RELEASED FOR PRODUCTION
LandyHeater
Sheet: /ESP32-S3, native USB, reset and boot/
File: 02_ESP32_USB_Reset.kicad_sch
Title: ESP32-S3, native USB, reset and boot

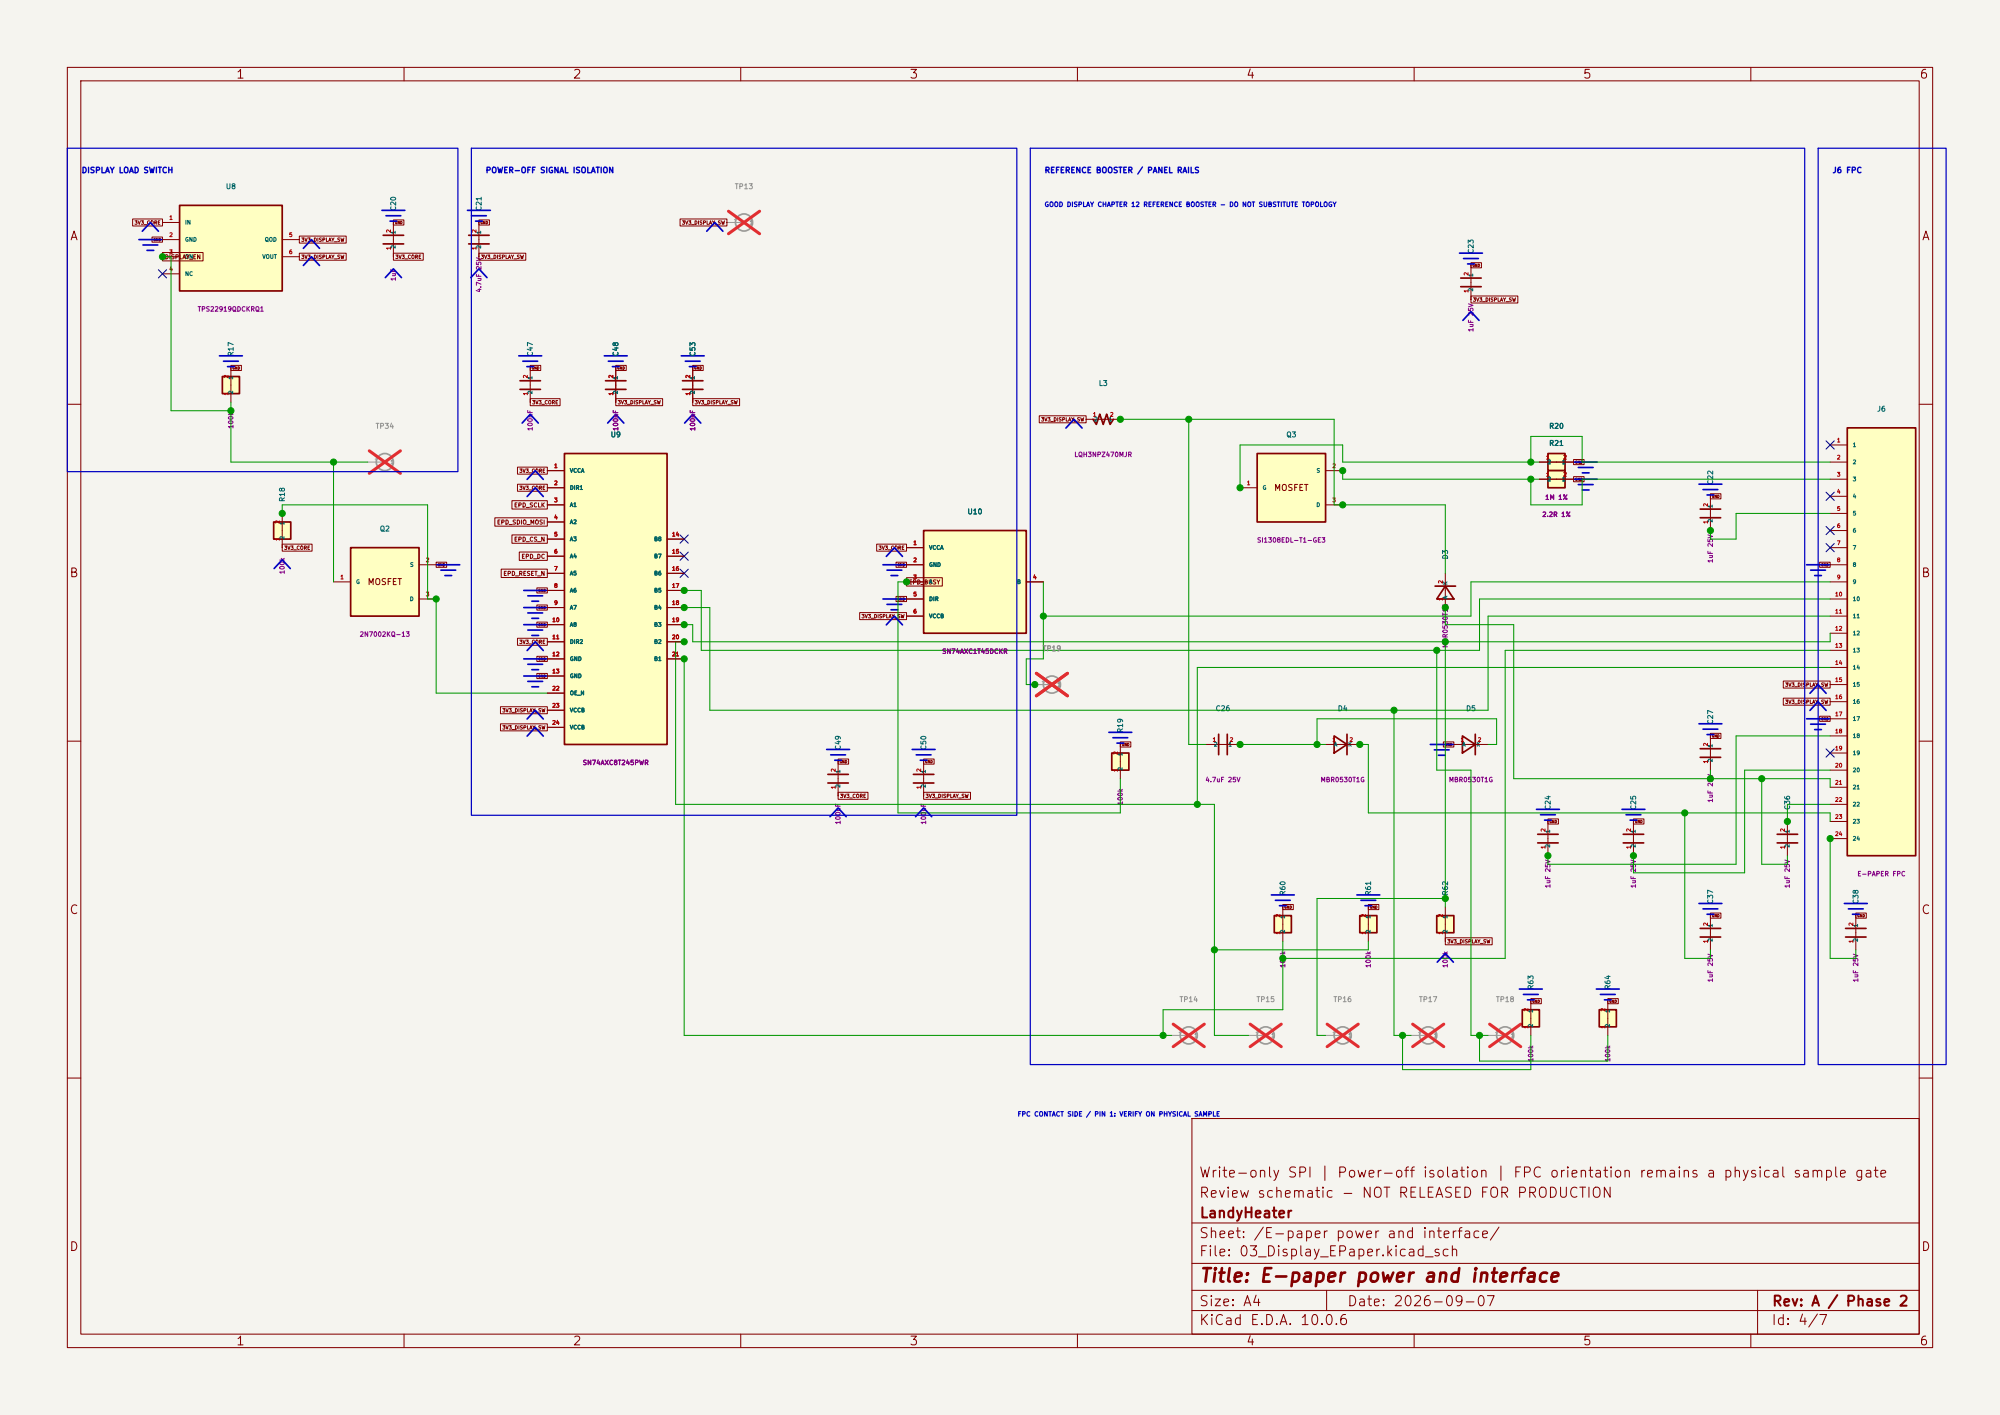
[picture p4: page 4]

GOOD DISPLAY CHAPTER 12 REFERENCE BOOSTER - DO NOT SUBSTITUTE TOPOLOGY U9

2 2 | 1 1 GND | 3

SN74AXC1T45DCKR

GND 3V3_DISPLAY_SW | 17 17

FPC CONTACT SIDE / PIN 1: VERIFY ON PHYSICAL SAMPLE

Write-only SPI | Power-off isolation | FPC orientation remains a physical sample gate
Review schematic - NOT RELEASED FOR PRODUCTION
LandyHeater
Sheet: /E-paper power and interface/
File: 03_Display_EPaper.kicad_sch
Title: E-paper power and interface

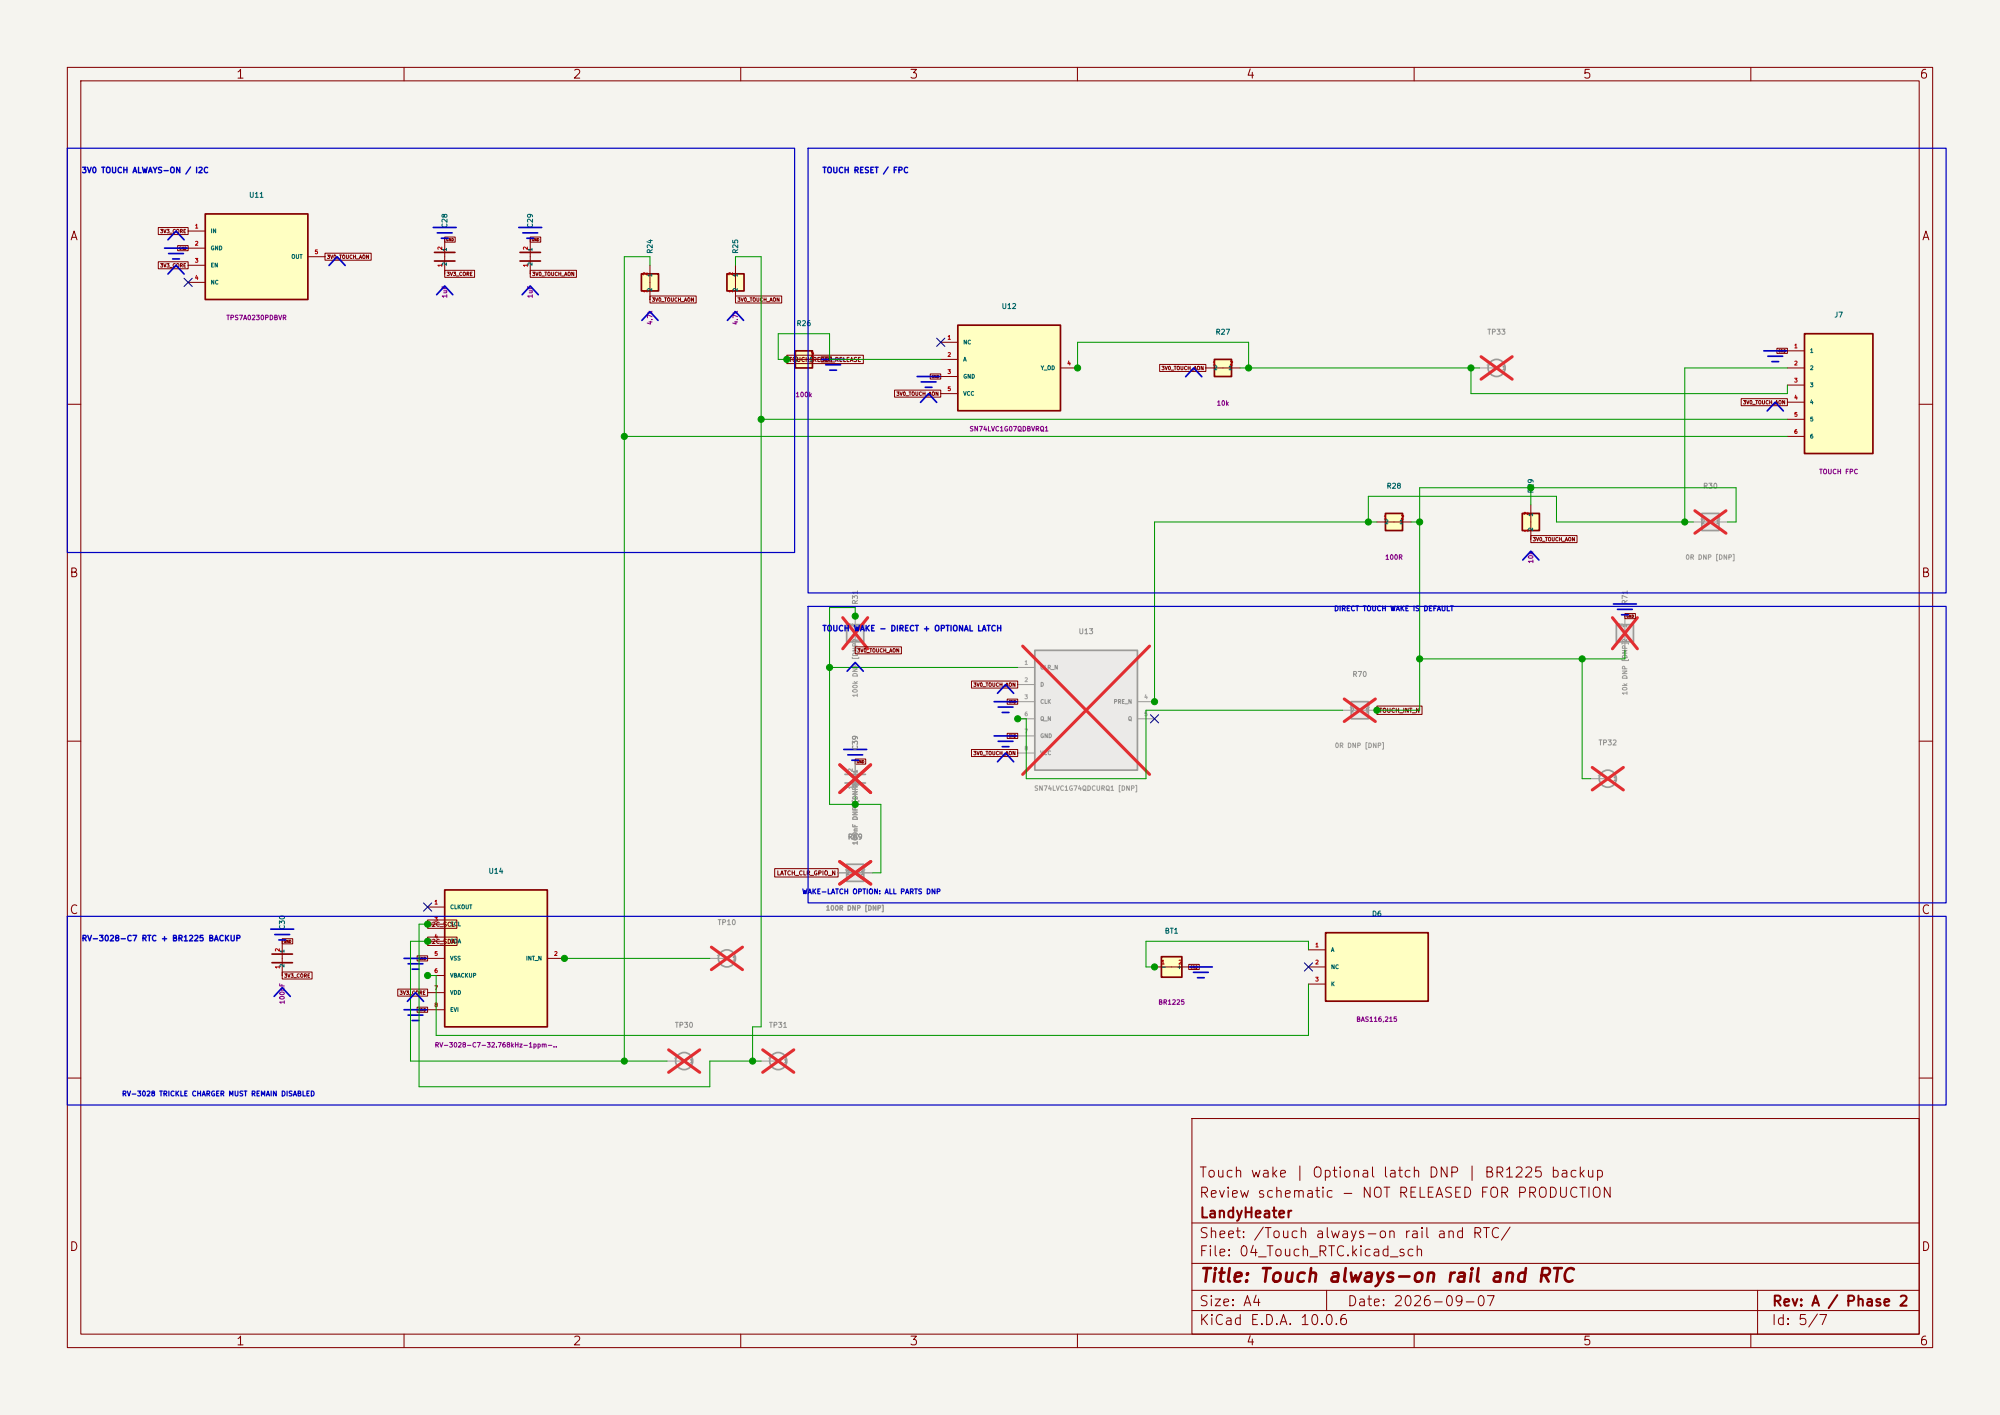
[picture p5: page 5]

SN74LVC1G07QDBVRQ1

Touch wake | Optional latch DNP | BR1225 backup
Review schematic - NOT RELEASED FOR PRODUCTION
LandyHeater
Sheet: /Touch always-on rail and RTC/
File: 04_Touch_RTC.kicad_sch
Title: Touch always-on rail and RTC

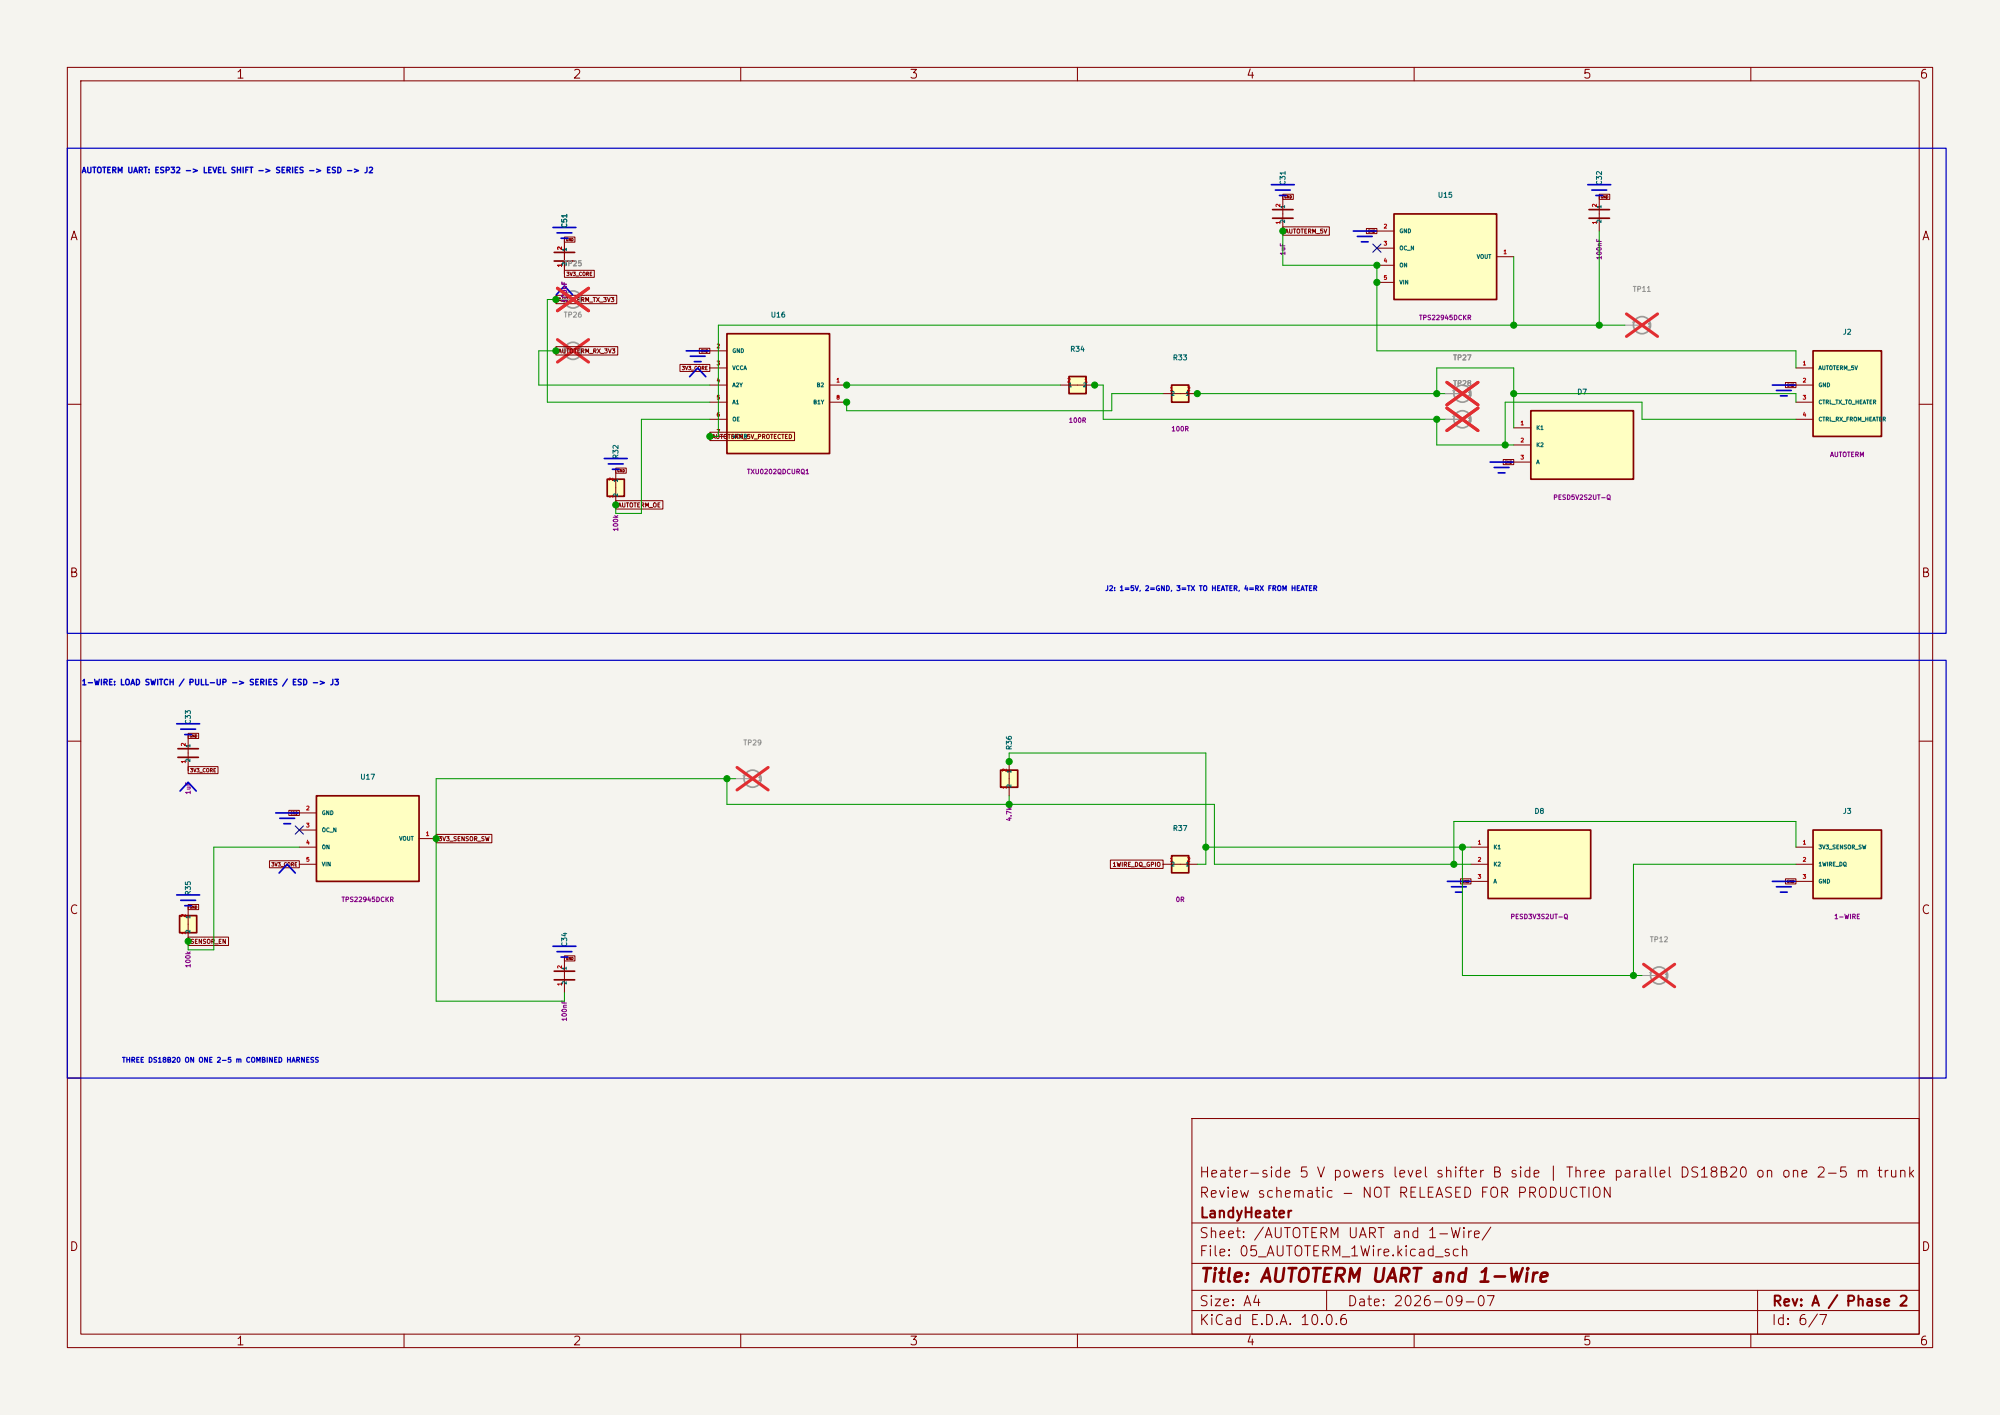
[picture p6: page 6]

J2: 1=5V, 2=GND, 3=TX TO HEATER, 4=RX FROM HEATER 1-WIRE: LOAD SWITCH / PULL-UP -> SERIES / ESD -> J3

A 3 D8 | 1WIRE_DQ 2 GND 3 J3 3V3_SENSOR_SW 1

GND THREE DS18B20 ON ONE 2-5 m COMBINED HARNESS

Heater-side 5 V powers level shifter B side | Three parallel DS18B20 on one 2-5 m trunk
Review schematic - NOT RELEASED FOR PRODUCTION
LandyHeater
Sheet: /AUTOTERM UART and 1-Wire/
File: 05_AUTOTERM_1Wire.kicad_sch
Title: AUTOTERM UART and 1-Wire

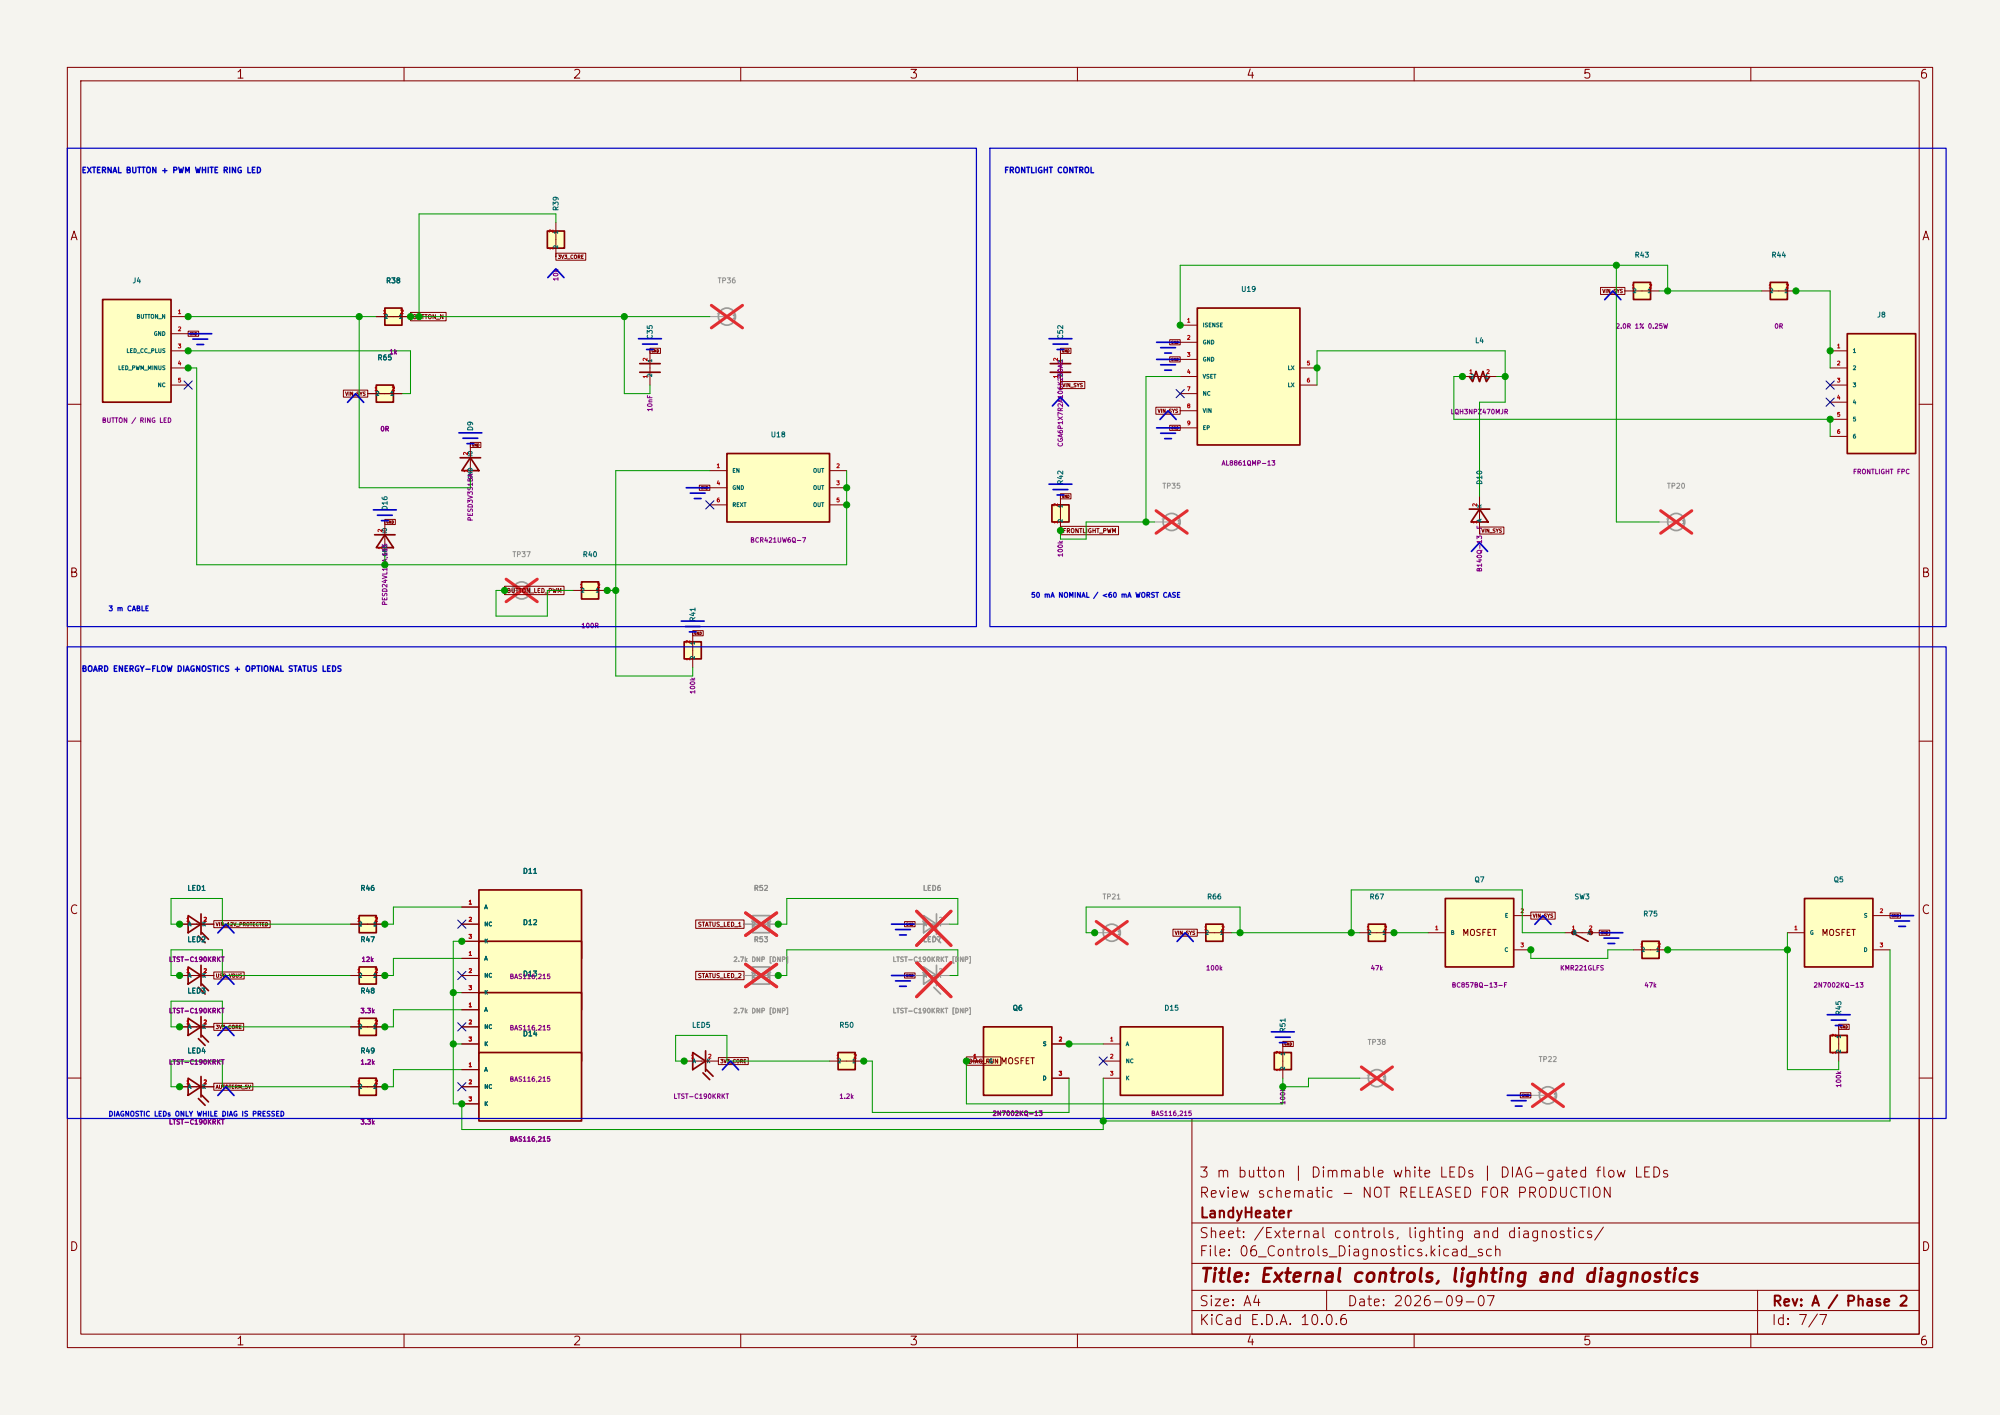
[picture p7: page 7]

EXTERNAL BUTTON + PWM WHITE RING LED

GND BOARD ENERGY-FLOW DIAGNOSTICS + OPTIONAL STATUS LEDS

50 mA NOMINAL / <60 mA WORST CASE R53

DIAGNOSTIC LEDs ONLY WHILE DIAG IS PRESSED

3 m button | Dimmable white LEDs | DIAG-gated flow LEDs
Review schematic - NOT RELEASED FOR PRODUCTION
LandyHeater
Sheet: /External controls, lighting and diagnostics/
File: 06_Controls_Diagnostics.kicad_sch
Title: External controls, lighting and diagnostics

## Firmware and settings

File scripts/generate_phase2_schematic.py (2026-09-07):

#!/usr/bin/env python3
"""Generate the Revision-A KiCad hierarchy from the reviewed hardware definition.

The generator deliberately uses only Python's standard library.  It keeps the
large, repetitive symbol/pin metadata reviewable in one place and produces
ordinary, editable KiCad schematic files plus the project-local symbol library.
"""

from __future__ import annotations

from dataclasses import dataclass, field
from pathlib import Path
import heapq
import re
import uuid


ROOT = Path(__file__).resolve().parents[1]
HW = ROOT / "hardware"
SYMLIB = HW / "libraries" / "symbols" / "LandyHeater.kicad_sym"
NS = uuid.UUID("83b760b8-4caf-4aa1-8e08-cd4c5ec23917")


def uid(*parts: object) -> str:
    return str(uuid.uuid5(NS, "|".join(str(p) for p in parts)))


def q(value: str) -> str:
    return '"' + value.replace("\\", "\\\\").replace('"', '\\"') + '"'


def symbol_key(value: str, pins: list[tuple[str, str, str | None]]) -> str:
    raw = value + "_" + "_".join(number + name for number, name, _ in pins)
    return re.sub(r"[^A-Za-z0-9_]+", "_", raw).strip("_")[:90]


@dataclass
class Part:
    ref: str
    value: str
    footprint: str
    pins: list[tuple[str, str, str | None]]
    mpn: str = ""
    manufacturer: str = ""
    datasheet: str = ""
    assembly: str = "SMT"
    note: str = ""
    dnp: bool = False
    x: float = 0
    y: float = 0
    rotation: int = 0
    key: str = field(init=False)

    def __post_init__(self) -> None:
        self.key = symbol_key(self.value, self.pins)


def P(ref: str, value: str, footprint: str, nets: tuple[str | None, ...], **kwargs: str | bool) -> Part:
    pins = [(str(index + 1), str(index + 1), net) for index, net in enumerate(nets)]
    return Part(ref, value, footprint, pins, **kwargs)


R0603 = "Resistor_SMD:R_0603_1608Metric_Pad0.98x0.95mm_HandSolder"
C0603 = "Capacitor_SMD:C_0603_1608Metric_Pad1.08x0.95mm_HandSolder"
C0805 = "Capacitor_SMD:C_0805_2012Metric_Pad1.18x1.45mm_HandSolder"
SOD123 = "Diode_SMD:D_SOD-123"
SOT23 = "Package_TO_SOT_SMD:SOT-23"
SOT235 = "Package_TO_SOT_SMD:SOT-23-5"
SOT236 = "Package_TO_SOT_SMD:SOT-23-6"
SC706 = "Package_TO_SOT_SMD:SOT-363_SC-70-6"


def passive(ref: str, value: str, a: str | None, b: str | None, footprint: str, **kw: str | bool) -> Part:
    return P(ref, value, footprint, (a, b), **kw)


def connector(ref: str, value: str, footprint: str, nets: list[str | None], **kw: str | bool) -> Part:
    return P(ref, value, footprint, tuple(nets), **kw)


def pages() -> list[tuple[str, str, list[Part], list[str]]]:
    power: list[Part] = [
        Part("J1", "1053131302 / 12V INPUT", "Connector_Molex:Molex_Nano-Fit_105313-xx02_1x02_P2.50mm_Horizontal", [("1", "BATT_12V_IN", "BATT_12V_IN"), ("2", "GND", "GND")], mpn="1053131302", manufacturer="Molex", assembly="THT"),
        passive("D1", "TPSMB18CA-VR", "BATT_12V_IN", "GND", "Diode_SMD:D_SMB", mpn="TPSMB18CA-VR", manufacturer="STMicroelectronics", datasheet="https://www.st.com/resource/en/datasheet/tpsmb.pdf"),
        Part("U1", "LM74720QDRRRQ1", "Package_SON:WSON-12-1EP_3x3mm_P0.5mm_EP1.5x2.5mm", [
            ("1", "GATE", "Q1_GATE"), ("2", "A", "BATT_12V_IN"), ("3", "VSNS", "BATT_12V_IN"),
            ("4", "SW", "OV_TOP"), ("5", "OV", "OV_SENSE"), ("6", "EN", "BATT_12V_IN"),
            ("7", "GND", "GND"), ("8", "PD", "Q2_GATE"), ("9", "LX", "BOOST_LX"),
            ("10", "CAP", "BOOST_CAP"), ("11", "VS", "FET_COMMON"), ("12", "C", "FET_COMMON"),
            ("13", "RTN/EP", None)], mpn="LM74720QDRRRQ1", manufacturer="Texas Instruments", datasheet="https://www.ti.com/lit/ds/symlink/lm74720-q1.pdf", note="RTN/EP MUST FLOAT"),
        Part("Q1", "IPG20N06S4L-26", "LandyHeater:PROVISIONAL_Infineon_PG-TDSON-8-4_Dual", [
            ("1", "S1", "BATT_12V_IN"), ("2", "G1", "Q1_GATE"), ("3", "S2", "VIN_12V_PROTECTED"),
            ("4", "G2", "Q2_GATE_FET"), ("5", "D2", "FET_COMMON"), ("6", "D2", "FET_COMMON"),
            ("7", "D1", "FET_COMMON"), ("8", "D1", "FET_COMMON")], mpn="IPG20N06S4L-26", manufacturer="Infineon", datasheet="https://www.infineon.com/assets/row/public/documents/10/49/infineon-ipg20n06s4l-26-datasheet-en.pdf", note="Provisional 8-pad footprint; replace with official split-exposed-pad PG-TDSON-8-4 land pattern before layout freeze"),
        passive("L1", "100uH >175mA XPL2010-104ML", "FET_COMMON", "BOOST_LX", "Inductor_SMD:L_0805_2012Metric_Pad1.05x1.20mm_HandSolder", mpn="XPL2010-104ML", manufacturer="Coilcraft", datasheet="https://www.coilcraft.com/getmedia/56fc2271-3bce-4dc9-808a-1edf9a322f75/xpl2010.pdf", note="PROVISIONAL generic footprint; verify against Coilcraft land pattern before Phase 3"),
        passive("C1", "1uF 50V X7R", "BOOST_CAP", "FET_COMMON", C0805),
        passive("C2", "1uF 50V X7R", "FET_COMMON", "GND", C0805),
        passive("C3", "100nF 50V X7R", "BATT_12V_IN", "GND", C0603),
        passive("R1", "100k 1%", "OV_TOP", "OV_SENSE", R0603),
        passive("R2", "7.15k 1%", "OV_SENSE", "GND", R0603, note="OV cut-off nominal 18.45V"),
        passive("R3", "0R", "Q2_GATE", "Q2_GATE_FET", R0603, note="TI Figure 9-1 R5"),
        Part("D17", "BZT52H-C18-QX", "Diode_SMD:D_SOD-123F", [("1", "K", "Q2_GATE_FET"), ("2", "A", "VIN_12V_PROTECTED")], mpn="BZT52H-C18-QX", manufacturer="Nexperia", datasheet="https://assets.nexperia.com/documents/data-sheet/BZT52H-Q_SER.pdf", note="18-V Q2 VGS clamp per LM74720-Q1 Figure 9-1"),
        passive("R74", "100R", "Q2_GATE_FET", "Q2_DVDT_CAP", R0603, note="TI Figure 9-1 R4"),
        passive("C4", "10nF 50V", "Q2_DVDT_CAP", "GND", C0603, note="PD slew to GND per LM74720-Q1 Figure 9-1; validate inrush/SOA"),
        passive("FB1", "220R@100MHz 3A", "VIN_12V_PROTECTED", "VIN_SYS", "Inductor_SMD:L_0805_2012Metric_Pad1.05x1.20mm_HandSolder", mpn="MPZ2012S221A", manufacturer="TDK", datasheet="https://product.tdk.com/system/files/dam/doc/product/emc/emc/beads/catalog/beads_commercial_power_mpz2012_en.pdf"),
        passive("C5", "4.7uF 50V X7R", "VIN_12V_PROTECTED", "GND", C0805),
        passive("C6", "22uF 25V X7R", "VIN_SYS", "GND", "Capacitor_SMD:C_1210_3225Metric_Pad1.33x2.70mm_HandSolder"),
        Part("J5", "USB4105-GF-A-120", "Connector_USB:USB_C_Receptacle_GCT_USB4105-xx-A_16P_TopMnt_Horizontal", [
            ("A1", "GND", "GND"), ("A4", "VBUS", "USB_VBUS"), ("A5", "CC1", "CC1"), ("A6", "D+", "USB_D_P_CONN"),
            ("A7", "D-", "USB_D_N_CONN"), ("A8", "SBU1", None), ("A9", "VBUS", "USB_VBUS"), ("A12", "GND", "GND"),
            ("B1", "GND", "GND"), ("B4", "VBUS", "USB_VBUS"), ("B5", "CC2", "CC2"), ("B6", "D+", "USB_D_P_CONN"),
            ("B7", "D-", "USB_D_N_CONN"), ("B8", "SBU2", None), ("B9", "VBUS", "USB_VBUS"), ("B12", "GND", "GND"),
            ("SH", "SHIELD", "USB_SHIELD")], mpn="USB4105-GF-A-120", manufacturer="GCT"),
        passive("R68", "0R", "USB_SHIELD", "GND", R0603, note="USB shield bond; placement directly at J5"),
        passive("D2", "ESD5Z5.0T1G", "USB_VBUS", "GND", "Diode_SMD:D_SOD-523", mpn="ESD5Z5.0T1G", manufacturer="onsemi"),
        Part("U2", "TUSB321AIRWBR", "Package_DFN_QFN:Texas_X2QFN-12_1.6x1.6mm_P0.4mm", [
            ("1", "CC1", "CC1"), ("2", "CC2", "CC2"), ("3", "CURRENT_MODE", "GND"), ("4", "PORT", "GND"),
            ("5", "VBUS_DET", "USB_VBUS_DET"), ("6", "VCONN_FAULT", None), ("7", "OUT1", "USB_CURRENT_OUT1"),
            ("8", "OUT2", "USB_CURRENT_3A_N"), ("9", "ID", None), ("10", "GND", "GND"), ("11", "DIR", None), ("12", "VDD", "USB_VBUS")],
            mpn="TUSB321AIRWBR", manufacturer="Texas Instruments", datasheet="https://www.ti.com/lit/ds/symlink/tusb321ai.pdf"),
        passive("R4", "900k 1%", "USB_VBUS", "USB_VBUS_DET", R0603),
        passive("R5", "220k", "USB_VBUS", "USB_CURRENT_OUT1", R0603, note="TUSB321 OUT1 pull-up; referenced only to TUSB321 VDD"),
        passive("R6", "220k", "USB_VBUS", "USB_CURRENT_3A_N", R0603, note="TUSB321 OUT2 pull-up; test point is 5-V domain"),
        Part("Q8", "2N7002KQ-13 USB CURRENT ISOLATOR", SOT23, [("1", "G", "USB_CURRENT_OUT1"), ("2", "S", "GND"), ("3", "D", "USB_HIGH_CURRENT")], mpn="2N7002KQ-13", manufacturer="Diodes Inc.", datasheet="https://www.diodes.com/assets/Datasheets/2N7002KQ.pdf", note="Prevents 3V3 backfeed into unpowered TUSB321; output is active HIGH for >=1.5 A"),
        passive("R72", "1M", "USB_CURRENT_OUT1", "GND", R0603, note="Defines MOSFET gate when USB is absent"),
        passive("R73", "100k", "3V3_CORE", "USB_HIGH_CURRENT", R0603, note="MCU-side pull-up; active HIGH for >=1.5 A or 12-V-only operation"),
        passive("C7", "100nF", "USB_VBUS", "GND", C0603),
        Part("U3", "TPS259470LRPWR", "Package_DFN_QFN:LQFN-10-1EP_2x2mm_P0.5mm_EP0.7x0.7mm", [
            ("1", "EN/UVLO", "USB_VBUS"), ("2", "OVLO", "USB_OVLO"), ("3", "AUXOFF", None), ("4", "FLT", "USB_EFUSE_FAULT_N"),
            ("5", "IN", "USB_VBUS"), ("6", "OUT", "USB_PROTECTED"), ("7", "DVDT", "USB_DVDT"), ("8", "GND", "GND"),
            ("9", "ILM", "USB_ILM"), ("10", "ITIMER", None), ("11", "EP", "GND")], mpn="TPS259470LRPWR", manufacturer="Texas Instruments", datasheet="https://www.ti.com/lit/ds/symlink/tps25947.pdf", note="PROVISIONAL generic RPW footprint; verify/replace from official TI ECAD before Phase 3"),
        passive("R7", "100k 1%", "USB_VBUS", "USB_OVLO", R0603),
        passive("R8", "26.1k 1%", "USB_OVLO", "GND", R0603, note="OVLO approx 5.95V"),
        passive("R9", "3.32k 1%", "USB_ILM", "GND", R0603, note="ILIM nominal 1.0A"),
        passive("C8", "10nF", "USB_DVDT", "GND", C0603),
        Part("NT1", "USB POWER OR NET-TIE", "NetTie:NetTie-2_SMD_Pad0.5mm", [("1", "USB_SIDE", "USB_PROTECTED"), ("2", "SYSTEM_SIDE", "VIN_SYS")], assembly="SMT", note="Logical boundary after true reverse-blocking eFuse"),
        Part("U4", "LMR43620MSC3RPERQ1", "LandyHeater:Texas_RPE0009A_VQFN-HR-9_2x2mm", [
            ("1", "MODE/SYNC", "GND"), ("2", "PGOOD", "BUCK_PGOOD"), ("3", "EN/UVLO", "VIN_SYS"),
            ("4", "VIN", "VIN_SYS"), ("5", "SW", "BUCK_SW"), ("6", "BOOT", "BUCK_BOOT"),
            ("7", "VCC", "BUCK_VCC"), ("8", "VOUT/FB", "3V3_CORE"), ("9", "GND/EP", "GND")],
            mpn="LMR43620MSC3RPERQ1", manufacturer="Texas Instruments", datasheet="https://www.ti.com/lit/ds/symlink/lmr43620-q1.pdf", note="PROVISIONAL project-local RPE footprint; verify/replace from official TI ECAD before Phase 3"),
        passive("L2", "2.2uH 5.6A Isat", "BUCK_SW", "3V3_CORE", "Inductor_SMD:L_Coilcraft_XAL4020-XXX", mpn="XAL4020-222MEC", manufacturer="Coilcraft", datasheet="https://www.coilcraft.com/getmedia/6adcb47d-8b55-416c-976e-1e22e0d2848c/xal4000.pdf", note="TI Table 8-2 fixed 3.3V/2.2MHz; 20% tolerance"),
        passive("C9", "100nF 10V", "BUCK_BOOT", "BUCK_SW", C0603),
        passive("C10", "1uF 10V", "BUCK_VCC", "GND", C0603),
        passive("C11", "4.7uF 50V X7R 10%", "VIN_SYS", "GND", "Capacitor_SMD:C_1210_3225Metric_Pad1.33x2.70mm_HandSolder", mpn="GCJ32ER71H475KA12", manufacturer="Murata", datasheet="https://www.murata.com/en-us/products/productdetail?partno=GCJ32ER71H475KA12%23", note="LMR43620 local input capacitor; DC-bias effective capacitance must be verified"),
        passive("C12", "100nF 50V", "VIN_SYS", "GND", C0603),
        passive("C13", "22uF 10V X7R 10%", "3V3_CORE", "GND", "Capacitor_SMD:C_1206_3216Metric_Pad1.33x1.80mm_HandSolder", mpn="GCJ31CR71A226KE01", manufacturer="Murata", note="Effective capacitance at 3.3V/temperature must be verified"),
        passive("C14", "22uF 10V X7R 10%", "3V3_CORE", "GND", "Capacitor_SMD:C_1206_3216Metric_Pad1.33x1.80mm_HandSolder", mpn="GCJ31CR71A226KE01", manufacturer="Murata", note="Effective capacitance at 3.3V/temperature must be verified"),
        passive("R10", "100k", "3V3_CORE", "BUCK_PGOOD", R0603),
        connector("TP1", "TP_BATT_12V", "TestPoint:TestPoint_Pad_D1.5mm", ["BATT_12V_IN"], assembly="DNP", dnp=True),
        connector("TP2", "TP_USB_VBUS", "TestPoint:TestPoint_Pad_D1.5mm", ["USB_VBUS"], assembly="DNP", dnp=True),
        connector("TP3", "TP_VIN_SYS", "TestPoint:TestPoint_Pad_D1.5mm", ["VIN_SYS"], assembly="DNP", dnp=True),
        connector("TP4", "TP_3V3", "TestPoint:TestPoint_Pad_D1.5mm", ["3V3_CORE"], assembly="DNP", dnp=True),
        connector("TP5", "TP_GND", "TestPoint:TestPoint_Pad_D1.5mm", ["GND"], assembly="DNP", dnp=True),
    ]

    esp: list[Part] = [
        Part("U5", "ESP32-S3-WROOM-1U-N16R8", "RF_Module:ESP32-S3-WROOM-1U", [
            ("1", "GND", "GND"), ("2", "3V3", "3V3_CORE"), ("3", "EN", "CHIP_PU"), ("4", "IO4", "1WIRE_DQ_GPIO"),
            ("5", "IO5", "I2C_SDA"), ("6", "IO6", "I2C_SCL"), ("7", "IO7", "TOUCH_RESET_RELEASE"), ("8", "IO15", "SENSOR_EN"),
            ("9", "IO16", "AUTOTERM_TX_3V3"), ("10", "IO17", "AUTOTERM_RX_3V3"), ("11", "IO18", "LATCH_CLR_GPIO_N"), ("12", "IO8", "EPD_BUSY_GPIO"),
            ("13", "IO19/USB_D-", "USB_D_N_ESP"), ("14", "IO20/USB_D+", "USB_D_P_ESP"), ("15", "IO3", None), ("16", "IO46", None),
            ("17", "IO9", "EPD_SCLK_GPIO"), ("18", "IO10", "EPD_SDIO_GPIO"), ("19", "IO11", "EPD_CS_GPIO_N"), ("20", "IO12", "EPD_DC_GPIO"),
            ("21", "IO13", "EPD_RESET_GPIO_N"), ("22", "IO14", "DISPLAY_EN"), ("23", "IO21", "FRONTLIGHT_PWM"), ("24", "IO47", "AUTOTERM_OE"),
            ("25", "IO48", None), ("26", "IO45", None), ("27", "IO0", "BOOT_N"), ("28", "IO35/PSRAM", None),
            ("29", "IO36/PSRAM", None), ("30", "IO37/PSRAM", None), ("31", "IO38", "BUTTON_LED_PWM"), ("32", "IO39", "DIAG_RUN"),
            ("33", "IO40", "USB_HIGH_CURRENT"), ("34", "IO41", "STATUS_LED_1"), ("35", "IO42", "STATUS_LED_2"),
            ("36", "U0RXD/IO44", "U0RXD_TEST"), ("37", "U0TXD/IO43", "U0TXD_RAW"), ("38", "IO2", "TOUCH_INT_N"),
            ("39", "IO1", "BUTTON_N"), ("40", "GND", "GND"), ("41", "EPAD", "GND")],
            mpn="ESP32-S3-WROOM-1U-N16R8", manufacturer="Espressif", datasheet="https://www.espressif.com/sites/default/files/documentation/esp32-s3-wroom-1_wroom-1u_datasheet_en.pdf"),
        passive("C15", "22uF 10V X7R 10%", "3V3_CORE", "GND", "Capacitor_SMD:C_1206_3216Metric_Pad1.33x1.80mm_HandSolder", mpn="GCJ31CR71A226KE01", manufacturer="Murata", note="ESP32 local bulk; effective capacitance must be verified"),
        passive("C16", "22uF 10V X7R 10%", "3V3_CORE", "GND", "Capacitor_SMD:C_1206_3216Metric_Pad1.33x1.80mm_HandSolder", mpn="GCJ31CR71A226KE01", manufacturer="Murata", note="ESP32 local bulk; effective capacitance must be verified"),
        passive("C17", "100nF", "3V3_CORE", "GND", C0603),
        Part("U6", "TPS3808G33QDBVRQ1", SOT236, [("1", "RESET_N", "CHIP_PU"), ("2", "GND", "GND"), ("3", "MR_N", "RESET_MR_N"), ("4", "CT", None), ("5", "SENSE", "3V3_CORE"), ("6", "VDD", "3V3_CORE")], mpn="TPS3808G33QDBVRQ1", manufacturer="Texas Instruments", datasheet="https://www.ti.com/lit/ds/symlink/tps3808.pdf", note="CT intentionally open for fixed nominal 20-ms reset delay"),
        passive("R11", "10k", "3V3_CORE", "CHIP_PU", R0603),
        passive("C18", "1uF", "CHIP_PU", "GND", C0603, note="Espressif EN RC"),
        passive("C19", "100nF", "3V3_CORE", "GND", C0603),
        Part("SW1", "RESET KMR221GLFS", "Button_Switch_SMD:SW_Push_1P1T_NO_CK_KMR2", [("1", "A", "RESET_MR_N"), ("2", "B", "GND")], mpn="KMR221GLFS", manufacturer="C&K"),
        passive("R12", "10k", "3V3_CORE", "RESET_MR_N", R0603),
        Part("SW2", "BOOT KMR221GLFS", "Button_Switch_SMD:SW_Push_1P1T_NO_CK_KMR2", [("1", "A", "BOOT_N"), ("2", "B", "GND")], mpn="KMR221GLFS", manufacturer="C&K"),
        passive("R13", "10k", "3V3_CORE", "BOOT_N", R0603),
        Part("U7", "TPD2EUSB30DRTR", "Package_TO_SOT_SMD:SOT-23-5", [("1", "D1_IN", "USB_D_N_CONN"), ("2", "GND", "GND"), ("3", "D2_IN", "USB_D_P_CONN"), ("4", "D2_OUT", "USB_D_P_PROT"), ("5", "D1_OUT", "USB_D_N_PROT")], mpn="TPD2EUSB30DRTR", manufacturer="Texas Instruments", datasheet="https://www.ti.com/lit/ds/symlink/tpd2eusb30.pdf"),
        passive("R14", "22R", "USB_D_N_PROT", "USB_D_N_ESP", R0603),
        passive("R15", "22R", "USB_D_P_PROT", "USB_D_P_ESP", R0603),
        passive("C40", "10pF C0G DNP", "USB_D_N_ESP", "GND", C0603, assembly="DNP", dnp=True, note="USB SI tuning only; default DNP"),
        passive("C41", "10pF C0G DNP", "USB_D_P_ESP", "GND", C0603, assembly="DNP", dnp=True, note="USB SI tuning only; default DNP"),
        passive("R16", "499R", "U0TXD_RAW", "U0TXD_TEST", R0603),
        passive("R54", "33R", "EPD_SCLK_GPIO", "EPD_SCLK", R0603),
        passive("R55", "33R", "EPD_SDIO_GPIO", "EPD_SDIO_MOSI", R0603),
        passive("R56", "33R", "EPD_CS_GPIO_N", "EPD_CS_N", R0603),
        passive("R57", "33R", "EPD_DC_GPIO", "EPD_DC", R0603),
        passive("R58", "33R", "EPD_RESET_GPIO_N", "EPD_RESET_N", R0603),
        passive("R59", "33R", "EPD_BUSY", "EPD_BUSY_GPIO", R0603),
        passive("C42", "10pF C0G DNP", "EPD_SCLK", "GND", C0603, assembly="DNP", dnp=True, note="SPI edge-rate tuning; default DNP"),
        passive("C43", "10pF C0G DNP", "EPD_SDIO_MOSI", "GND", C0603, assembly="DNP", dnp=True),
        passive("C44", "10pF C0G DNP", "EPD_CS_N", "GND", C0603, assembly="DNP", dnp=True),
        passive("C45", "10pF C0G DNP", "EPD_DC", "GND", C0603, assembly="DNP", dnp=True),
        passive("C46", "10pF C0G DNP", "EPD_RESET_N", "GND", C0603, assembly="DNP", dnp=True),
        connector("TP6", "U0TXD", "TestPoint:TestPoint_Pad_D1.0mm", ["U0TXD_TEST"], assembly="DNP", dnp=True),
        connector("TP7", "U0RXD", "TestPoint:TestPoint_Pad_D1.0mm", ["U0RXD_TEST"], assembly="DNP", dnp=True),
        connector("TP8", "USB_EFUSE_FAULT", "TestPoint:TestPoint_Pad_D1.0mm", ["USB_EFUSE_FAULT_N"], assembly="DNP", dnp=True),
        connector("TP9", "USB_CURRENT_3A", "TestPoint:TestPoint_Pad_D1.0mm", ["USB_CURRENT_3A_N"], assembly="DNP", dnp=True),
        connector("TP23", "CHIP_PU", "TestPoint:TestPoint_Pad_D1.0mm", ["CHIP_PU"], assembly="DNP", dnp=True),
        connector("TP24", "BOOT_N", "TestPoint:TestPoint_Pad_D1.0mm", ["BOOT_N"], assembly="DNP", dnp=True),
    ]
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

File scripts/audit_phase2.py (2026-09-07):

#!/usr/bin/env python3
"""Audit the exported Phase-2 BOM and netlist against the reviewed definition."""

from __future__ import annotations

import csv
import hashlib
import re
import sys
from pathlib import Path

from generate_phase2_schematic import pages, validate_definition


ROOT = Path(__file__).resolve().parents[1]
BOM = ROOT / "output" / "bom" / "LandyHeater-Board-BOM-Phase2.csv"
NETLIST = ROOT / "build" / "reports" / "phase2.net"
REPORT = ROOT / "build" / "reports" / "phase2-audit.txt"
OUTPUT_REPORT = ROOT / "output" / "reports" / "LandyHeater-Board-Audit-Phase2.txt"
NETLIST_COMPARISON_REPORT = ROOT / "output" / "reports" / "LandyHeater-Board-Netlist-Comparison-Phase2.txt"

# Captured from build/reports/phase2-before-rework.net immediately before the
# purely graphical rework requested on 2026-09-07.  The topology digest ignores
# timestamps, titles, properties and net names; it hashes only the partition of
# connected component pins.  This makes it a stable electrical regression gate.
GRAPHICAL_REWORK_BASELINE_RAW_SHA256 = "6077254ad38973092c4b5cefda012bff106fe935b2b8a473ba2dc4fbc516b3cb"
GRAPHICAL_REWORK_BASELINE_TOPOLOGY_SHA256 = "00ce8f7d7237aa13ae732818b4ef832ae0c6ac1b73049995a4f299356ca35dd0"
GRAPHICAL_REWORK_BASELINE_PIN_COUNT = 651
GRAPHICAL_REWORK_BASELINE_NET_COUNT = 175


def balanced_blocks(text: str, marker: str) -> list[str]:
    blocks: list[str] = []
    start = 0
    while True:
        start = text.find(marker, start)
        if start < 0:
            return blocks
        depth = 0
        quoted = False
        escaped = False
        for index in range(start, len(text)):
            char = text[index]
            if escaped:
                escaped = False
            elif char == "\\" and quoted:
                escaped = True
            elif char == '"':
                quoted = not quoted
            elif not quoted:
                if char == "(":
                    depth += 1
                elif char == ")":
                    depth -= 1
                    if depth == 0:
                        blocks.append(text[start:index + 1])
                        start = index + 1
                        break
        else:
            raise ValueError(f"Unbalanced block beginning with {marker!r}")


def exported_net_pins(text: str) -> dict[tuple[str, str], str]:
    result: dict[tuple[str, str], str] = {}
    for block in balanced_blocks(text, "\n\t\t(net"):
        name_match = re.search(r'\(name "([^"]+)"\)', block)
        if not name_match:
            continue
        name = name_match.group(1)
        for node in balanced_blocks(block, "\n\t\t\t(node"):
            ref = re.search(r'\(ref "([^"]+)"\)', node)
            pin = re.search(r'\(pin "([^"]+)"\)', node)
            if ref and pin:
                result[(ref.group(1), pin.group(1))] = name
    return result


def topology_digest(pin_nets: dict[tuple[str, str], str]) -> tuple[str, int, int]:
    """Hash electrical connectivity independently of generated net names."""
    groups: dict[str, set[tuple[str, str]]] = {}
    for pin, net in pin_nets.items():
        groups.setdefault(net, set()).add(pin)
    canonical = "\n".join(
        sorted(",".join(f"{ref}.{pin}" for ref, pin in sorted(group)) for group in groups.values())
    ) + "\n"
    return hashlib.sha256(canonical.encode("utf-8")).hexdigest(), len(pin_nets), len(groups)


def main() -> int:
    definitions = pages()
    validate_definition(definitions)
    parts = [part for _title, _file, page_parts, _notes in definitions for part in page_parts]
    blockers: list[str] = []
    failures: list[str] = []
    comparison_lines: list[str] = []

    if not BOM.is_file() or not NETLIST.is_file():
        failures.append("Exportierte BOM oder Netzliste fehlt; zuerst make export-phase2 ausführen.")
    else:
        rows = list(csv.DictReader(BOM.open(encoding="utf-8", newline="")))
        expected_fields = {"Reference", "Value", "Footprint", "Datasheet", "Manufacturer", "MPN", "Assembly", "Notes"}
        if not rows or set(rows[0]) != expected_fields:
            failures.append("BOM-Spalten entsprechen nicht dem festgelegten Phase-2-Schema.")
        for row in rows:
            if not row["Footprint"].strip():
                failures.append(f"BOM-Gruppe {row['Reference']} hat keinen Footprint.")
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

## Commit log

2026-09-06 Resolve ESP32 display integration requirements
2026-09-06 Add on-board energy flow diagnostics
2026-09-06 Document phased PCB development plan
2026-09-06 Complete KiCad phase 0 project scaffold
    [LandyHeater-Board.kicad_pcb, LandyHeater-Board.kicad_sch]
2026-09-06 Complete phase 2 schematic review
    [01_Power_Input_USB.kicad_sch, 02_ESP32_USB_Reset.kicad_sch, 03_Display_EPaper.kicad_sch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]
2026-09-06 Mark phase 2 schematic for readability rework
2026-09-06 Rebuild phase 2 schematic by function
    [01_Power_Input_USB.kicad_sch, 02_ESP32_USB_Reset.kicad_sch, 03_Display_EPaper.kicad_sch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]
2026-09-06 Refresh phase 2 review exports
    [LandyHeater-Board-BOM-Phase2.csv]
2026-09-06 Store final verified schematic PDF
2026-09-07 Redraw phase 2 schematic with visible functional wiring
    [01_Power_Input_USB.kicad_sch, 02_ESP32_USB_Reset.kicad_sch, 03_Display_EPaper.kicad_sch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]
2026-10-12 Rebuild Rev A schematic from a single verified circuit definition
    - Requirements list extracted from spec v1.6 (docs/Anforderungsliste_RevA.md)
    - New canonical circuit in scripts/rebuild/design.py with LCSC numbers
    (all stock-checked 2026-10-12) and generated 6-sheet KiCad schematic
    - Power path kept on TI's automotive reference (LM74720-Q1 Fig. 9-1) with
    hold-up capacitor; buck moved to LMR33630C (2.1 MHz) for availability
    - Fixes found during datasheet re-check: TPD2EUSB30 pinout, TPS25947 EN
    overvoltage and phantom EPAD, mirrored RV-3028 footprint, Good Display
    VSL capacitor, AL8861 VSET default, missing AUTOTERM_5V ESD, LED wire
    short-circuit protection
    - ERC 0 violations; expo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
2026-10-12 Place Rev A board: 4-layer stackup, zones, two-sided placement
    Generated by scripts/rebuild/gen_pcb.py from the same circuit definition.
    Pre-route DRC: 0 errors, schematic parity: 0 issues.
